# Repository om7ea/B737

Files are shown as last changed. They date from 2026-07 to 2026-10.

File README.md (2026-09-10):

# Boeing 737 Overhead Panel – Manufacturing Files

This repository contains supplementary manufacturing files for the corresponding MakerWorld project. Additional files and resources will be added gradually as new models are published on MakerWorld.

> **Note**
> This repository contains only supplementary manufacturing files. The 3D printable parts are available on MakerWorld - see the [model list](docs/models/README.md) for a link to each one.

## Photos

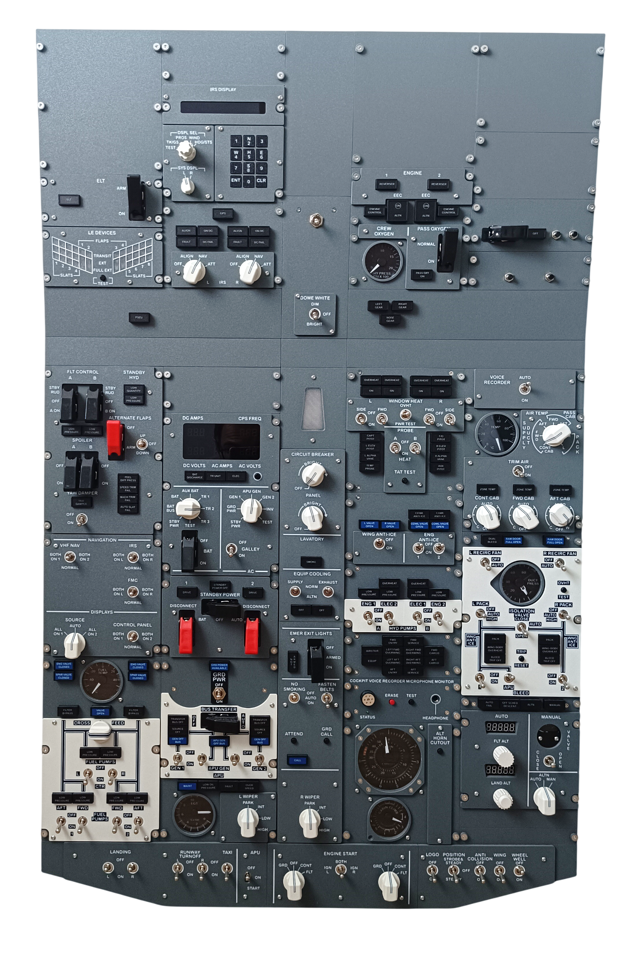
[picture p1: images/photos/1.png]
<span>
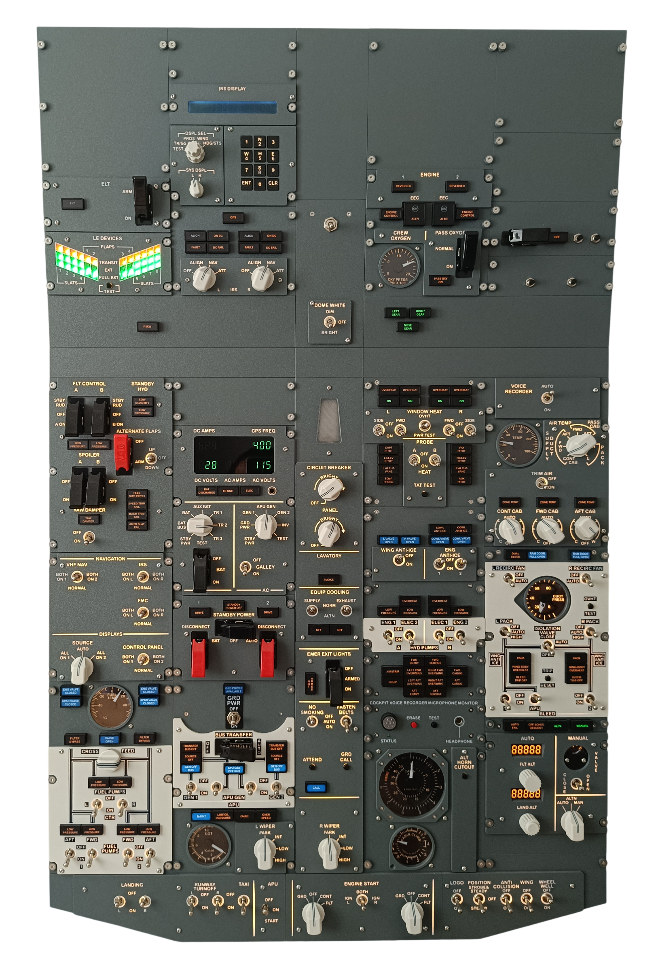
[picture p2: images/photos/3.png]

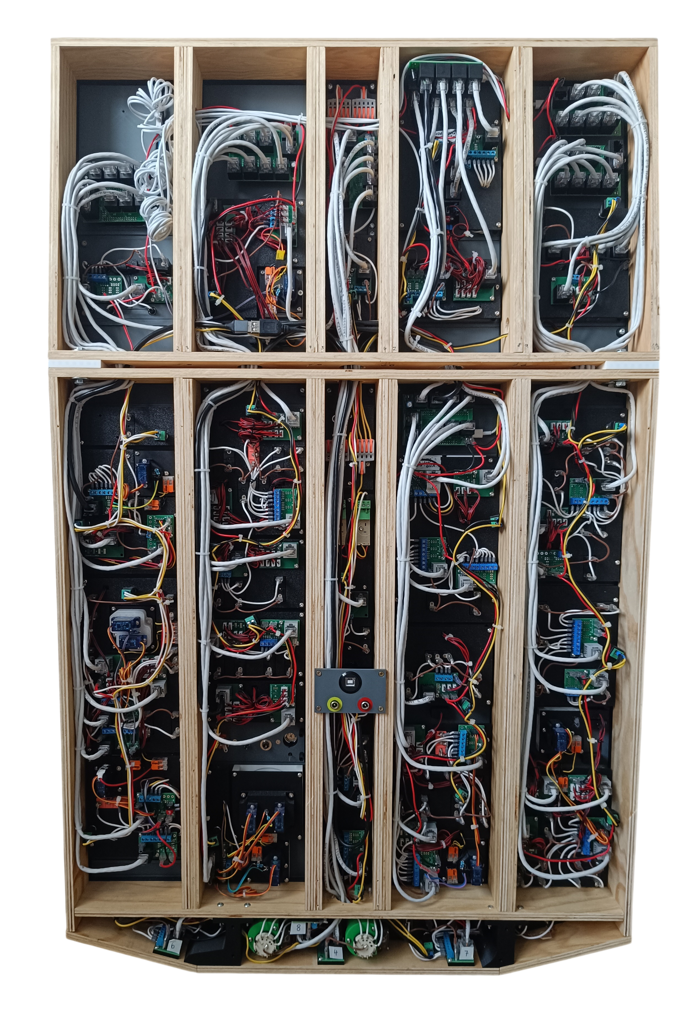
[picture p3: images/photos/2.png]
</span>

---

## How It Works

All electronics are enclosed inside the panel and connected to an internal USB hub, so the finished panel needs just **one USB cable to the PC** - plus its own power supplies.

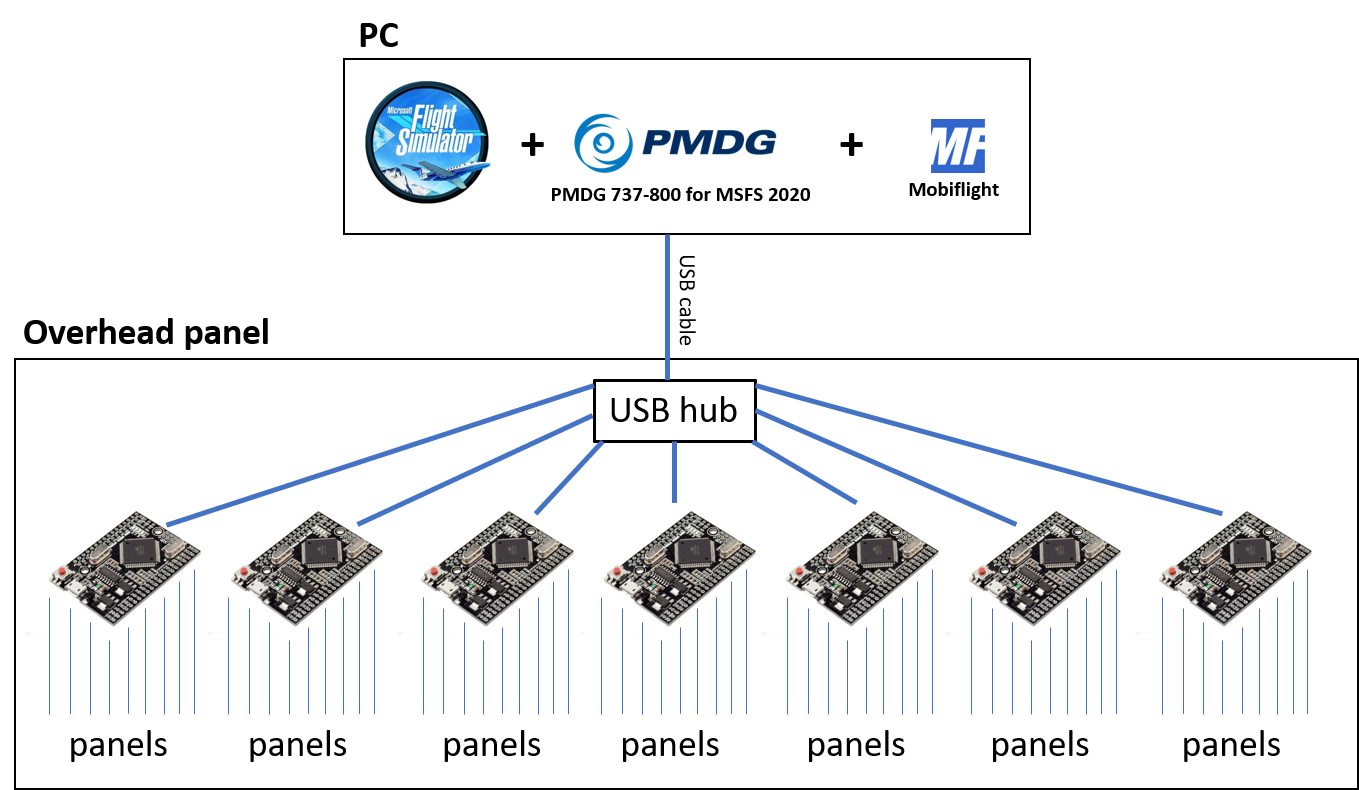
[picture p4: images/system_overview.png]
System overview diagram


**On the PC:** Microsoft Flight Simulator 2020 + PMDG 737-800 + MobiFlight. MobiFlight maps each switch, button and LED to a PMDG variable through its graphical interface, so **no programming is required**.

**Inside the panel:** 7× **Mega 2560 PRO MINI** boards, each driving one group of panels, all connected to an internal USB hub. Panels attach to the boards through RJ45 connectors using standard Ethernet patch cables.

**Power:** the panel is powered externally, not through the USB cable. It uses **two separate power supplies** - a **12 V** supply for the backlighting and a **5 V** supply for the rest of the electronics.

📖 **[Full system overview →](docs/system-overview.md)**

---

## Documentation

| | Contents |
|---|---|
| ⚙️ **[System Overview](docs/system-overview.md)** | How the panel connects to the simulator - software, boards, wiring |
| 🔌 **[PCB Manufacturing Files](docs/pcb/README.md)** | Gerber downloads, BOM and assembly for each PCB design |
| 🖨️ **[UV Print Files](docs/uv-print.md)** | Printable panel graphics and printing instructions |
| ✂️ **[CNC Cut Files](docs/cnc-cut.md)** | Acrylic windows for the gauges and the meter panel, with the DXF files |
| 🛩️ **[Models](docs/models/README.md)** | Build notes for the frame, the shared models and each panel |
| 🎨 **[Filaments](docs/filaments.md)** | The filaments I used and their colours |
| 🖥️ **[MobiFlight Configuration](docs/mobiflight.md)** | The complete MobiFlight configuration - board definitions and the simulator mapping |

---

## Support the Project

This project is completely free and will continue to be released free of charge.

Designing, testing, documenting, and maintaining the complete Boeing 737 Overhead Panel requires a significant amount of time. If you would like to support its continued development, you can make a voluntary contribution.

### How Your Support Helps

I'm saving for a ProSim737 license, a professional simulator software package that would greatly enhance my home cockpit. Every contribution brings me one step closer to reaching that goal.

✈️ **Support via PayPal:**
https://paypal.me/om7ea

Thank you to everyone who supports this project!

---

## License

This repository contains supplementary resources for the corresponding MakerWorld project.

### Files corresponding to the MakerWorld model

Files that are part of the corresponding MakerWorld model are distributed under the MakerWorld Standard Digital File License associated with that model. No additional rights are granted by this repository.

Please refer to the corresponding MakerWorld project page for the complete license terms.

### Repository-exclusive files

Some files in this repository are provided exclusively on GitHub and are not part of the MakerWorld model. Unless otherwise stated, these files are licensed separately and may not be copied, modified, redistributed, or used for commercial purposes without the author's prior written permission.

Copyright © 2026 Marek Antoška (OM7EA). All rights reserved.

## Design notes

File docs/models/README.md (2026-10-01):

# Models

Build notes for the individual models. The printable parts themselves are published on MakerWorld - the pages linked below contain the print settings and assembly instructions for each model.

[← Back to main page](../../README.md)

The models are listed in the order in which they were released on MakerWorld.

---

## Frame and Shared Models

These are not panels. The frame carries the whole overhead; the rest are components and instruments that go into the panels - some of them into several.

<table>
<thead>
<tr>
<th></th>
<th>Model</th>
<th>MakerWorld</th>
<th>Build notes</th>
</tr>
</thead>
<tbody>
<tr>
<td></td>
<td>Main Frame</td>
<td><a href="https://makerworld.com/en/models/3179915-boeing-737-overhead-frame">Model</a></td>
<td>🚧</td>
</tr>
</tbody>
<tbody>
<tr>
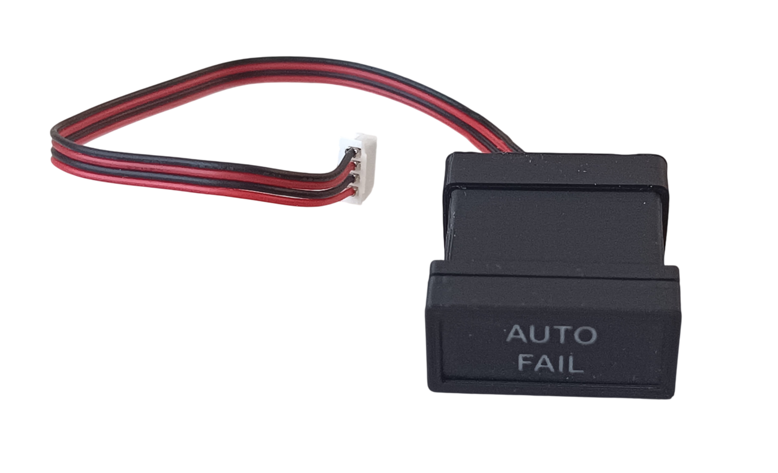
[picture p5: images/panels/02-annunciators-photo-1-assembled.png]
<td></td>
<td>Annunciators</td>
<td><a href="https://makerworld.com/en/models/3121595-boeing-737-overhead-annunciators">Model</a></td>
<td><a href="02-annunciators.md">Notes</a></td>
</tr>
</tbody>
<tbody>
<tr>
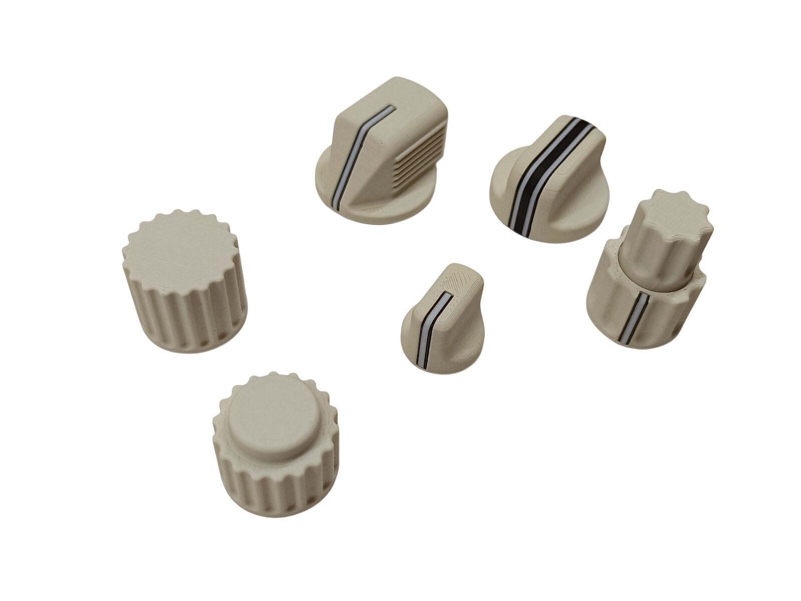
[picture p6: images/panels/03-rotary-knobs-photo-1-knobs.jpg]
<td></td>
<td>Rotary Knobs</td>
<td><a href="https://makerworld.com/en/models/3066127-boeing-737-overhead-rotary-knobs">Model</a></td>
<td><a href="03-rotary-knobs.md">Notes</a></td>
</tr>
</tbody>
<tbody>
<tr>
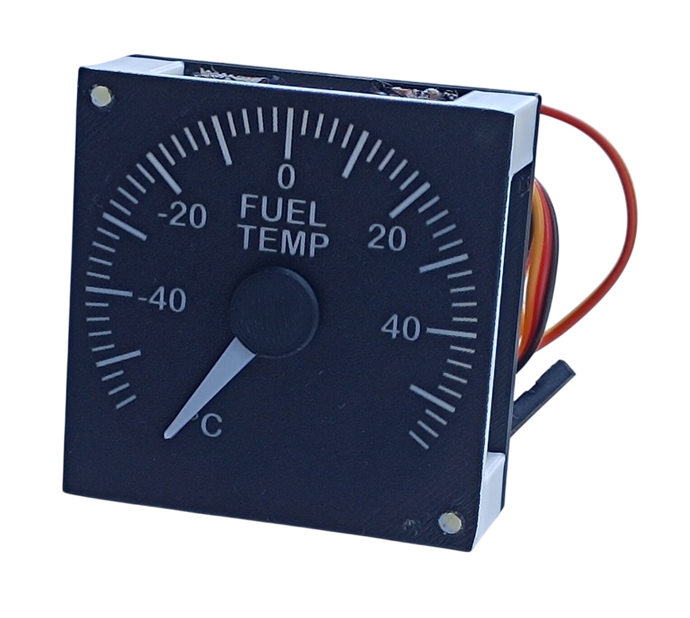
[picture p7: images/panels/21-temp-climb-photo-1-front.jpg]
<td></td>
<td>Temperature and Climb Gauges</td>
<td><a href="https://makerworld.com/en/models/3251829-boeing-737-overhead-temperature-and-climb-gauges">Model</a></td>
<td><a href="21-temperature-and-climb-gauges.md">Notes</a></td>
</tr>
</tbody>
<tbody>
<tr>
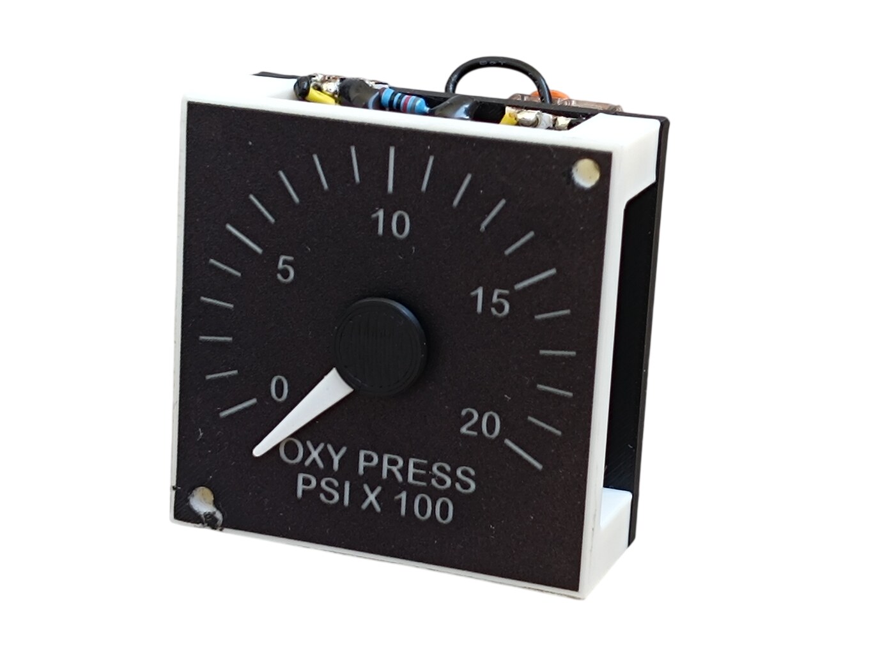
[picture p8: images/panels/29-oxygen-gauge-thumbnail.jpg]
<td></td>
<td>Oxygen Pressure Gauge</td>
<td><a href="https://makerworld.com/en/models/3309881-boeing-737-overhead-oxygen-pressure-gauge">Model</a></td>
<td><a href="29-oxygen-pressure-gauge.md">Notes</a></td>
</tr>
</tbody>
<tbody>
<tr>
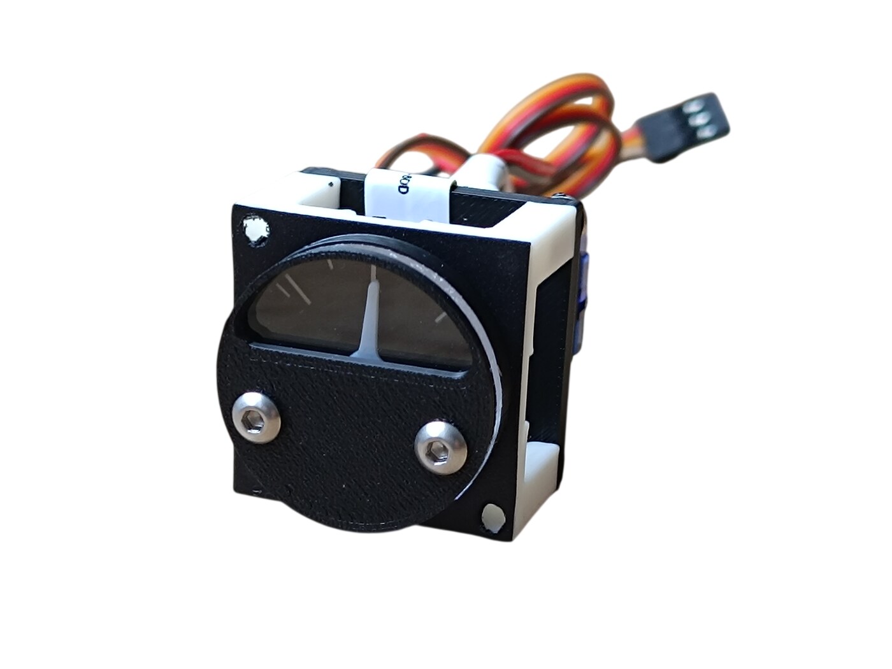
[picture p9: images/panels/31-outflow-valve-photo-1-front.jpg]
<td></td>
<td>Outflow Valve Gauge</td>
<td><a href="https://makerworld.com/en/models/3323749-boeing-737-overhead-outflow-valve-gauge">Model</a></td>
<td><a href="31-outflow-valve-gauge.md">Notes</a></td>
</tr>
</tbody>
<tbody>
<tr>
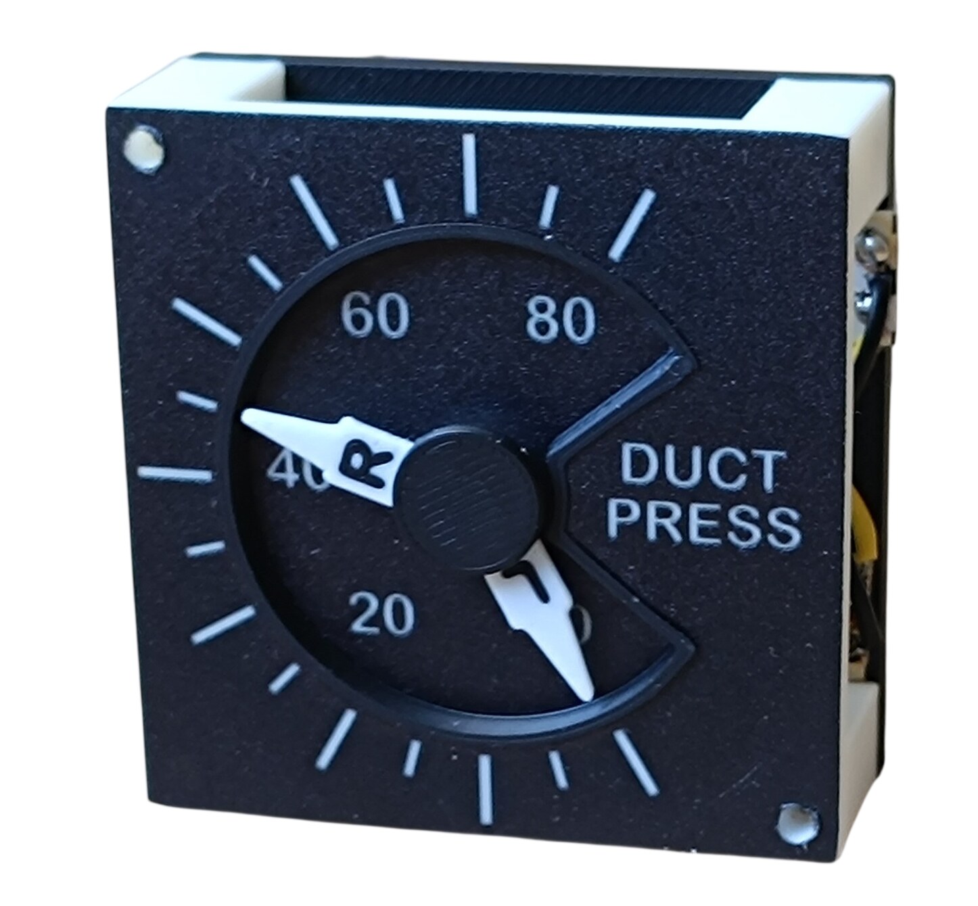
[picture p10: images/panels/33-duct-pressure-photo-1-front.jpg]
<td></td>
<td>Duct Pressure Gauge</td>
<td><a href="https://makerworld.com/en/models/3330434-boeing-737-overhead-duct-pressure-gauge">Model</a></td>
<td><a href="33-duct-pressure-gauge.md">Notes</a></td>
</tr>
</tbody>
<tbody>
<tr>
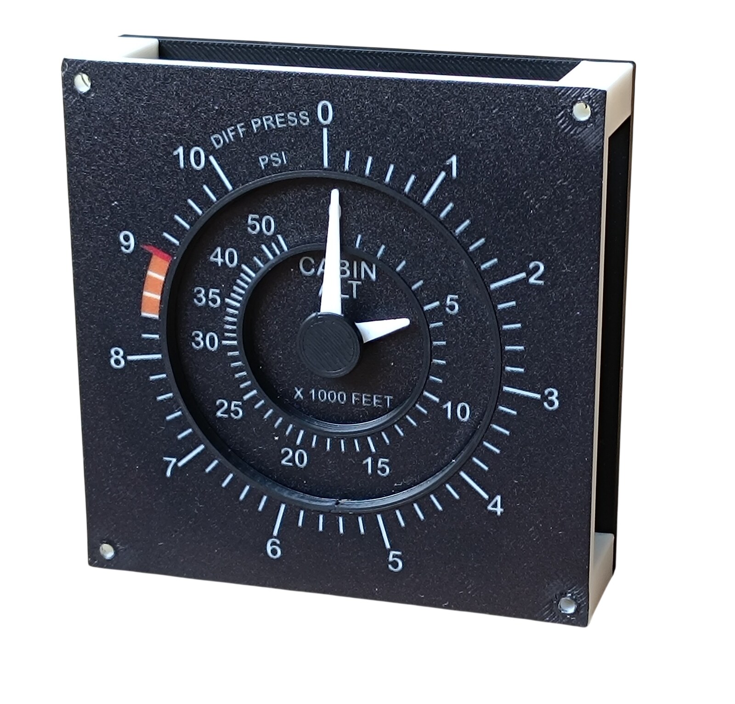
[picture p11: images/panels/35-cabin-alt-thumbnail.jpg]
<td></td>
<td>Cabin Alt / Diff Press Gauge</td>
<td><a href="https://makerworld.com/en/models/3334561-boeing-737-overhead-cabin-alt-diff-press-gauge">Model</a></td>
<td><a href="35-cabin-alt-diff-press-gauge.md">Notes</a></td>
</tr>
</tbody>
<tbody>
<tr>
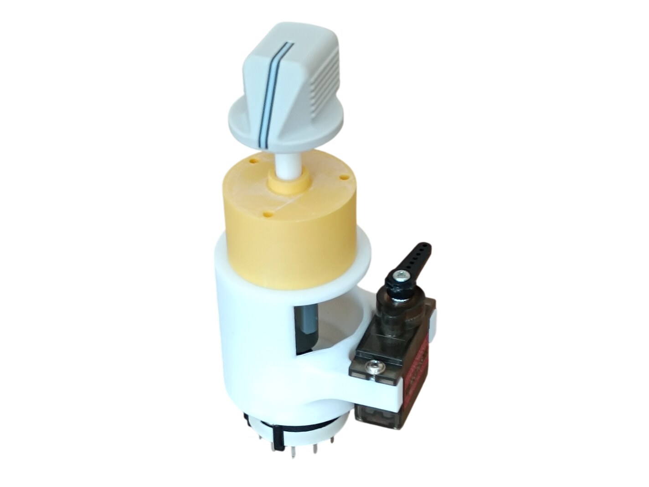
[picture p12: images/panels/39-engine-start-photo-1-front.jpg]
<td></td>
<td>Engine Start Switch</td>
<td><a href="https://makerworld.com/en/models/3375879-boeing-737-overhead-engine-start-switch">Model</a></td>
<td><a href="39-engine-start-switch.md">Notes</a></td>
</tr>
</tbody>
<tbody>
<tr>
<td></td>
<td>Backlight Blocking Strips</td>
<td>🚧</td>
<td>🚧</td>
</tr>
</tbody>
</table>

---

## Panels

<table>
<thead>
<tr>
<th></th>
<th>Panel</th>
<th>MakerWorld</th>
<th>Build notes</th>
</tr>
</thead>
<tbody>
<tr>
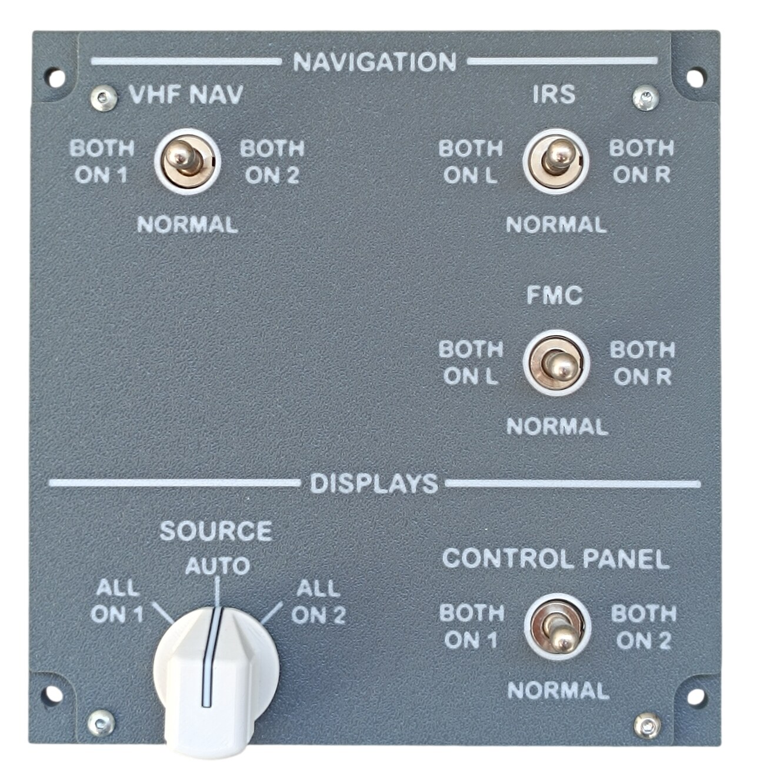
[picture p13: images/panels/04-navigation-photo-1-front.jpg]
<td></td>
<td>Navigation Panel</td>
<td><a href="https://makerworld.com/en/models/2985636-boeing-737-overhead-navigation-panel">Model</a></td>
<td><a href="04-navigation-panel.md">Notes</a></td>
</tr>
</tbody>
<tbody>
<tr>
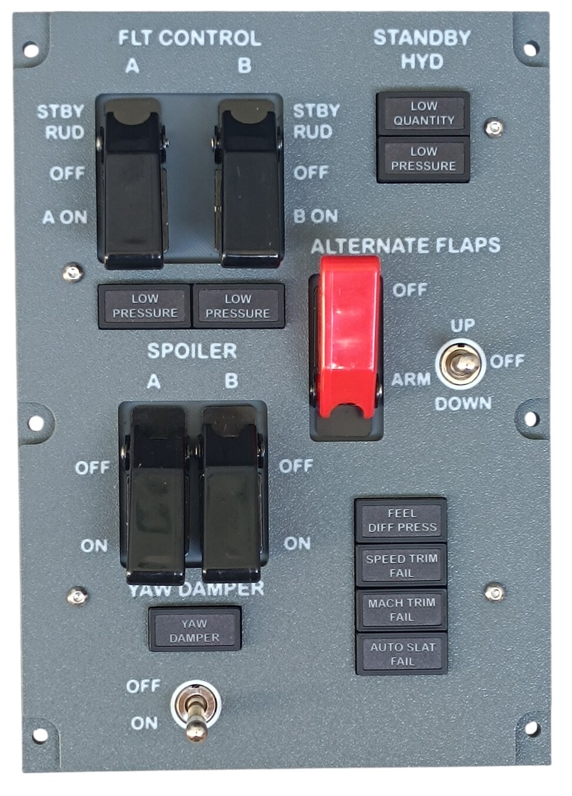
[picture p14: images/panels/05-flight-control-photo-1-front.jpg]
<td></td>
<td>Flight Control Panel</td>
<td><a href="https://makerworld.com/en/models/3153234-boeing-737-overhead-flight-control-panel">Model</a></td>
<td><a href="05-flight-control-panel.md">Notes</a></td>
</tr>
</tbody>
<tbody>
<tr>
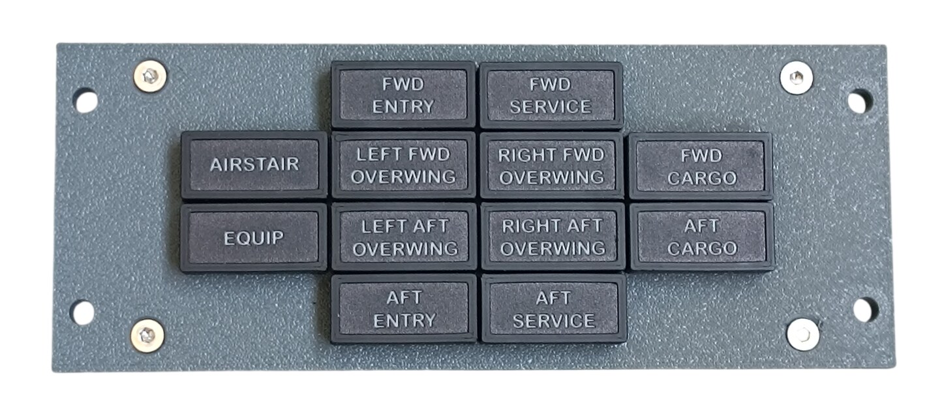
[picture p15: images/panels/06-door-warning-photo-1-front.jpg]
<td></td>
<td>Door Warning Panel</td>
<td><a href="https://makerworld.com/en/models/3163604-boeing-737-overhead-door-warning-panel">Model</a></td>
<td><a href="06-door-warning-panel.md">Notes</a></td>
</tr>
</tbody>
<tbody>
<tr>
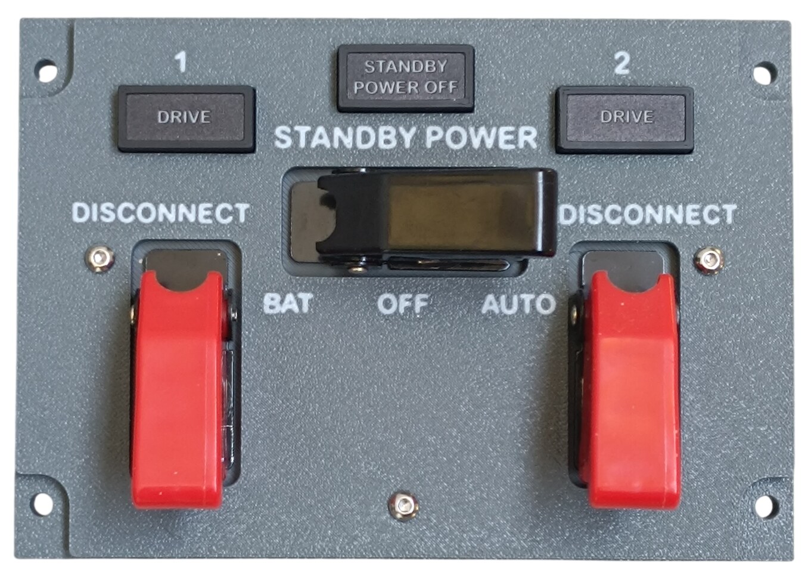
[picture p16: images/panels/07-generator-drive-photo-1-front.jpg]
<td></td>
<td>Generator Drive and Standby Power Panel</td>
<td><a href="https://makerworld.com/en/models/3163662-boeing-737-overhead-generator-drive-panel">Model</a></td>
<td><a href="07-generator-drive-panel.md">Notes</a></td>
</tr>
</tbody>
<tbody>
<tr>
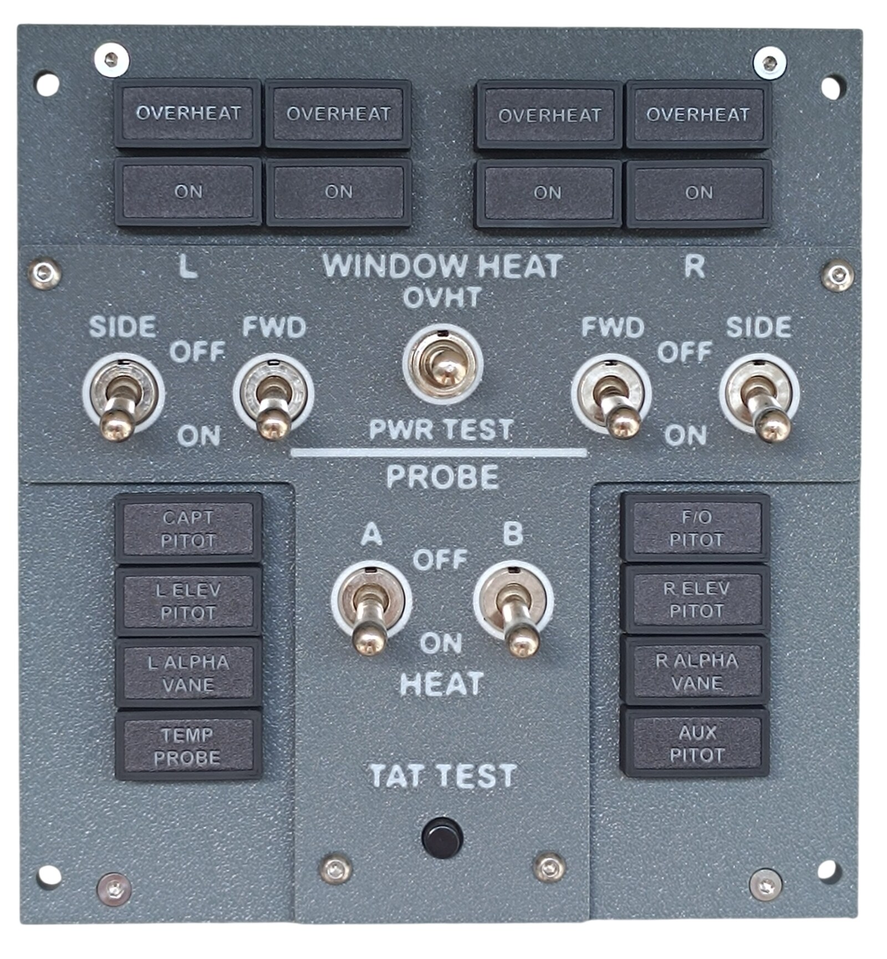
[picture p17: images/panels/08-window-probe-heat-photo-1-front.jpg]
<td></td>
<td>Window and Probe Heat Panel</td>
<td><a href="https://makerworld.com/en/models/3196345-boeing-737-overhead-window-and-probe-heat-panel">Model</a></td>
<td><a href="08-window-and-probe-heat-panel.md">Notes</a></td>
</tr>
</tbody>
<tbody>
<tr>
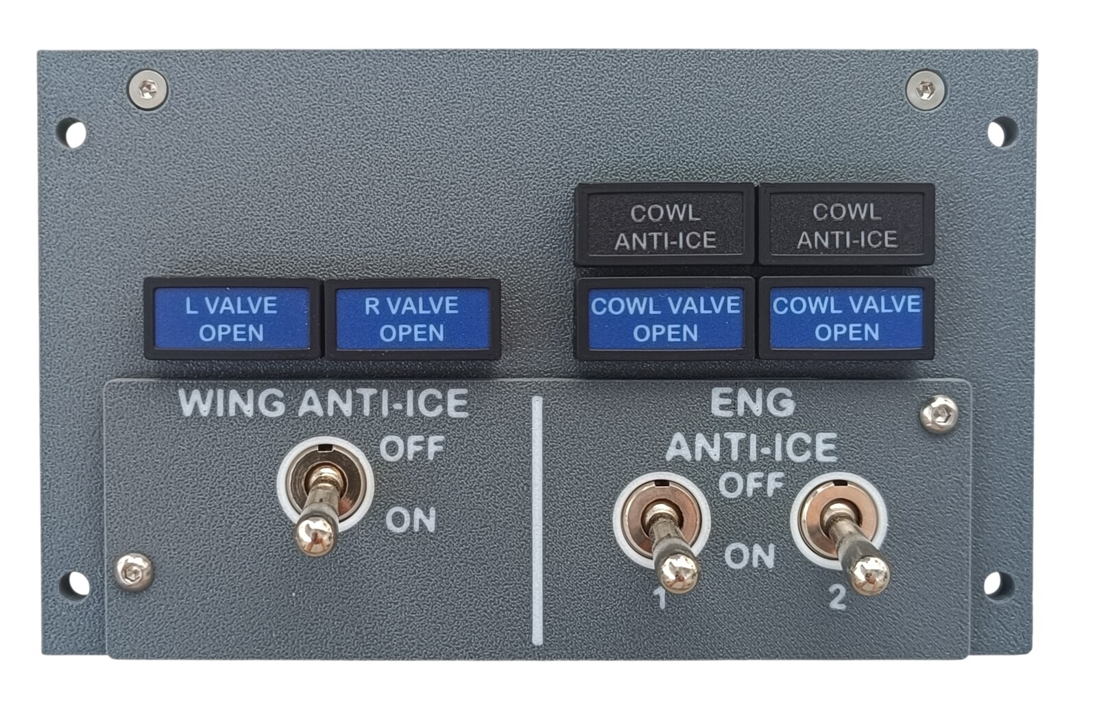
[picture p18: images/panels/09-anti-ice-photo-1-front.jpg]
<td></td>
<td>Anti-ice Panel</td>
<td><a href="https://makerworld.com/en/models/3197814-boeing-737-overhead-anti-ice-panel">Model</a></td>
<td><a href="09-anti-ice-panel.md">Notes</a></td>
</tr>
</tbody>
<tbody>
<tr>
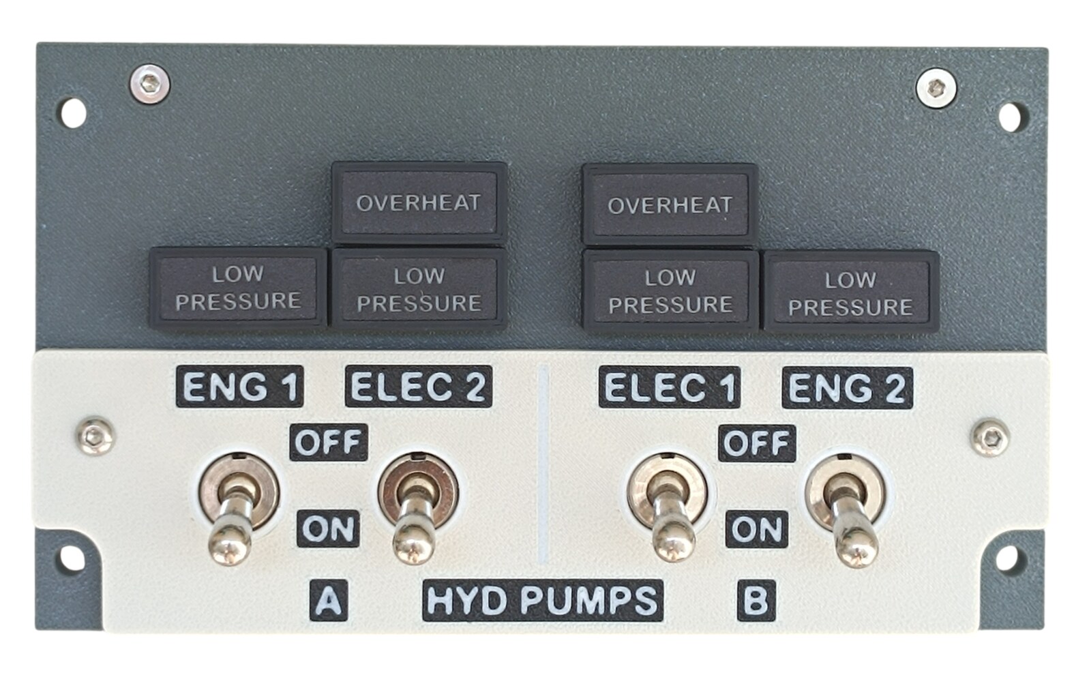
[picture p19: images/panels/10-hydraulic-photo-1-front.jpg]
<td></td>
<td>Hydraulic Control Panel</td>
<td><a href="https://makerworld.com/en/models/3212634-boeing-737-overhead-hydraulic-control-panel">Model</a></td>
<td><a href="10-hydraulic-control-panel.md">Notes</a></td>
</tr>
</tbody>
<tbody>
<tr>
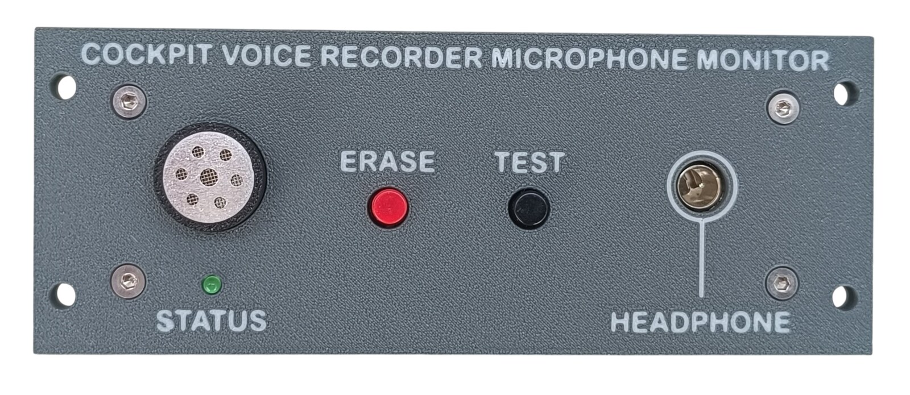
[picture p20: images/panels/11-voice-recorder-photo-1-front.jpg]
<td></td>
<td>Voice Recorder Monitor</td>
<td><a href="https://makerworld.com/en/models/3212900-boeing-737-overhead-voice-recorder-monitor">Model</a></td>
<td><a href="11-voice-recorder-monitor.md">Notes</a></td>
</tr>
</tbody>
<tbody>
<tr>
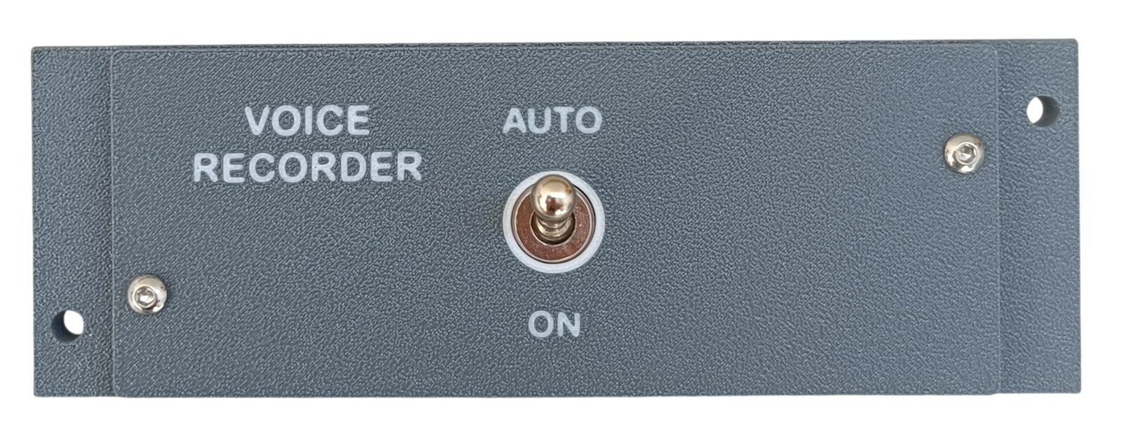
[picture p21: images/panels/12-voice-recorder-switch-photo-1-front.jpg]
<td></td>
<td>Voice Recorder Switch</td>
<td><a href="https://makerworld.com/en/models/3214222-boeing-737-overhead-voice-recorder-switch">Model</a></td>
<td><a href="12-voice-recorder-switch.md">Notes</a></td>
</tr>
</tbody>
<tbody>
<tr>
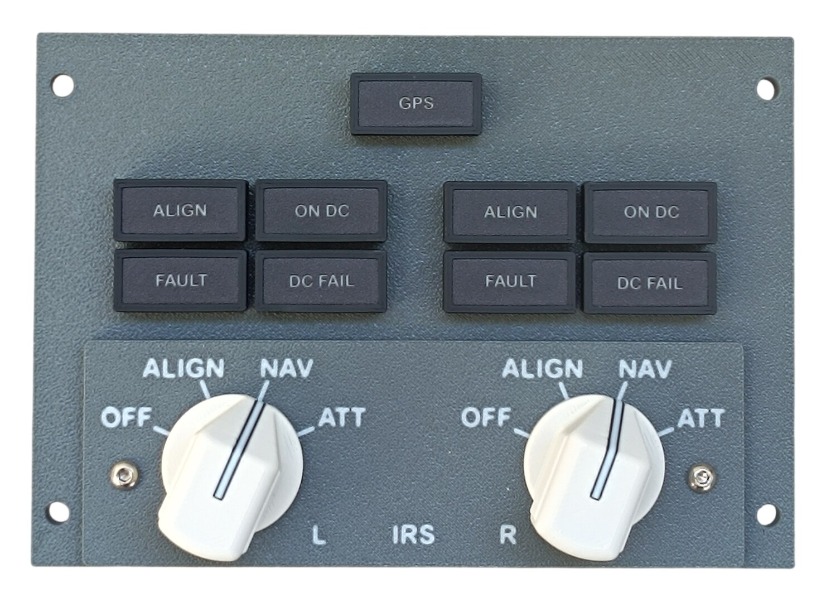
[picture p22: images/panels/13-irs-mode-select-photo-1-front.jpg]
<td></td>
<td>IRS Mode Select Unit</td>
<td><a href="https://makerworld.com/en/models/3214377-boeing-737-overhead-irs-mode-select-unit">Model</a></td>
<td><a href="13-irs-mode-select-unit.md">Notes</a></td>
</tr>
</tbody>
<tbody>
<tr>
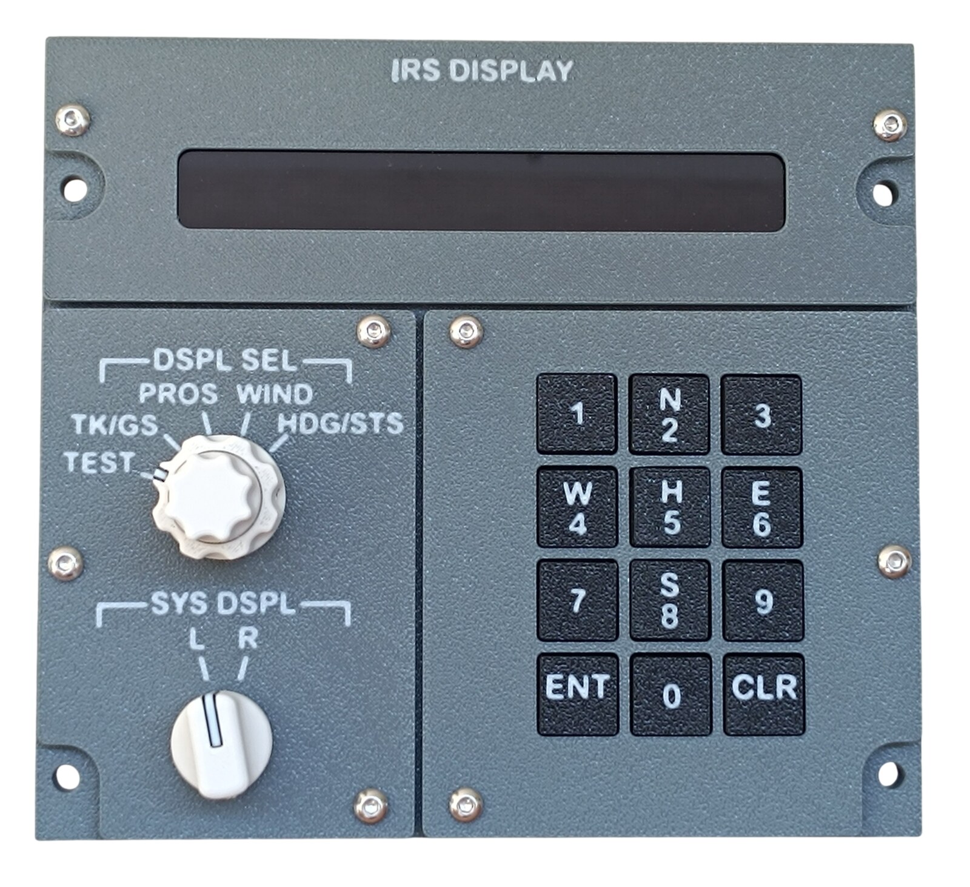
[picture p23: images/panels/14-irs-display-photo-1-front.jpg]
<td></td>
<td>IRS Display Unit</td>
<td><a href="https://makerworld.com/en/models/3222680-boeing-737-overhead-irs-display-unit">Model</a></td>
<td><a href="14-irs-display-unit.md">Notes</a></td>
</tr>
</tbody>
<tbody>
<tr>
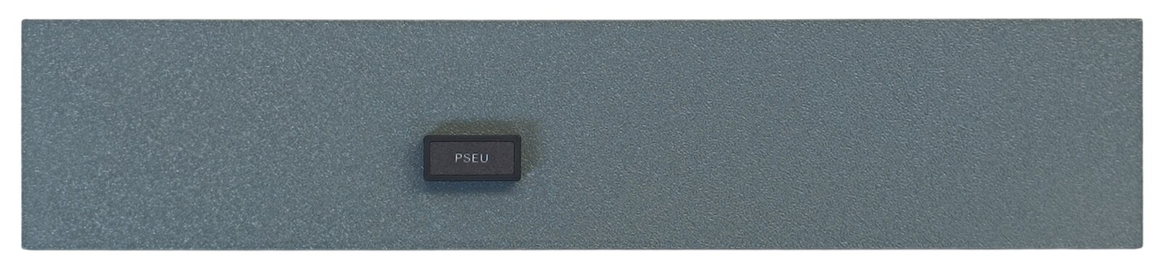
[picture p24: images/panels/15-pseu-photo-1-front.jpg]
<td></td>
<td>PSEU Panel</td>
<td><a href="https://makerworld.com/en/models/3223471-boeing-737-overhead-pseu-panel">Model</a></td>
<td><a href="15-pseu-panel.md">Notes</a></td>
</tr>
</tbody>
<tbody>
<tr>
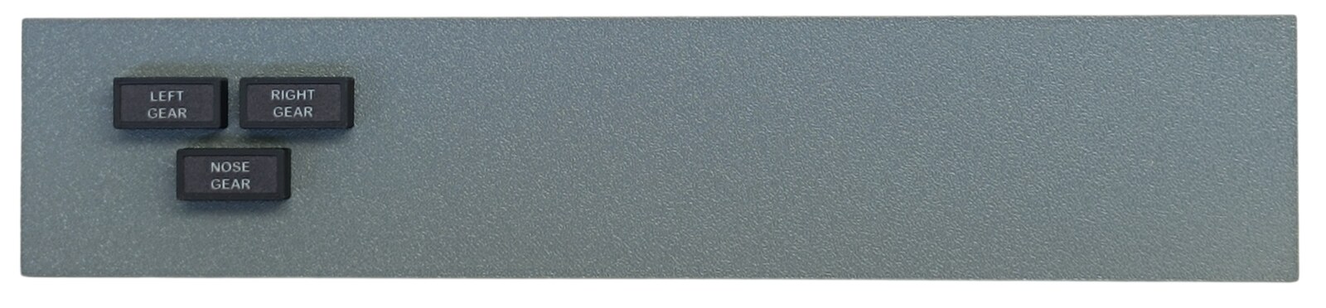
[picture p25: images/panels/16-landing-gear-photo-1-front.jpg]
<td></td>
<td>Landing Gear Indicator Panel</td>
<td><a href="https://makerworld.com/en/models/3223506-boeing-737-overhead-landing-gear-indicator-panel">Model</a></td>
<td><a href="16-landing-gear-indicator-panel.md">Notes</a></td>
</tr>
</tbody>
<tbody>
<tr>
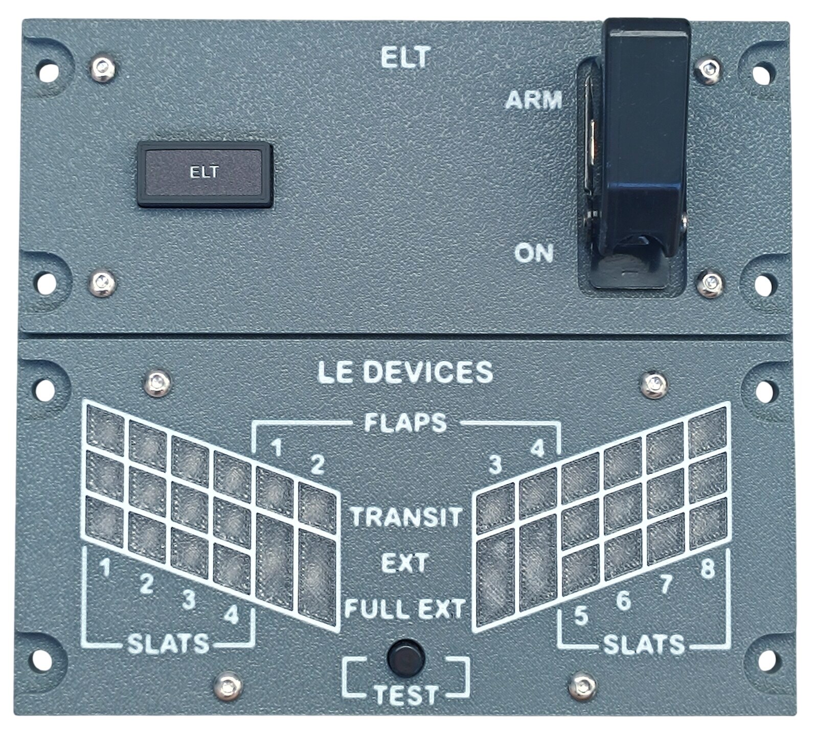
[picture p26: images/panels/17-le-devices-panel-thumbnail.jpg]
<td></td>
<td>LE Devices and ELT Panel</td>
<td><a href="https://makerworld.com/en/models/3233836-boeing-737-overhead-le-devices-and-elt-panel">Model</a></td>
<td><a href="17-le-devices-and-elt-panel.md">Notes</a></td>
</tr>
</tbody>
<tbody>
<tr>
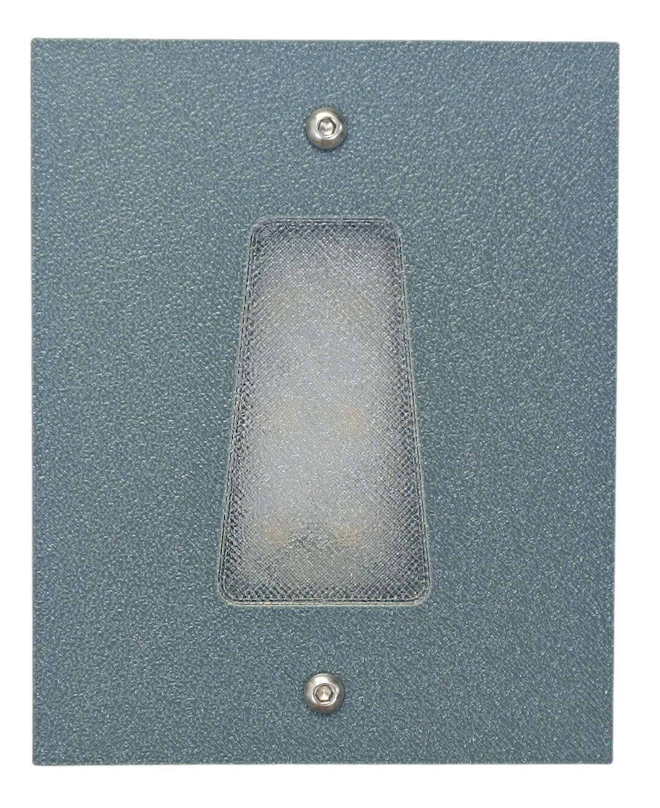
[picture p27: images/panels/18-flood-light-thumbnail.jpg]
<td></td>
<td>Flood Light</td>
<td><a href="https://makerworld.com/en/models/3237863-boeing-737-overhead-flood-light">Model</a></td>
<td><a href="18-flood-light.md">Notes</a></td>
</tr>
</tbody>
<tbody>
<tr>
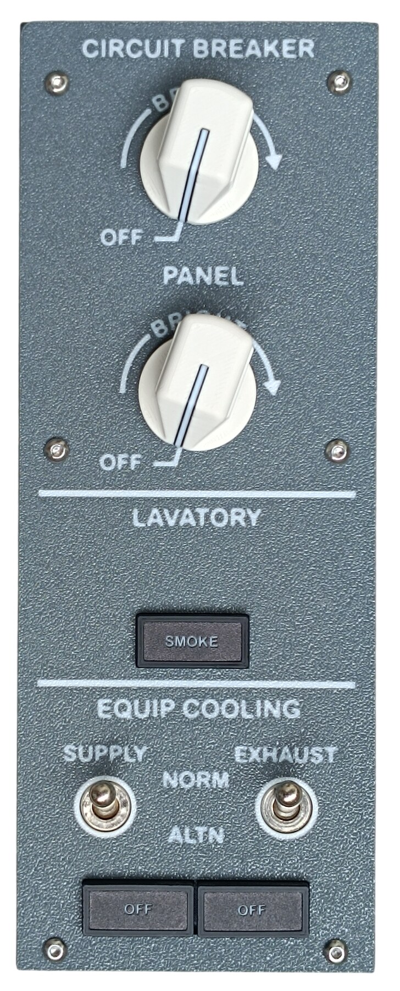
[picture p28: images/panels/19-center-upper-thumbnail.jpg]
<td></td>
<td>Center Upper Panel</td>
<td><a href="https://makerworld.com/en/models/3238245-boeing-737-overhead-center-upper-panel">Model</a></td>
<td><a href="19-center-upper-panel.md">Notes</a></td>
</tr>
</tbody>
<tbody>
<tr>
<td></td>
<td>Center Lower Panel</td>
<td><a href="https://makerworld.com/en/models/3238455-boeing-737-overhead-center-lower-panel">Model</a></td>
<td><a href="20-center-lower-panel.md">Notes</a></td>
</tr>
</tbody>
<tbody>
<tr>
<td></td>
<td>Fuel Control Panel</td>
<td><a href="https://makerworld.com/en/models/3260961-boeing-737-overhead-fuel-control-panel">Model</a></td>
<td><a href="22-fuel-control-panel.md">Notes</a></td>
</tr>
</tbody>
<tbody>
<tr>
<td></td>
<td>Generator Bus Panel</td>
<td><a href="https://makerworld.com/en/models/3275951-boeing-737-overhead-generator-bus-panel">Model</a></td>
<td><a href="23-generator-bus-panel.md">Notes</a></td>
</tr>
</tbody>
<tbody>
<tr>
<td></td>
<td>Air Conditioning Control Panel</td>
<td><a href="https://makerworld.com/en/models/3286939-boeing-737-overhead-air-conditioning-panel">Model</a></td>
<td><a href="24-air-conditioning-control-panel.md">Notes</a></td>
</tr>
</tbody>
<tbody>
<tr>
<td></td>
<td>Pressurization Altitude Info</td>
<td><a href="https://makerworld.com/en/models/3287240-boeing-737-overhead-pressurization-altitude-info">Model</a></td>
<td><a href="25-pressurization-altitude-info.md">Notes</a></td>
</tr>
</tbody>
<tbody>
<tr>
<td></td>
<td>AC and DC Meter Panel</td>
<td><a href="https://makerworld.com/en/models/3288999-boeing-737-overhead-ac-and-dc-meter-panel">Model</a></td>
<td><a href="26-ac-and-dc-meter-panel.md">Notes</a></td>
</tr>
</tbody>
<tbody>
<tr>
<td></td>
<td>Interphone and Dome Panel</td>
<td><a href="https://makerworld.com/en/models/3309341-boeing-737-overhead-interphone-and-dome-panel">Model</a></td>
<td><a href="27-interphone-and-dome-panel.md">Notes</a></td>
</tr>
</tbody>
<tbody>
<tr>
<td></td>
<td>Recorder and Stall Panel</td>
<td><a href="https://makerworld.com/en/models/3309626-boeing-737-overhead-recorder-and-stall-panel">Model</a></td>
<td><a href="28-recorder-and-stall-panel.md">Notes</a></td>
</tr>
</tbody>
<tbody>
<tr>
<td></td>
<td>Engine and Oxygen Panel</td>
<td><a href="https://makerworld.com/en/models/3311720-boeing-737-overhead-engine-and-oxygen-panel">Model</a></td>
<td><a href="30-engine-and-oxygen-panel.md">Notes</a></td>
</tr>
</tbody>
<tbody>
<tr>
<td></td>
<td>Cabin Pressure Control Panel</td>
<td><a href="https://makerworld.com/en/models/3324181-boeing-737-overhead-cabin-pressure-control-panel">Model</a></td>
<td><a href="32-cabin-pressure-control-panel.md">Notes</a></td>
</tr>
</tbody>
<tbody>
<tr>
<td></td>
<td>Bleed Air Control Panel</td>
<td><a href="https://makerworld.com/en/models/3332584-boeing-737-overhead-bleed-air-control-panel">Model</a></td>
<td><a href="34-bleed-air-control-panel.md">Notes</a></td>
</tr>
</tbody>
<tbody>
<tr>
<td></td>
<td>Cabin Altitude Panel</td>
<td><a href="https://makerworld.com/en/models/3342633-boeing-737-overhead-cabin-altitude-panel">Model</a></td>
<td><a href="36-cabin-altitude-panel.md">Notes</a></td>
</tr>
</tbody>
<tbody>
<tr>
<td></td>
<td>Left Light Panel</td>
<td><a href="https://makerworld.com/en/models/3350617-boeing-737-overhead-left-light-panel">Model</a></td>
<td><a href="37-left-light-panel.md">Notes</a></td>
</tr>
</tbody>
<tbody>
<tr>
<td></td>
<td>Right Light Panel</td>
<td><a href="https://makerworld.com/en/models/3350735-boeing-737-overhead-right-light-panel">Model</a></td>
<td><a href="38-right-light-panel.md">Notes</a></td>
</tr>
</tbody>
<tbody>
<tr>
<td></td>
<td>Engine Start Panel</td>
<td><a href="https://makerworld.com/en/models/3376922-boeing-737-overhead-engine-start-panel">Model</a></td>
<td><a href="40-engine-start-panel.md">Notes</a></td>
</tr>
</tbody>
<tbody>
<tr>
<td></td>
<td>FWD Blank Panels</td>
<td><a href="https://makerworld.com/en/models/3381374-boeing-737-overhead-fwd-blank-panels">Model</a></td>
<td><a href="41-fwd-blank-panels.md">Notes</a></td>
</tr>
</tbody>
<tbody>
<tr>
<td></td>
<td>AFT Blank Panels</td>
<td>🚧</td>
<td>🚧</td>
</tr>
</tbody>
<tbody>
<tr>
<td></td>
<td>Rear Power and USB Panel</td>
<td>🚧</td>
<td>🚧</td>
</tr>
</tbody>
</table>

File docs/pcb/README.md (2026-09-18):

# PCB Manufacturing Files (Gerber)

Every PCB design of the project. All Gerber files are ready to be uploaded directly to a PCB manufacturer.

> **This list is complete.** These nine designs cover the whole overhead, so everything can be ordered in one go.

[← Back to main page](../../README.md)

---

## Which PCB Do I Need?

<table>
<thead>
<tr>
<th></th>
<th>PCB</th>
<th>Qty needed</th>
<th>Purpose</th>
</tr>
</thead>
<tbody>
<tr>
<td></td>
<td><a href="annunciator.md"><strong>1. Annunciator</strong></a></td>
<td>125×</td>
<td>The illuminated push-button annunciators themselves</td>
</tr>
</tbody>
<tbody>
<tr>
<td></td>
<td><a href="rj45-direct.md"><strong>2. RJ45 Direct</strong></a></td>
<td>27×</td>
<td>Buttons, toggle switches, rotary switches, servos, displays</td>
</tr>
</tbody>
<tbody>
<tr>
<td></td>
<td><a href="rj45-driver.md"><strong>3. RJ45 LED Driver</strong></a></td>
<td>20×</td>
<td>Up to 8 annunciators, with a driver to offload the board</td>
</tr>
</tbody>
<tbody>
<tr>
<td></td>
<td><a href="rj45-combined.md"><strong>4. RJ45 Combined</strong></a></td>
<td>6×</td>
<td>4 driven annunciator channels + 4 direct connections</td>
</tr>
</tbody>
<tbody>
<tr>
<td></td>
<td><a href="rj45-hub-shield.md"><strong>5. RJ45 Hub Shield</strong></a></td>
<td>7×</td>
<td>Connects RJ45 cables to a MEGA 2560 PRO MINI</td>
</tr>
</tbody>
<tbody>
<tr>
<td></td>
<td><a href="irs-keyboard.md"><strong>6. IRS Keyboard</strong></a></td>
<td>1×</td>
<td>The 12-key keypad of the IRS Display Unit</td>
</tr>
</tbody>
<tbody>
<tr>
<td></td>
<td><a href="le-devices.md"><strong>7. LE Devices</strong></a></td>
<td>2×</td>
<td>The indicator lights of the LE Devices and ELT Panel</td>
</tr>
</tbody>
<tbody>
<tr>
<td></td>
<td><a href="ac-dc-meter.md"><strong>8. AC and DC Meter</strong></a></td>
<td>1×</td>
<td>The five digital displays of the AC and DC Meter Panel</td>
</tr>
</tbody>
<tbody>
<tr>
<td></td>
<td><a href="cabin-pressure-display.md"><strong>9. Cabin Pressure Display</strong></a></td>
<td>2×&nbsp;Board&nbsp;1&nbsp;(display)<br>2×&nbsp;Board&nbsp;2&nbsp;(MAX7219)</td>
<td>The FLT ALT and LAND ALT displays of the Cabin Pressure Control Panel</td>
</tr>
</tbody>
</table>

> **Note**
> The quantities listed for the individual PCBs are final, but I recommend ordering a few extra in case some are damaged during assembly.

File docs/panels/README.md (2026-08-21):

# Panels

Build notes for the individual panels. The printable models themselves are published on MakerWorld — the pages linked below contain the print settings and assembly instructions for each model.

[← Back to main page](../../README.md)

---

| | # | Panel | MakerWorld | Build notes |
|---|---:|---|---|---|
| | 1 | Main Frame | [Model](https://makerworld.com/en/models/3179915-boeing-737-overhead-frame) | 🚧 |
| | 2 | Annunciators | [Model](https://makerworld.com/en/models/3121595-boeing-737-overhead-annunciators) | [Notes](02-annunciators.md) |
| | 3 | Rotary Knobs | [Model](https://makerworld.com/en/models/3066127-boeing-737-overhead-rotary-knobs) | 🚧 |
| | 4 | Navigation Panel | [Model](https://makerworld.com/en/models/2985636-boeing-737-overhead-navigation-panel) | 🚧 |
| | 5 | Flight Control Panel | [Model](https://makerworld.com/en/models/3153234-boeing-737-overhead-flight-control-panel) | 🚧 |
|  | 6 | Door Warning Panel | [Model](https://makerworld.com/en/models/3163604-boeing-737-overhead-door-warning-panel) | [Notes](06-door-warning-panel.md) |
| | 7 | Generator Drive and Standby Power Panel | [Model](https://makerworld.com/en/models/3163662-boeing-737-overhead-generator-drive-panel) | 🚧 |
| | 8 | Window and Probe Heat Panel | [Model](https://makerworld.com/en/models/3196345-boeing-737-overhead-window-and-probe-heat-panel) | 🚧 |
|  | 9 | Anti-ice Panel | [Model](https://makerworld.com/en/models/3197814-boeing-737-overhead-anti-ice-panel) | [Notes](09-anti-ice-panel.md) |

More panels are currently in preparation.

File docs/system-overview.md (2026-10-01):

# System Overview

How the overhead panel connects to the simulator.

[← Back to main page](../README.md)

---

## The Idea

All electronics are enclosed inside the panel and connected to an internal USB hub, so the finished panel needs just **one USB cable to the PC** for all data. Power is supplied separately - see [Power supply](#power-supply) below.

System overview diagram

---

## Software (PC side)

| Component | Role |
|---|---|
| **Microsoft Flight Simulator 2020** | The simulator itself |
| **PMDG 737-800** | Aircraft model that exposes the real 737 systems and variables |
| **MobiFlight** | Bridges the hardware and the simulator - maps each switch, button and LED to a PMDG variable |

MobiFlight does the heavy lifting: switches and LEDs are configured in its graphical interface, so **no programming is required**. The boards run the standard MobiFlight firmware, which MobiFlight uploads for you when the board is first added.

The complete configuration - the board definitions and the mapping for every switch, button and LED - is published here: **[MobiFlight Configuration →](mobiflight.md)**

---

## Hardware (inside the panel)

| Component | Qty | Purpose | Reference |
|---|---:|---|---|
| **USB hub** | 1× | Connects all seven boards to the single USB cable. 7 ports, USB 3.0 | [Product I used](../images/parts/AE_usb_hub.png) |
| **USB cable** | 7× | Board to hub. USB-A to micro USB, 1 m; sold in packs - I bought 10 and used 7 | [Product I used](../images/parts/AE_usb_cable.png) |
| **MEGA 2560 PRO MINI** | 7× | Each board drives one group of panels. 5 V (embed), CH340G, ATmega2560-16AU; supplied with the male pin headers | [Product I used](../images/parts/AE_mega.png) |
| **RJ45 Hub Shield PCBs** | 7× | One per board - brings nine RJ45 sockets to the Mega 2560 | [PCB docs](pcb/rj45-hub-shield.md) |
| **Panels** | - | The overhead panels themselves. Each connects to a board with one or more Ethernet patch cables; new ones are released over time | [Models](models/README.md) |

Each Mega 2560 is registered in MobiFlight as a separate device, which keeps the configuration manageable and makes it easy to work on one section of the overhead at a time.

### The boards

The project uses **MEGA 2560 PRO MINI** boards - inexpensive third-party clones widely sold on AliExpress. They are built around the same **ATmega2560** microcontroller as the official Arduino Mega 2560 and behave identically, but they are *not* genuine Arduino products.

The **PRO MINI** form factor is what matters here: the board is a fraction of the size of a full Mega 2560 while keeping the full pin count, so all seven fit inside the overhead panel.

Where the seven boards sit inside the panel

Where the seven boards sit inside my panel, each with its RJ45 Hub Shield. Which board and which socket a panel connects to is in the **Wiring** section of that panel's [model page](models/README.md), and for all panels together in the [Socket map](#socket-map).

#### USB driver

The boards use a **CH340G** USB chip, not the one found on a genuine Arduino. On my PC, Windows recognised them without any extra steps: under **Ports (COM & LPT)** in Device Manager, each board shows up as **USB-SERIAL CH340 (COM*x*)**.

---

### Power supply

The panel does **not** draw its power from the USB cable. It is fed by **two separate external power supplies**:

| Supply | Powers | Measured draw | Recommended supply |
|---|---|---:|---:|
| **12 V** | Panel backlighting and the flood light | 2.5 A | 5 A |
| **5 V** | All other electronics - the Mega boards, annunciator LEDs, servos, displays | about 2 A | 4 A |

The USB cable therefore carries data only. This keeps the load off the PC's USB port, which matters with 125 annunciators in the finished panel.

The draw figures are the most I measured on my panel - the 12 V one with the backlight at full brightness. I recommend a supply with about twice that rating, so that it never runs at its limit.

> **⚠️ Cut the red wire in the USB cable to the PC**\
> The USB cable between the USB hub and the PC has to be modified. Strip back its outer sheath - there are four wires inside: red, black, white and green. **Cut the red wire** (+5 V) and leave the other three connected.
>
> The USB cable with its outer sheath stripped back and the red wire cut
>
> This is very important. The 5 V electronics can draw around 2 A. If you forget to connect the 5 V supply, the panel will try to draw that current from the PC through the USB cable, and that can destroy the USB port in your PC.

#### 12 V

The 12 V rail feeds the panel lighting only. It enters through a **DC socket on the back of the panel**, next to the 5 V socket and the USB connector, and goes first to two PWM dimmers:

| Dimmer | Controls |
|---|---|
| **Backlight** | The brightness of the whole overhead backlight |
| **Flood light** | The overhead flood light |

Both are ordinary PWM LED dimmers taken out of their housings. The board **and** its potentiometer are reused from each, so the two knobs on the [Center Upper Panel](models/19-center-upper-panel.md) are the original dimmer potentiometers; the two boards are screwed to the back of that panel. Its **PANEL** knob is the backlight dimmer and its **CIRCUIT BREAKER** knob the flood light one. On the real aircraft the CIRCUIT BREAKER knob sets the brightness of the circuit breaker panel, and the flood light is controlled from a panel outside the overhead - it drives the flood light here so that the knob and its dimmer are put to use.

> DC socket → **backlight dimmer** → **splice connectors** → **five branches**, one per column of panels → **DC plug** on each backlit panel

The backlight dimmer feeds a pair of lever-type splice connectors, one lever in and five out on each: one connector carries **+12 V** (yellow), the other **GND** (black). They are screwed to the back of the [Flood Light](models/18-flood-light.md) panel. The five branches that leave them each feed one column of panels. The flood light dimmer feeds the flood light directly, on a connector of its own.

How 12 V is distributed inside the panel

The 12 V distribution drawn over a photo of the panel from behind. Yellow is +12 V, black GND.

Every backlit panel takes its 12 V through a **DC plug with a screw terminal**, and so does the flood light. Each green circle on the drawing is one of these - there are **25** of them in the panel.

A green circle on the drawing is a DC plug with a screw terminal

The dimmers and the splice connectors close up

The middle of the drawing close up: the two splice connectors on top and the two dimmer boards below - flood light on the left, backlight on the right.

---

### Connection to panels

Panels attach to the boards through RJ45 connectors, using standard Ethernet patch cables. Three PCB variants cover the different needs:

- **RJ45 Direct** - buttons, toggle switches, rotary switches, servos, displays
- **RJ45 LED Driver** - up to 8 annunciators; the ULN2803 driver powers the LEDs so the board is not overloaded
- **RJ45 Combined** - 4 driven annunciator channels + 4 direct connections

At the board end the cables plug into an **RJ45 Hub Shield** - a shield that sits on top of the Mega 2560 PRO MINI and brings nine RJ45 sockets to it, so no panel cable has to be wired to the board pin by pin.

Connection chain from a panel to the PC

The chain for a single connection: panel PCB → Ethernet patch cable → MEGA 2560 PRO MINI with the RJ45 Hub Shield → micro USB cable → USB hub → PC. A panel may need more than one cable, and one board takes up to nine.

See [PCB Manufacturing Files](pcb/README.md) for details, BOM and wiring.

---

### Socket map

Which panel each socket of the seven RJ45 Hub Shields goes to. Each board is listed by its MobiFlight name, followed by the label it has in the [picture of the board positions](#the-boards). A dash marks a free socket.

#### Overhead_1a (mega 1a)

| Socket | Panel | PCB |
|---|---|---|
| D0 | [LE Devices and ELT Panel](models/17-le-devices-and-elt-panel.md) | [PCB 3](models/17-le-devices-and-elt-panel.md#pcb-3---socket-d0-on-overhead_1a) |
| D1 | [LE Devices and ELT Panel](models/17-le-devices-and-elt-panel.md) | [RJ45 2](models/17-le-devices-and-elt-panel.md#rj45-2---socket-d1-on-overhead_1a) |
| D2 | [LE Devices and ELT Panel](models/17-le-devices-and-elt-panel.md) | [RJ45 3](models/17-le-devices-and-elt-panel.md#rj45-3---socket-d2-on-overhead_1a) |
| D3 | [LE Devices and ELT Panel](models/17-le-devices-and-elt-panel.md) | [RJ45 4](models/17-le-devices-and-elt-panel.md#rj45-4---socket-d3-on-overhead_1a) |
| D4 | [Flight Control Panel](models/05-flight-control-panel.md) | [PCB 1](models/05-flight-control-panel.md#pcb-1---socket-d4-on-overhead_1a) |
| D5 | [Flight Control Panel](models/05-flight-control-panel.md) | [PCB 3](models/05-flight-control-panel.md#pcb-3---socket-d5-on-overhead_1a) |
| D6 | [Flight Control Panel](models/05-flight-control-panel.md) | [PCB 4](models/05-flight-control-panel.md#pcb-4---socket-d6-on-overhead_1a) |
| A1 | - | - |
| A2 | [LE Devices and ELT Panel](models/17-le-devices-and-elt-panel.md) | [RJ45 1](models/17-le-devices-and-elt-panel.md#rj45-1---socket-a2-on-overhead_1a) |

#### Overhead_1b (mega 1b)

| Socket | Panel | PCB |
|---|---|---|
| D0 | [Fuel Control Panel](models/22-fuel-control-panel.md) | [PCB 1](models/22-fuel-control-panel.md#pcb-1---socket-d0-on-overhead_1b) |
| D1 | [Fuel Control Panel](models/22-fuel-control-panel.md) | [PCB 2](models/22-fuel-control-panel.md#pcb-2---socket-d1-on-overhead_1b) |
| D2 | [Fuel Control Panel](models/22-fuel-control-panel.md) | [PCB 3](models/22-fuel-control-panel.md#pcb-3---socket-d2-on-overhead_1b) |
| D3 | [Fuel Control Panel](models/22-fuel-control-panel.md) | [PCB 4](models/22-fuel-control-panel.md#pcb-4---socket-d3-on-overhead_1b) |
| D4 | - | - |
| D5 | - | - |
| D6 | [Flight Control Panel](models/05-flight-control-panel.md) | [PCB 2](models/05-flight-control-panel.md#pcb-2---socket-d6-on-overhead_1b) |
| A1 | [Navigation Panel](models/04-navigation-panel.md) | [PCB 2](models/04-navigation-panel.md#pcb-2---socket-a1-on-overhead_1b) |
| A2 | [Navigation Panel](models/04-navigation-panel.md) | [PCB 1](models/04-navigation-panel.md#pcb-1---socket-a2-on-overhead_1b) |

#### Overhead_2a (mega 2a)

| Socket | Panel | PCB |
|---|---|---|
| D0 | [IRS Display Unit](models/14-irs-display-unit.md) | [PCB 1](models/14-irs-display-unit.md#pcb-1---socket-d0-on-overhead_2a) |
| D1 | [IRS Mode Select Unit](models/13-irs-mode-select-unit.md) | [PCB 2](models/13-irs-mode-select-unit.md#pcb-2---socket-d1-on-overhead_2a) |
| D2 | [IRS Mode Select Unit](models/13-irs-mode-select-unit.md) | [PCB 1](models/13-irs-mode-select-unit.md#pcb-1---socket-d2-on-overhead_2a) |
| D3 | [Engine and Oxygen Panel](models/30-engine-and-oxygen-panel.md) | [PCB 1](models/30-engine-and-oxygen-panel.md#pcb-1---socket-d3-on-overhead_2a) |
| D4 | [AC and DC Meter Panel](models/26-ac-and-dc-meter-panel.md) | [PCB 1](models/26-ac-and-dc-meter-panel.md#pcb-1---socket-d4-on-overhead_2a) |
| D5 | [Air Conditioning Control Panel](models/24-air-conditioning-control-panel.md) | [PCB 3](models/24-air-conditioning-control-panel.md#pcb-3---socket-d5-on-overhead_2a) |
| D6 | [AC and DC Meter Panel](models/26-ac-and-dc-meter-panel.md) | [PCB 4](models/26-ac-and-dc-meter-panel.md#pcb-4---socket-d6-on-overhead_2a) |
| A1 | [IRS Display Unit](models/14-irs-display-unit.md) | [RJ45 3](models/14-irs-display-unit.md#rj45-3---socket-a1-on-overhead_2a) |
| A2 | [IRS Display Unit](models/14-irs-display-unit.md) | [RJ45 2](models/14-irs-display-unit.md#rj45-2---socket-a2-on-overhead_2a) |

#### Overhead_2b (mega 2b)

| Socket | Panel | PCB |
|---|---|---|
| D0 | [Generator Bus Panel](models/23-generator-bus-panel.md) | [PCB 3](models/23-generator-bus-panel.md#pcb-3---socket-d0-on-overhead_2b) |
| D1 | [Generator Bus Panel](models/23-generator-bus-panel.md) | [PCB 1](models/23-generator-bus-panel.md#pcb-1---socket-d1-on-overhead_2b) |
| D2 | [Door Warning Panel](models/06-door-warning-panel.md) | [PCB 1](models/06-door-warning-panel.md#pcb-1---socket-d2-on-overhead_2b) |
| D3 | [Engine and Oxygen Panel](models/30-engine-and-oxygen-panel.md) | [PCB 2](models/30-engine-and-oxygen-panel.md#pcb-2---socket-d3-on-overhead_2b) |
| D4 | [AC and DC Meter Panel](models/26-ac-and-dc-meter-panel.md) | [PCB 2](models/26-ac-and-dc-meter-panel.md#pcb-2---socket-d4-on-overhead_2b) |
| D5 | [Generator Bus Panel](models/23-generator-bus-panel.md) | [PCB 4](models/23-generator-bus-panel.md#pcb-4---socket-d5-on-overhead_2b) |
| D6 | [Generator Bus Panel](models/23-generator-bus-panel.md) | [PCB 2](models/23-generator-bus-panel.md#pcb-2---socket-d6-on-overhead_2b) |
| A1 | [Generator Drive and Standby Power Panel](models/07-generator-drive-panel.md) | [PCB 1](models/07-generator-drive-panel.md#pcb-1---socket-a1-on-overhead_2b) |
| A2 | [AC and DC Meter Panel](models/26-ac-and-dc-meter-panel.md) | [PCB 3](models/26-ac-and-dc-meter-panel.md#pcb-3---socket-a2-on-overhead_2b) |

#### Overhead_3 (mega 3)

| Socket | Panel | PCB |
|---|---|---|
| D0 | [Recorder and Stall Panel](models/28-recorder-and-stall-panel.md) | [PCB 1](models/28-recorder-and-stall-panel.md#pcb-1---socket-d0-on-overhead_3) |
| D1 | [Interphone and Dome Panel](models/27-interphone-and-dome-panel.md) | [PCB 1](models/27-interphone-and-dome-panel.md#pcb-1---socket-d1-on-overhead_3) |
| D2 | [Center Lower Panel](models/20-center-lower-panel.md) | [PCB 1](models/20-center-lower-panel.md#pcb-1---socket-d2-on-overhead_3) |
| D3 | [Left Light Panel](models/37-left-light-panel.md) | [PCB 1](models/37-left-light-panel.md#pcb-1---socket-d3-on-overhead_3) |
| D4 | [Engine Start Panel](models/40-engine-start-panel.md) | [PCB 1](models/40-engine-start-panel.md#pcb-1---socket-d4-on-overhead_3) |
| D5 | [Right Light Panel](models/38-right-light-panel.md) | [PCB 1](models/38-right-light-panel.md#pcb-1---socket-d5-on-overhead_3) |
| D6 | [Engine Start Panel](models/40-engine-start-panel.md) | [PCB 2](models/40-engine-start-panel.md#pcb-2---socket-d6-on-overhead_3) |
| A1 | [Center Upper Panel](models/19-center-upper-panel.md) | [PCB 1](models/19-center-upper-panel.md#pcb-1---socket-a1-on-overhead_3) |
| A2 | [Center Lower Panel](models/20-center-lower-panel.md) | [PCB 2](models/20-center-lower-panel.md#pcb-2---socket-a2-on-overhead_3) |

#### Overhead_4 (mega 4)

| Socket | Panel | PCB |
|---|---|---|
| D0 | [Window and Probe Heat Panel](models/08-window-and-probe-heat-panel.md) | [PCB 3](models/08-window-and-probe-heat-panel.md#pcb-3---socket-d0-on-overhead_4) |
| D1 | [Anti-ice Panel](models/09-anti-ice-panel.md) | [PCB 1](models/09-anti-ice-panel.md#pcb-1---socket-d1-on-overhead_4) |
| D2 | [Anti-ice Panel](models/09-anti-ice-panel.md) | [PCB 2](models/09-anti-ice-panel.md#pcb-2---socket-d2-on-overhead_4) |
| D3 | [Cabin Altitude Panel](models/36-cabin-altitude-panel.md) | [PCB 1](models/36-cabin-altitude-panel.md#pcb-1---socket-d3-on-overhead_4) |
| D4 | [Hydraulic Control Panel](models/10-hydraulic-control-panel.md) | [PCB 2](models/10-hydraulic-control-panel.md#pcb-2---socket-d4-on-overhead_4) |
| D5 | [Door Warning Panel](models/06-door-warning-panel.md) | [PCB 2](models/06-door-warning-panel.md#pcb-2---socket-d5-on-overhead_4) |
| D6 | [Hydraulic Control Panel](models/10-hydraulic-control-panel.md) | [PCB 1](models/10-hydraulic-control-panel.md#pcb-1---socket-d6-on-overhead_4) |
| A1 | [Window and Probe Heat Panel](models/08-window-and-probe-heat-panel.md) | [PCB 1](models/08-window-and-probe-heat-panel.md#pcb-1---socket-a1-on-overhead_4) |
| A2 | [Window and Probe Heat Panel](models/08-window-and-probe-heat-panel.md) | [PCB 2](models/08-window-and-probe-heat-panel.md#pcb-2---socket-a2-on-overhead_4) |

#### Overhead_5 (mega 5)

| Socket | Panel | PCB |
|---|---|---|
| D0 | [Cabin Pressure Control Panel](models/32-cabin-pressure-control-panel.md) | [PCB 2](models/32-cabin-pressure-control-panel.md#pcb-2---socket-d0-on-overhead_5) |
| D1 | [Bleed Air Control Panel](models/34-bleed-air-control-panel.md) | [PCB 4](models/34-bleed-air-control-panel.md#pcb-4---socket-d1-on-overhead_5) |
| D2 | [Bleed Air Control Panel](models/34-bleed-air-control-panel.md) | [PCB 2](models/34-bleed-air-control-panel.md#pcb-2---socket-d2-on-overhead_5) |
| D3 | [Bleed Air Control Panel](models/34-bleed-air-control-panel.md) | [PCB 1](models/34-bleed-air-control-panel.md#pcb-1---socket-d3-on-overhead_5) |
| D4 | [Cabin Pressure Control Panel](models/32-cabin-pressure-control-panel.md) | [PCB 1](models/32-cabin-pressure-control-panel.md#pcb-1---socket-d4-on-overhead_5) |
| D5 | [Bleed Air Control Panel](models/34-bleed-air-control-panel.md) | [PCB 3](models/34-bleed-air-control-panel.md#pcb-3---socket-d5-on-overhead_5) |
| D6 | [Recorder and Stall Panel](models/28-recorder-and-stall-panel.md) | [PCB 2](models/28-recorder-and-stall-panel.md#pcb-2---socket-d6-on-overhead_5) |
| A1 | [Air Conditioning Control Panel](models/24-air-conditioning-control-panel.md) | [PCB 1](models/24-air-conditioning-control-panel.md#pcb-1---socket-a1-on-overhead_5) |
| A2 | [Air Conditioning Control Panel](models/24-air-conditioning-control-panel.md) | [PCB 2](models/24-air-conditioning-control-panel.md#pcb-2---socket-a2-on-overhead_5) |

---

## 🚧 To be documented

This section is still to be written:

- **5 V distribution** - how the 5 V is distributed inside the panel

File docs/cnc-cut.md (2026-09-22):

# CNC Cut Files

Acrylic windows for the gauges and for the AC and DC Meter Panel.

[← Back to main page](../README.md)

---

## Cuts

Five shapes, **nine pieces** in total. The drawings are zipped, because GitHub shows a bare `.dxf` as text instead of saving it.

<table>
<thead>
<tr>
<th></th>
<th>File</th>
<th>Size</th>
<th>Qty</th>
<th>Used on</th>
</tr>
</thead>
<tbody>
<tr>
<td align="center"></td>
<td><a href="https://raw.githubusercontent.com/om7ea/B737/main/docs/cnc_cut/cnc_gauge_48-8.zip"><b>cnc_gauge_48-8.dxf</b></a></td>
<td>Ø 48.8 mm</td>
<td align="right">5×</td>
<td>Fuel Control, Generator Bus, Air Conditioning Control, Cabin Altitude and Bleed Air Control panels</td>
</tr>
</tbody>
<tbody>
<tr>
<td align="center"></td>
<td><a href="https://raw.githubusercontent.com/om7ea/B737/main/docs/cnc_cut/cnc_gauge_78-9.zip"><b>cnc_gauge_78-9.dxf</b></a></td>
<td>Ø 78.9 mm</td>
<td align="right">1×</td>
<td><a href="models/35-cabin-alt-diff-press-gauge.md">Cabin Alt / Diff Press Gauge</a> on the <a href="models/36-cabin-altitude-panel.md">Cabin Altitude Panel</a></td>
</tr>
</tbody>
<tbody>
<tr>
<td align="center"></td>
<td><a href="https://raw.githubusercontent.com/om7ea/B737/main/docs/cnc_cut/cnc_gauge_43-8.zip"><b>cnc_gauge_43-8.dxf</b></a></td>
<td>Ø 43.8 mm</td>
<td align="right">1×</td>
<td><a href="models/30-engine-and-oxygen-panel.md">Engine and Oxygen Panel</a></td>
</tr>
</tbody>
<tbody>
<tr>
<td align="center"></td>
<td><a href="https://raw.githubusercontent.com/om7ea/B737/main/docs/cnc_cut/cnc_gauge_29-8.zip"><b>cnc_gauge_29-8.dxf</b></a></td>
<td>Ø 29.8 mm, with two Ø 3.3 mm holes 20 mm apart</td>
<td align="right">1×</td>
<td><a href="models/31-outflow-valve-gauge.md">Outflow Valve Gauge</a> on the <a href="models/32-cabin-pressure-control-panel.md">Cabin Pressure Control Panel</a></td>
</tr>
</tbody>
<tbody>
<tr>
<td align="center"></td>
<td><a href="https://raw.githubusercontent.com/om7ea/B737/main/docs/cnc_cut/cnc_meter_window.zip"><b>cnc_meter_window.dxf</b></a></td>
<td>96 × 46 mm, corners rounded to R 4.5 mm</td>
<td align="right">1×</td>
<td>AC and DC Meter Panel</td>
</tr>
</tbody>
</table>

Which instrument sits behind each of the round windows is on that panel's own page.

---

## Material

**Acrylic sheet between 2 and 3 mm** works for every piece. I used what I had on the shelf:

| Piece | Material I used |
|---|---|
| The four round gauge windows | **2 mm clear** |
| The meter panel window | **3 mm grey**, 65 % light transmission |

The grey sheet is what gives the meter panel window its dark, switched-off look while the instruments behind it still read clearly when lit.

---

## Cutting

I cut all nine pieces myself on my own CNC router.

The DXF files are drawn **1:1 in millimetres**.

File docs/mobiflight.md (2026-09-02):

# MobiFlight Configuration

The complete MobiFlight configuration for the overhead panel - the board definitions and the simulator mapping for every switch, button, LED, servo and display.

[← Back to main page](../README.md)

---

[📥 Download all configuration files - MobiFlight_Overhead.zip](https://raw.githubusercontent.com/om7ea/B737/main/MobiFlight/MobiFlight_Overhead.zip)

> **Read [Before you import](#before-you-import) first.** The configuration will not work on your hardware until you re-assign the boards - the files reference my boards by serial number.

---

## What Is In The Download

Eight files, all plain text - you can open any of them in a text editor.

| File | Format | Contents |
|---|---|---|
| `Overhead.mfproj` | MobiFlight Project (JSON) | The whole simulator mapping - 394 configurations |
| `Overhead_1a.mfmc` | Module Config (XML) | Board definition - which pin is a button, an LED, a servo |
| `Overhead_1b.mfmc` | Module Config (XML) | Board definition |
| `Overhead_2a.mfmc` | Module Config (XML) | Board definition |
| `Overhead_2b.mfmc` | Module Config (XML) | Board definition |
| `Overhead_3.mfmc` | Module Config (XML) | Board definition |
| `Overhead_4.mfmc` | Module Config (XML) | Board definition |
| `Overhead_5.mfmc` | Module Config (XML) | Board definition |

The two formats do different jobs and are used at different moments:

- A **`.mfmc`** file describes **the hardware on one board** - it is uploaded into the board's own memory, once, when you set the board up. Seven boards, seven files.
- The **`.mfproj`** file describes **what the hardware does in the simulator** - which PMDG variable each input triggers and which variable each LED follows. It stays on the PC and is opened in MobiFlight.

---

## Requirements

| | Requirement |
|---|---|
| **MobiFlight** | Version 11 or newer - the `.mfproj` project format does not exist in version 10 |
| **Simulator** | Microsoft Flight Simulator 2020 |
| **Aircraft** | PMDG 737-800. 295 of the input actions are PMDG event IDs, so the configuration is specific to this aircraft |
| **FSUIPC** | Required. Ten outputs read FSUIPC offsets directly and will stay dark without it |

---

## Before You Import

**MobiFlight identifies a board by its serial number, not by its name.** The files contain the serial numbers of my seven boards:

| Board | Serial number in the files |
|---|---|
| Overhead_1a | `SN-4F6-017` |
| Overhead_1b | `SN-7F0-2F8` |
| Overhead_2a | `SN-D8F-39D` |
| Overhead_2b | `SN-536-893` |
| Overhead_3 | `SN-9FB-4DA` |
| Overhead_4 | `SN-1FD-E25` |
| Overhead_5 | `SN-0F7-DFB` |

Your boards will have different serial numbers, so after opening the project **every configuration that drives hardware will show its board as missing**. This is expected and it is not a broken download. You have to point each configuration at your own board - MobiFlight can do this for a whole board at once, you do not have to edit 394 rows by hand.

Give your boards the same names (`Overhead_1a` … `Overhead_5`) before you start. It makes the re-assignment far easier to follow, because the board name is the only thing that connects a configuration to the hardware once the serial numbers no longer match.

---

## How To Import

1. **Set up the boards.** Connect one Mega 2560 PRO MINI, let MobiFlight upload its firmware, then load the matching `.mfmc` file into it and upload it to the board. Repeat for all seven. Do them one at a time - every board looks the same in the list until it has a name.
2. **Open the project.** `File → Open` and select `Overhead.mfproj`. All 394 configurations appear.
3. **Re-assign the boards.** See [Before you import](#before-you-import) above.
4. **Test without the simulator.** MobiFlight can send a test value to any output, which lights the LED on the desk. This is the fastest way to find a swapped patch cable before you go looking for the fault in the simulator.

---

## What The Configuration Contains

### Per board

| Board | Serial number | Configurations | Devices defined |
|---|---|---:|---|
| Overhead_1a | `SN-4F6-017` | 51 | 10× Button, 43× Output |
| Overhead_1b | `SN-7F0-2F8` | 35 | 20× Button, 18× Output, 1× Servo |
| Overhead_2a | `SN-D8F-39D` | 63 | 36× Button, 20× Output, 1× LED module, 1× Servo, 1× LCD display |
| Overhead_2b | `SN-536-893` | 67 | 38× Button, 27× Output, 2× Servo |
| Overhead_3 | `SN-9FB-4DA` | 53 | 45× Button, 5× Output, 2× Servo |
| Overhead_4 | `SN-1FD-E25` | 56 | 17× Button, 36× Output, 3× Servo |
| Overhead_5 | `SN-0F7-DFB` | 47 | 20× Button, 2× Encoder, 3× Analog input, 17× Output, 1× LED module, 3× Servo |

**Devices** are the physical things wired to a board, as defined in the `.mfmc` files - 372 in total. **Configurations** are the mappings in the project - 394 in total. The two numbers differ because one device can be used by more than one configuration: the two LED modules, for example, are driven by seven configurations between them, one per display field.

*Output* means a single LED channel - the annunciators. A toggle switch with a guard takes two Button entries, one for the switch and one for the guard.

### How inputs reach the simulator

| Action type | Count | |
|---|---:|---|
| PMDG event ID | 295 | The normal case - a switch fires the PMDG event for that lever |
| MSFS2020 custom input | 33 | For controls PMDG exposes as a custom event rather than an event ID |
| MobiFlight variable | 26 | Writes an internal variable, used where a control needs its own state |

A switch normally fires one action when it is pressed and another when it is released, so these counts are higher than the number of switches.

### How outputs read the simulator

| Source | Count | |
|---|---:|---|
| SimConnect | 173 | Reads a PMDG `L:` variable, e.g. `(L:switch_2256_73X, number)` |
| MobiFlight variable | 20 | Reads an internal variable set by an input |
| FSUIPC | 10 | Reads an FSUIPC offset directly |

---

## Notes

- **The configuration is complete.** It covers the whole overhead panel, including the panels whose models have not been published yet, and will not change as further models are released.
- **Panels are not split neatly one board per section.** The name of a configuration begins with the overhead section it belongs to (`Overhead_4_Oxygen panel_…`), which is *not* always the board that drives it - the Oxygen panel, for instance, is split between two boards. Which board drives a panel is in the **Wiring** section of that panel's [model page](models/README.md).
- **Twenty-two configurations have no board assigned.** This is intentional, not a gap. Sixteen of them are guarded switches: the physical switch writes an internal variable, and these entries turn that variable into the two PMDG events the guard and the lever need. The other six calculate a value that a servo or the IRS display then reads through a config reference - the two engine start servos, for example, take their position from them.

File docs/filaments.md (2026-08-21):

# Filaments I Used

[← Back to main page](../README.md)

---

| | Colour | Filament |
|---|---|---|
|  | Dark Gray | C-Tech Premium Line PLA RAL7011 |
|  | Transparent | Filament PM PLA Transparent |
|  | White | Bambu PLA Basic Jade White (10100) |
|  | Black | Bambu PLA Basic Black (10101) |
|  | Bone White | Bambu PLA Matte Bone White (11103) |

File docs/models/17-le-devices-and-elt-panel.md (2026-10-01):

# 17. LE Devices and ELT Panel

[📦 Download the printable model on MakerWorld](https://makerworld.com/en/models/3233836-boeing-737-overhead-le-devices-and-elt-panel)

[← Back to model list](README.md)

---

## Photos

<table>
<tbody>
<tr>
<td align="center" width="50%">Finished LE Devices and ELT Panel, front<br><sub>Finished panel</sub></td>
<td align="center" width="50%">The two printed top panels<br><sub>The two printed top panels</sub></td>
</tr>
</tbody>
<tbody>
<tr>
<td align="center" width="50%">Bottom panel with the diffusers fitted and the LEDs showing through<br><sub>Diffusers fitted and the LEDs showing through, before the top panels go on</sub></td>
<td align="center" width="50%">Rear of the bottom panel with the two LE Devices PCBs<br><sub>Rear of the bottom panel - the two LE Devices PCBs</sub></td>
</tr>
</tbody>
<tbody>
<tr>
<td align="center" width="50%">Rear of the finished panel with the backlight panel fitted<br><sub>Rear side - the backlight panel with the four RJ45 sockets and the Combined PCB</sub></td>
<td align="center" width="50%"></td>
</tr>
</tbody>
</table>

---

## Filament

| | Colour | Filament |
|---|---|---|
|  | Dark Gray | C-Tech Premium Line PLA RAL7011 |
|  | Transparent | Filament PM PLA Transparent |
|  | White | Bambu PLA Basic Jade White (10100) |
|  | Black | Bambu PLA Basic Black (10101) |

---

## 3D Printed Parts

| Qty | Part | Notes |
|---:|---|---|
| 2× | Top panel | print on a **Textured** PEI plate |
| 1× | Bottom panel | print on a **Textured** PEI plate |
| 2× | Diffuser panel | print on a **Smooth** PEI plate |
| 1× | Backlight panel | |
| 1× | PCB frame | |
| 8× | M4 washer | |
| 4× | Standoff 16 mm | |

---

## Switches and Buttons

| Qty | Type |
|---:|---|
| 1× | KN3(C)-101 or KN3(C)-102, ON/OFF |
| 1× | PBS-110 push button, black |
| 1× | Toggle switch safety aircraft guard, black |

The guard goes on the ELT switch, the push button is the LE DEVICES TEST button.

---

## Screws

| Qty | Screw | Joins |
|---:|---|---|
| 5× | Flat head M3×6 | bottom + diffuser |
| 4× | Flat head M3×12 | bottom + standoff |
| 8× | Flat head M4×16 | bottom + main frame |
| 2× | Dome head M3×5 | PCB + backlight |
| 18× | Dome head M3×8 | bottom + LE Devices PCB, top + bottom, backlight + standoff |

---

## Annunciators

| Qty | Type |
|---:|---|
| 1× | Black background, yellow LED |

The annunciators are a separate model shared with the other panels - they are **not included** in this download.

| | |
|---|---|
| 📦 Printable model | [Boeing 737 Overhead - Annunciators](https://makerworld.com/en/models/3121595-boeing-737-overhead-annunciators) |
| 🔧 Build notes | [Annunciators](02-annunciators.md) |
| 🔌 PCB, BOM and wiring | [Annunciator PCB](../pcb/annunciator.md) |

---

## PCB

| Qty | PCB | Connections used | Gerber files |
|---:|---|---|---|
| 2× | [LE Devices](../pcb/le-devices.md) | 16 LEDs and 2 RJ45 sockets each | [📥 PCB_LE_Devices.zip](https://raw.githubusercontent.com/om7ea/B737/main/PCB/PCB_LE_Devices.zip) |
| 1× | [RJ45 Combined](../pcb/rj45-combined.md) | headers 3–4, pins 5–6 | [📥 PCB_RJ45_Combined.zip](https://raw.githubusercontent.com/om7ea/B737/main/PCB/PCB_RJ45_Combined.zip) |

The two LE Devices boards carry the 32 indicator lamps of the display. They are the same board - the design is symmetrical and the second one is populated mirrored, for the other half of the panel. Read [LE Devices](../pcb/le-devices.md) before you solder them.

Mounting is shown in [step 3](#3-bottom-panel---le-devices-pcbs) and [step 5](#5-backlight-panel---combined-pcb-and-dc-jack) of the assembly diagram. Which lamp and which switch each connection carries is in [Wiring](#wiring).

---

## Wiring

Everything on this panel reaches the same MEGA 2560 - `Overhead_1a`. The panel takes **five** Ethernet patch cables to the [RJ45 Hub Shield](../pcb/rj45-hub-shield.md), because each of the two LE Devices boards has two RJ45 sockets of its own.

| Cable | Patch cable goes to | Connections used |
|---|---|---|
| **RJ45 1** | socket **A2** on **Overhead_1a** | headers 1–8 |
| **RJ45 2** | socket **D1** on **Overhead_1a** | headers 1–8 |
| **RJ45 3** | socket **D2** on **Overhead_1a** | headers 1–8 |
| **RJ45 4** | socket **D3** on **Overhead_1a** | headers 1–8 |
| **PCB 3** | socket **D0** on **Overhead_1a** | headers 3–4, pins 5–6 |

The socket labels **D0–D6**, **A1** and **A2** are silkscreened on the hub shield.

Rear of the panel with the four RJ45 sockets and the Combined PCB marked

The rear of the panel. **PCB 3** is the green board with the blue screw terminal. **RJ45 1** to **RJ45 4** are the sockets of the two LE Devices boards underneath - of those boards only the sockets and the Faston terminals show through the backlight panel.

The lamps are soldered into the LE Devices boards, so nothing on RJ45 1 to RJ45 4 can be connected the wrong way round. The four tables below are there for fault-finding.

### RJ45 1 - socket A2 on Overhead_1a

| Header | Lamp |
|---:|---|
| 1 | SLATS 6 - EXT |
| 2 | SLATS 6 - TRANSIT |
| 3 | SLATS 7 - FULL EXT |
| 4 | SLATS 7 - EXT |
| 5 | SLATS 7 - TRANSIT |
| 6 | SLATS 8 - FULL EXT |
| 7 | SLATS 8 - EXT |
| 8 | SLATS 8 - TRANSIT |

### RJ45 2 - socket D1 on Overhead_1a

| Header | Lamp |
|---:|---|
| 1 | LE FLAPS 3 - TRANSIT |
| 2 | LE FLAPS 3 - EXT |
| 3 | LE FLAPS 4 - EXT |
| 4 | LE FLAPS 4 - TRANSIT |
| 5 | SLATS 5 - FULL EXT |
| 6 | SLATS 5 - EXT |
| 7 | SLATS 5 - TRANSIT |
| 8 | SLATS 6 - FULL EXT |

### RJ45 3 - socket D2 on Overhead_1a

| Header | Lamp |
|---:|---|
| 1 | SLATS 4 - TRANSIT |
| 2 | SLATS 4 - EXT |
| 3 | SLATS 4 - FULL EXT |
| 4 | LE FLAPS 1 - TRANSIT |
| 5 | LE FLAPS 1 - EXT |
| 6 | LE FLAPS 2 - EXT |
| 7 | LE FLAPS 2 - TRANSIT |
| 8 | SLATS 3 - FULL EXT |

### RJ45 4 - socket D3 on Overhead_1a

| Header | Lamp |
|---:|---|
| 1 | SLATS 3 - EXT |
| 2 | SLATS 1 - TRANSIT |
| 3 | SLATS 1 - EXT |
| 4 | SLATS 1 - FULL EXT |
| 5 | SLATS 2 - TRANSIT |
| 6 | SLATS 2 - EXT |
| 7 | SLATS 2 - FULL EXT |
| 8 | SLATS 3 - TRANSIT |

### PCB 3 - socket D0 on Overhead_1a

This is the Combined PCB, so it carries both kinds of connection: the ZH headers drive annunciators, the screw terminals are direct.

| Header | Annunciator |
|---:|---|
| 3 | ELT |
| 4 | PSEU - **not on this panel**, see below |

| Pin | Switch |
|---:|---|
| 5 | ELT - ARM/ON |
| 6 | LE DEVICES TEST |

Headers 1 and 2 and pins 7 and 8 are not used.

**Header 4 serves a different panel.** It carries the single annunciator of the [PSEU Panel](15-pseu-panel.md), which has no PCB of its own.

> **Note**
> The ELT annunciator on header 3 and the ELT switch on pin 5 are wired, but they have no configuration in the [MobiFlight project](../mobiflight.md) - the PMDG 737-800 exposes no variable for the ELT. The lamp stays dark and the switch does nothing.

**The switch and the push button share a single ground return.** Each takes one of its terminals to its own pin. The opposite terminals are commoned - daisy-chained from one to the other - and the chain ends at a **-** (ground) contact.

---

## Backlight

| Qty | Part | Reference |
|---:|---|---|
| 4× | LED strip | [Product I used](../../images/parts/AE_led_strip.png) |
| 1× | DC jack 5.5 × 2.5 mm | [Product I used](../../images/parts/AE_dc_jack.png) |

Powered from the **12 V** supply - see [Power supply](../system-overview.md#power-supply).

---

## Assembly Diagram

Screw abbreviations used in the diagrams: **FH** = flat head, **DH** = dome head.

### 1. Bottom panel - diffusers, switch, button and standoffs

Bottom panel assembly

### 2. Top panels

The two top panels screwed to the bottom panel

### 3. Bottom panel - LE Devices PCBs

The two LE Devices PCBs screwed to the bottom panel

### 4. Backlight panel - LED strips

Backlight LED strips

### 5. Backlight panel - Combined PCB and DC jack

Backlight panel with the Combined PCB and the DC jack

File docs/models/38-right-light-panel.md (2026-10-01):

# 38. Right Light Panel

[📦 Download the printable model on MakerWorld](https://makerworld.com/en/models/3350735-boeing-737-overhead-right-light-panel)

[← Back to model list](README.md)

---

## Photos

<table>
<tbody>
<tr>
<td align="center" width="50%">Finished Right Light Panel, front<br><sub>Finished panel</sub></td>
<td align="center" width="50%">The printed top panel<br><sub>The top panel - Dark Gray with the lettering in Jade White</sub></td>
</tr>
</tbody>
<tbody>
<tr>
<td align="center" width="50%">The printed INDEX TO LOCK plate<br><sub>The index plate - Black with the lettering in Jade White</sub></td>
<td align="center" width="50%">The printed bottom panel<br><sub>The bottom panel - the opening is where the diffuser shows through</sub></td>
</tr>
</tbody>
<tbody>
<tr>
<td align="center" width="50%">The diffuser panel with the five switches fitted<br><sub>The diffuser panel with all five switches fitted</sub></td>
<td align="center" width="50%">Bottom panel with the diffuser and the switches fitted<br><sub>The diffuser and the switches in the bottom panel, before the top panel goes on</sub></td>
</tr>
</tbody>
<tbody>
<tr>
<td align="center" width="50%">Rear of the finished panel<br><sub>Rear side - the backlight panel, the DC jack and the PCB</sub></td>
<td align="center" width="50%"></td>
</tr>
</tbody>
</table>

---

## Filament

| | Colour | Filament |
|---|---|---|
|  | Dark Gray | C-Tech Premium Line PLA RAL7011 |
|  | Transparent | Filament PM PLA Transparent |
|  | White | Bambu PLA Basic Jade White (10100) |
|  | Black | Bambu PLA Basic Black (10101) |

---

## 3D Printed Parts

| Qty | Part | Notes |
|---:|---|---|
| 1× | Top panel | print on a **Textured** PEI plate |
| 1× | Bottom panel | print on a **Textured** PEI plate |
| 1× | Index plate | the INDEX TO LOCK plate at the right end; print on a **Textured** PEI plate |
| 1× | Diffuser panel | print on a **Smooth** PEI plate |
| 1× | Backlight panel | |
| 1× | PCB frame | |
| 4× | Standoff 16 mm | |
| 1× | Flat washer | goes under the screw that holds the index plate |

---

## Switches and Buttons

| Qty | Type |
|---:|---|
| 4× | KN3(C)-101, ON/OFF |
| 1× | KN3(C)-103, ON/OFF/ON |

The four two-position switches are LOGO, ANTI COLLISION, WING and WHEEL WELL. The three-position one is POSITION - STROBE & STEADY / OFF / STEADY.

---

## Screws

| Qty | Screw | Joins |
|---:|---|---|
| 3× | Flat head M3×12 | bottom + standoff |
| 2× | Dome head M3×5 | PCB + backlight |
| 8× | Dome head M3×8 | top + bottom, diffuser + standoff, backlight + standoff |
| 7× | Dome head M4×8 | bottom + main frame, index plate + bottom |

Three of the four standoffs are screwed to the bottom panel with the M3×12 screws; the fourth is screwed through the diffuser with M3×8.

---

## PCB

| Qty | PCB | Connections used | Gerber files |
|---:|---|---|---|
| 1× | [RJ45 Direct](../pcb/rj45-direct.md) | pins 1-6 | [📥 PCB_RJ45_Direct.zip](https://raw.githubusercontent.com/om7ea/B737/main/PCB/PCB_RJ45_Direct.zip) |

Mounting is shown in [step 3](#3-backlight-panel---pcb-and-dc-jack) of the assembly diagram. Which switch each connection carries is in [Wiring](#wiring).

---

## Wiring

The panel has a single PCB. It is connected by one Ethernet patch cable to a socket on the [RJ45 Hub Shield](../pcb/rj45-hub-shield.md).

| PCB | Patch cable goes to | Connections used |
|---|---|---|
| **PCB 1** | socket **D5** on **Overhead_3** | pins 1-6 |

The socket labels **D0-D6**, **A1** and **A2** are silkscreened on the hub shield.

Rear of the panel with the PCB marked

The rear of the panel. **PCB 1** is the only board, on its frame below the backlight panel; the DC jack sits at the far left of the same panel. The white wires run from the board up to the switches; the brown wire daisy-chains the opposite terminals of all five switches together.

### PCB 1 - socket D5 on Overhead_3

| Pin | Switch |
|---:|---|
| 1 | WHEEL WELL |
| 2 | WING |
| 3 | ANTI COLLISION |
| 4 | POSITION - STEADY |
| 5 | POSITION - STROBE & STEADY |
| 6 | LOGO |

Pins 7 and 8 are not used.

**All the switches share a single ground return.** Each switch takes one of its terminals to its own pin on the Direct PCB. The opposite terminals are commoned - daisy-chained from one switch to the next - and the chain ends at a **-** (ground) contact.

---

## Backlight

| Qty | Part | Reference |
|---:|---|---|
| 4× | LED strip | [Product I used](../../images/parts/AE_led_strip.png) |
| 1× | DC jack 5.5 × 2.5 mm | [Product I used](../../images/parts/AE_dc_jack.png) |

Powered from the **12 V** supply - see [Power supply](../system-overview.md#power-supply).

---

## Assembly Diagram

Screw abbreviations used in the diagrams: **FH** = flat head, **DH** = dome head.

### 1. Bottom panel - diffuser, index plate, switches and standoffs

Bottom panel with the diffuser, the index plate, the five switches and the standoffs

### 2. Backlight panel - LED strips

The four backlight LED strips

### 3. Backlight panel - PCB and DC jack

Backlight panel with the RJ45 Direct PCB and the DC jack

### 4. Top panel

The top panel screwed to the bottom panel

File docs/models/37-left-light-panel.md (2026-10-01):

# 37. Left Light Panel

[📦 Download the printable model on MakerWorld](https://makerworld.com/en/models/3350617-boeing-737-overhead-left-light-panel)

[← Back to model list](README.md)

---

## Photos

<table>
<tbody>
<tr>
<td align="center" width="50%">Finished Left Light Panel, front<br><sub>Finished panel</sub></td>
<td align="center" width="50%">The printed top panel<br><sub>The top panel - Dark Gray with the lettering in Jade White</sub></td>
</tr>
</tbody>
<tbody>
<tr>
<td align="center" width="50%">The printed INDEX TO LOCK plate<br><sub>The index plate - Black with the lettering in Jade White</sub></td>
<td align="center" width="50%">The printed bottom panel<br><sub>The bottom panel - the two openings are where the diffuser shows through</sub></td>
</tr>
</tbody>
<tbody>
<tr>
<td align="center" width="50%">The diffuser panel with the six switches fitted<br><sub>The diffuser panel with all six switches fitted</sub></td>
<td align="center" width="50%">Bottom panel with the diffuser and the switches fitted<br><sub>The diffuser and the switches in the bottom panel, before the top panel goes on</sub></td>
</tr>
</tbody>
<tbody>
<tr>
<td align="center" width="50%">Rear of the finished panel<br><sub>Rear side - the two backlight panels, the PCB and the switch wiring</sub></td>
<td align="center" width="50%"></td>
</tr>
</tbody>
</table>

---

## Filament

| | Colour | Filament |
|---|---|---|
|  | Dark Gray | C-Tech Premium Line PLA RAL7011 |
|  | Transparent | Filament PM PLA Transparent |
|  | White | Bambu PLA Basic Jade White (10100) |
|  | Black | Bambu PLA Basic Black (10101) |

---

## 3D Printed Parts

| Qty | Part | Notes |
|---:|---|---|
| 1× | Top panel | print on a **Textured** PEI plate |
| 1× | Bottom panel | print on a **Textured** PEI plate |
| 1× | Index plate | the INDEX TO LOCK plate at the left end; print on a **Textured** PEI plate |
| 1× | Diffuser panel | print on a **Smooth** PEI plate |
| 1× | Backlight panel 1 | the four-switch half |
| 1× | Backlight panel 2 | the two-switch half |
| 1× | PCB frame | |
| 7× | Standoff 16 mm | |
| 1× | Flat washer | goes under the screw that holds the index plate |

The diffuser is a single piece that runs the whole width of the panel. The bottom panel has two openings in it, so from the front the lit area looks like two separate windows.

---

## Switches and Buttons

| Qty | Type |
|---:|---|
| 5× | KN3(C)-101, ON/OFF |
| 1× | KN3(C)-113, ON/OFF/(ON) |

The five two-position switches are LANDING L and R, RUNWAY TURNOFF L and R, and TAXI. The three-position one is the APU switch - OFF / ON / START. Its middle position is the one marked ON, and START is spring-loaded, so the switch comes back to ON as soon as it is let go.

---

## Screws

| Qty | Screw | Joins |
|---:|---|---|
| 3× | Flat head M3×12 | bottom + standoff |
| 1× | Flat head M4×12 | bottom + main frame |
| 2× | Dome head M3×5 | PCB + backlight |
| 16× | Dome head M3×8 | top + bottom, diffuser + standoff, backlight + standoff |
| 7× | Dome head M4×8 | bottom + main frame, index plate + bottom |

Three of the seven standoffs are screwed to the bottom panel with the M3×12 screws; the other four are screwed through the diffuser with M3×8.

---

## PCB

| Qty | PCB | Connections used | Gerber files |
|---:|---|---|---|
| 1× | [RJ45 Direct](../pcb/rj45-direct.md) | pins 1-7 | [📥 PCB_RJ45_Direct.zip](https://raw.githubusercontent.com/om7ea/B737/main/PCB/PCB_RJ45_Direct.zip) |

Mounting is shown in [step 3](#3-backlight-panel---pcb-and-dc-jack) of the assembly diagram. Which switch each connection carries is in [Wiring](#wiring).

---

## Wiring

The panel has a single PCB. It is connected by one Ethernet patch cable to a socket on the [RJ45 Hub Shield](../pcb/rj45-hub-shield.md).

| PCB | Patch cable goes to | Connections used |
|---|---|---|
| **PCB 1** | socket **D3** on **Overhead_3** | pins 1-7 |

The socket labels **D0-D6**, **A1** and **A2** are silkscreened on the hub shield.

Rear of the panel with the PCB marked

The rear of the panel. **PCB 1** is the only board, on its frame below the backlight panel that carries four of the switches. The white wires run from the board's screw terminals up to the switches; the brown wire daisy-chains the opposite terminals of all six switches together.

### PCB 1 - socket D3 on Overhead_3

| Pin | Switch |
|---:|---|
| 1 | APU - START |
| 2 | APU - OFF |
| 3 | TAXI |
| 4 | RUNWAY TURNOFF R |
| 5 | RUNWAY TURNOFF L |
| 6 | LANDING R |
| 7 | LANDING L |

Pin 8 is not used.

**All the switches share a single ground return.** Each switch takes one of its terminals to its own pin on the Direct PCB. The opposite terminals are commoned - daisy-chained from one switch to the next - and the chain ends at a **-** (ground) contact.

---

## Backlight

| Qty | Part | Reference |
|---:|---|---|
| 5× | LED strip | [Product I used](../../images/parts/AE_led_strip.png) |
| 1× | DC jack 5.5 × 2.5 mm | [Product I used](../../images/parts/AE_dc_jack.png) |

Powered from the **12 V** supply - see [Power supply](../system-overview.md#power-supply).

One strip goes on the two-switch backlight panel and four on the four-switch one.

---

## Assembly Diagram

Screw abbreviations used in the diagrams: **FH** = flat head, **DH** = dome head.

### 1. Bottom panel - diffuser, index plate, switches and standoffs

Bottom panel with the diffuser, the index plate, the six switches and the standoffs

### 2. Backlight panels - LED strips

The five backlight LED strips on the two backlight panels

### 3. Backlight panel - PCB and DC jack

The two backlight panels screwed down, with the RJ45 Direct PCB and the DC jack

### 4. Top panel

The top panel screwed to the bottom panel

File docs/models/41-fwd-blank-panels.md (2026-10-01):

# 41. FWD Blank Panels

[📦 Download the printable model on MakerWorld](https://makerworld.com/en/models/3381374-boeing-737-overhead-fwd-blank-panels)

[← Back to model list](README.md)

---

## Photos

<table>
<tbody>
<tr>
<td align="center" width="50%">The four FWD blank panels, front<br><sub>The four blank panels</sub></td>
<td align="center" width="50%">Blank panel 4 from behind with the MEGA 2560 and the RJ45 Hub Shield<br><sub>Blank panel 4 from behind, with the MEGA 2560 and its RJ45 Hub Shield</sub></td>
</tr>
</tbody>
</table>

---

## Panel Positions

Where the four FWD blank panels sit in the overhead

---

## Filament

| | Colour | Filament |
|---|---|---|
|  | Dark Gray | C-Tech Premium Line PLA RAL7011 |

---

## 3D Printed Parts

| Qty | Part | Notes |
|---:|---|---|
| 1× | Blank FWD panel 1 | print on a **Textured** PEI plate |
| 1× | Blank FWD panel 2 | print on a **Textured** PEI plate |
| 1× | Blank FWD panel 3 | print on a **Textured** PEI plate |
| 1× | Blank FWD panel 4 | print on a **Textured** PEI plate |
| 4× | M4 washer | one under each M4×16 screw of panel 4 |

---

## Electronic Components

| Qty | Part | Reference |
|---:|---|---|
| 1× | **MEGA 2560 PRO MINI** | [The boards](../system-overview.md#the-boards) |

Panel 4 carries the board marked **mega 2b** in [The boards](../system-overview.md#the-boards) - `Overhead_2b` in MobiFlight - with its RJ45 Hub Shield plugged on top.

---

## Screws

| Qty | Screw | Joins |
|---:|---|---|
| 4× | Flat head M4×16 | panel 4 + main frame |
| 2× | Dome head M3×5 | MEGA 2560 + panel 4 |
| 10× | Dome head M4×10 | panels 1-3 + main frame |

---

## PCB

| Qty | PCB | Connections used | Gerber files |
|---:|---|---|---|
| 1× | [RJ45 Hub Shield](../pcb/rj45-hub-shield.md) | all nine sockets - D0-D6, A1 and A2 | [📥 PCB_RJ45_Hub_Shield.zip](https://raw.githubusercontent.com/om7ea/B737/main/PCB/PCB_RJ45_Hub_Shield.zip) |

The shield is fitted in [step 2](#2-mega-2560-and-rj45-hub-shield-on-panel-4) of the assembly diagram.

---

## Assembly Diagram

Screw abbreviations used in the diagrams: **FH** = flat head, **DH** = dome head.

### 1. Panels 1-3 onto the main frame

Blank panels 1 to 3 screwed to the main frame

### 2. MEGA 2560 and RJ45 Hub Shield on panel 4

MEGA 2560 screwed to panel 4 and the RJ45 Hub Shield plugged on top

### 3. Panel 4 onto the main frame

Blank panel 4 screwed to the main frame with four M4 washers

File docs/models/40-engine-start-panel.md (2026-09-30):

# 40. Engine Start Panel

[📦 Download the printable model on MakerWorld](https://makerworld.com/en/models/3376922-boeing-737-overhead-engine-start-panel)

[← Back to model list](README.md)

---

## Photos

<table>
<tbody>
<tr>
<td align="center" width="50%">Finished Engine Start Panel, front<br><sub>Finished panel</sub></td>
<td align="center" width="50%">The printed top panel<br><sub>The top panel - Dark Gray with the lettering in Jade White</sub></td>
</tr>
</tbody>
<tbody>
<tr>
<td align="center" width="50%">The printed bottom panel<br><sub>The bottom panel - the three openings are where the diffuser shows through</sub></td>
<td align="center" width="50%">The printed diffuser panel<br><sub>The diffuser panel</sub></td>
</tr>
</tbody>
<tbody>
<tr>
<td align="center" width="50%">Bottom panel with the diffuser, the toggle switch and the two Engine Start Switches fitted<br><sub>The diffuser, the toggle switch and the two Engine Start Switches in the bottom panel, before the top panel goes on</sub></td>
<td align="center" width="50%">Rear of the finished panel<br><sub>Rear side - the backlight panel, the two PCBs, the DC jack and the two Engine Start Switches with their servos</sub></td>
</tr>
</tbody>
<tbody>
<tr>
<td align="center" width="50%">Rear of the panel seen at an angle<br><sub>Rear side, seen at an angle</sub></td>
<td align="center" width="50%">Rear of the panel seen at an angle from the other edge<br><sub>Rear side, seen at an angle from the other edge</sub></td>
</tr>
</tbody>
</table>

---

## Filament

| | Colour | Filament |
|---|---|---|
|  | Dark Gray | C-Tech Premium Line PLA RAL7011 |
|  | Transparent | Filament PM PLA Transparent |
|  | White | Bambu PLA Basic Jade White (10100) |
|  | Black | Bambu PLA Basic Black (10101) |

---

## 3D Printed Parts

| Qty | Part | Notes |
|---:|---|---|
| 1× | Top panel | print on a **Textured** PEI plate |
| 1× | Bottom panel | print on a **Textured** PEI plate |
| 1× | Diffuser panel | print on a **Smooth** PEI plate |
| 1× | Backlight panel | |
| 2× | PCB frame | |
| 4× | Standoff 16 mm | |

---

## Switches and Buttons

| Qty | Type |
|---:|---|
| 1× | KN3(C)-103, ON/OFF/ON |

The toggle switch is the ignition selector - IGN L / BOTH / IGN R.

---

## Engine Start Switches

The two ENGINE START rotary switches are a separate model - they are **not included** in this download. Each one is a rotary switch with a servo that turns the knob back from GRD to OFF.

| | |
|---|---|
| 📦 Printable model | [Boeing 737 Overhead - Engine Start Switch](https://makerworld.com/en/models/3375879-boeing-737-overhead-engine-start-switch) |
| 🔧 Build notes | [Engine Start Switch](39-engine-start-switch.md) |

Both switches are in [Wiring](#wiring).

---

## Rotary Knobs

The knobs for the two Engine Start Switches are a separate model shared with the other panels - they are **not included** in this download.

| Qty | Part |
|---:|---|
| 2× | General knob, D shaft |
| 2× | General knob indicator |

| | |
|---|---|
| 📦 Printable model | [Boeing 737 Overhead - Rotary Knobs](https://makerworld.com/en/models/3066127-boeing-737-overhead-rotary-knobs) |
| 🔧 Build notes | [Rotary Knobs](03-rotary-knobs.md) |

---

## Screws

| Qty | Screw | Joins |
|---:|---|---|
| 4× | Flat head M3×12 | bottom + standoff |
| 4× | Dome head M3×5 | PCB + backlight |
| 15× | Dome head M3×8 | top + bottom, bottom + Engine Start Switch, backlight + standoff |
| 6× | Dome head M4×8 | bottom + main frame |

---

## PCB

| Qty | PCB | Connections used | Gerber files |
|---:|---|---|---|
| 2× | [RJ45 Direct](../pcb/rj45-direct.md) | pins 1-8 on one board, pins 5-8 on the other | [📥 PCB_RJ45_Direct.zip](https://raw.githubusercontent.com/om7ea/B737/main/PCB/PCB_RJ45_Direct.zip) |

Mounting is shown in [step 3](#3-backlight-panel---pcbs-and-dc-jack) of the assembly diagram. Which switch each connection carries is in [Wiring](#wiring).

---

## Wiring

The panel has two PCBs. Each one is connected by its own Ethernet patch cable to a socket on the [RJ45 Hub Shield](../pcb/rj45-hub-shield.md).

| PCB | Patch cable goes to | Connections used |
|---|---|---|
| **PCB 1** | socket **D4** on **Overhead_3** | pins 1-8 |
| **PCB 2** | socket **D6** on **Overhead_3** | pins 5-8 |

The socket labels **D0-D6**, **A1** and **A2** are silkscreened on the hub shield.

Rear of the panel with both PCBs marked

The rear of the panel. **PCB 1** sits on its frame at the bottom edge of the backlight panel, **PCB 2** on its frame at the top edge. The servo cables of both Engine Start Switches run to PCB 2.

### PCB 1 - socket D4 on Overhead_3

| Pin | Switch |
|---:|---|
| 1 | ENGINE START 2 - FLT |
| 2 | ENGINE START 2 - CONT |
| 3 | ENGINE START 2 - OFF |
| 4 | ENGINE START 2 - GRD |
| 5 | ENGINE START 1 - FLT |
| 6 | ENGINE START 1 - CONT |
| 7 | ENGINE START 1 - OFF |
| 8 | ENGINE START 1 - GRD |

### PCB 2 - socket D6 on Overhead_3

| Pin | Connection |
|---:|---|
| 5 | IGN R |
| 6 | IGN L |
| 7 | ENGINE START 1 - servo |
| 8 | ENGINE START 2 - servo |

Pins 1-4 are not used. The two servos plug onto the three-pin headers at positions 7 and 8, which carry the control signal, **+5 V** and **GND**.

> **⚠️ Both servo plugs have to be rewired**\
> The MG90S does not leave the factory in the order the RJ45 Direct PCB expects, so a servo will **not** work if you plug it in as it comes. **Swap the red and the orange wire:**
>
> | | Wire order in the plug |
> |---|---|
> | As delivered | brown - red - orange |
> | **Needed** | **brown - orange - red** |
>
> Lift the small tabs on the plastic housing, pull those two crimped contacts out and swap them over. Brown stays where it is.

**All the switches share a single ground return.** Each switch takes one of its terminals to its own pin on the Direct PCB. The opposite terminals are commoned - daisy-chained from one switch to the next - and the chain ends at a **-** (ground) contact.

---

## Backlight

| Qty | Part | Reference |
|---:|---|---|
| 5× | LED strip | [Product I used](../../images/parts/AE_led_strip.png) |
| 1× | DC jack 5.5 × 2.5 mm | [Product I used](../../images/parts/AE_dc_jack.png) |

Powered from the **12 V** supply - see [Power supply](../system-overview.md#power-supply).

---

## Assembly Diagram

Screw abbreviations used in the diagrams: **FH** = flat head, **DH** = dome head.

### 1. Bottom panel - switches and standoffs

Bottom panel with the toggle switch, the two Engine Start Switches and the standoffs

### 2. Backlight panel - LED strips

The five backlight LED strips

### 3. Backlight panel - PCBs and DC jack

Backlight panel with the two RJ45 Direct PCBs and the DC jack

### 4. Top panel

The top panel screwed to the bottom panel

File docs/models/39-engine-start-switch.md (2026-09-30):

# 39. Engine Start Switch

[📦 Download the printable model on MakerWorld](https://makerworld.com/en/models/3375879-boeing-737-overhead-engine-start-switch)

[← Back to model list](README.md)

---

> **Note**
> **Two** are needed for the complete project, both on the **[Engine Start Panel](40-engine-start-panel.md)** - one for each engine.

---

## Photos

<table>
<tbody>
<tr>
<td align="center" width="50%">Finished Engine Start Switch with its knob and servo<br><sub>The finished switch, with its knob fitted</sub></td>
</tr>
</tbody>
</table>

---

## How It Works

The knob turns a **rotary switch RS26** through two printed rods, set to the four positions **GRD / OFF / CONT / FLT**. A spring keeps the knob pulled out, and out of **OFF** it can only be turned after it has been **pushed in** - without pushing, it does not turn.

An **MG90S servo** beside the switch turns the knob back from **GRD** to **OFF** once the simulator releases the starter, the way the real aircraft does it.

---

## 3D Printed Parts

| Per switch | Total for 2 | Part |
|---:|---:|---|
| 1× | 2× | top case |
| 1× | 2× | top rod |
| 1× | 2× | bottom case |
| 1× | 2× | bottom case cover |
| 1× | 2× | bottom rod |

The colour of the filament and the type of the build plate are up to you - the whole switch is hidden behind the panel.

---

## Switches and Buttons

| Per switch | Total for 2 | Type |
|---:|---:|---|
| 1× | 2× | Rotary switch RS26, 12 positions |

The RS26 has an adjustable end stop - set it to **4** positions.

---

## Electronic and Mechanical Components

| Per switch | Total for 2 | Part | Reference |
|---:|---:|---|---|
| 1× | 2× | **Servo MG90S** - 180°, metal gears | [Product I used](../../images/parts/AE_servo_MG90S.png) |
| 1× | 2× | **Spring** - 9.5 × 19 mm | |

The MG90S has metal gears, so it copes with a heavier load than the SG90 used in the gauges.

The three screws and the single arm that come with the servo are used as well.

> **Note**
> On some servos the single arm that comes in the package is too long and does not fit into the case. In that case take the double arm, which has one side slightly shorter, and cut the other side off. You can also take the four-way arm and cut off the three sides you do not need.

> **⚠️ Fit the servo arm only after MobiFlight has set the servo**\
> Do not fit the arm when you install the servo for the first time - leave the servo without it. If you use my [MobiFlight configuration](../mobiflight.md), the servo moves to the right position once it is connected to power and to the MEGA and MobiFlight is started. Only then fit the arm, exactly as in the photo on this page.

---

## Screws

| Per switch | Total for 2 | Screw | Joins |
|---:|---:|---|---|
| 6× | 12× | Dome head M3×8 | bottom case + top case, bottom case + bottom case cover |

---

## Assembly Diagram

Screw abbreviations used in the diagram: **DH** = dome head.

Exploded view of the Engine Start Switch

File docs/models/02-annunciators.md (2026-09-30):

# 2. Annunciators

[📦 Download the printable model on MakerWorld](https://makerworld.com/en/models/3121595-boeing-737-overhead-annunciators)

[← Back to model list](README.md)

---

> **Note**
> The annunciators are shared across the whole overhead panel - they are not part of any individual panel model. A total of **121** annunciators of this standard size are needed for the complete project.
>
> The overhead also uses two large special annunciators with two LEDs each - one yellow and one white. They are not part of this model; their printable parts come with the [Engine and Oxygen Panel](30-engine-and-oxygen-panel.md) model.
>
> For the PCB, bill of materials, switch type and wiring, see [Annunciator PCB](../pcb/annunciator.md).

---

## Photos

<table>
<tbody>
<tr>
<td align="center" width="50%">Assembled annunciator with its cable<br><sub>A single assembled annunciator</sub></td>
<td align="center" width="50%">Finished annunciator fitted into a panel<br><sub>Finished annunciator fitted into a panel</sub></td>
</tr>
</tbody>
<tbody>
<tr>
<td align="center" width="50%">The six printed parts of one annunciator<br><sub>The six printed parts of one annunciator</sub></td>
<td align="center" width="50%">Exploded view of one annunciator<br><sub>One annunciator, exploded</sub></td>
</tr>
</tbody>
</table>

---

## How They Work

The annunciators have **built-in push buttons**, so they can reproduce the behaviour of the annunciators on the real aircraft. Pressing an annunciator lights it up, exactly as it does on the real overhead panel.

Each annunciator carries two tact switches and one LED on its own small PCB - see [Annunciator PCB](../pcb/annunciator.md).

---

## Annunciator Types

The project uses several types of annunciator:

| Qty | Background | LED |
|---:|---|---|
| 93× | black | yellow |
| 9× | black | green |
| 2× | black | white |
| 8× | blue | white |
| 9× | blue | white, two brightness levels (DIM/BRIGHT) |
| 2× | black | large special annunciators, one yellow and one white LED |

The last row is the two large special annunciators described in the note at the top of the page - they are not part of this model.

---

## Filament

| | Colour | Filament |
|---|---|---|
|  | Black | Bambu PLA Basic Black (10101) |
|  | White | Bambu PLA Basic Jade White (10100) |

---

## 3D Printed Parts

Six parts make up one annunciator. The quantities below are for the complete project.

| Qty | Part | Notes |
|---:|---|---|
| 121× | outer-part | print on a **Smooth** PEI plate |
| 121× | inner-part | see the printing warning below |
| 121× | table | white; print on a **Smooth** PEI plate |
| 121× | table-frame | print on a **Smooth** PEI plate |
| 121× | pcb-holder | |
| 121× | pcb-holder-cover | |

### ⚠️ Printing the inner-part

All parts of this model are printed with a **0.12 mm** layer height, except the **inner-part**, which uses **0.16 mm**.

The inner-part can be quite challenging to print. Its upper section may wobble during printing, which can cause it to detach from the build plate. If printing at 0.16 mm is unsuccessful, try **0.20 mm** instead. Calibrating the printer to reduce vibrations may also help.

---

## UV Print Files

| Qty | File |
|---:|---|
| 1× | A4 PDF - annunciator labels |

The PDF and the printing instructions are on the [UV Print Files](../uv-print.md) page.

---

## PCB

| Qty | PCB | Gerber files |
|---:|---|---|
| 121× | [Annunciator PCB](../pcb/annunciator.md) | [📥 PCB_Annunciator.zip](https://raw.githubusercontent.com/om7ea/B737/main/PCB/PCB_Annunciator.zip) |

---

## Assembly Diagram

One annunciator, exploded - from the table-frame on the left to the PCB and its cable on the right:

Exploded view of one annunciator

### 1. Table and UV foil

Attach the white **table** to the transparent self-adhesive UV-printed foil.

Table attached to the UV-printed foil

### 2. Trim the foil

Carefully trim away the excess foil using a knife.

Trimming the excess foil with a knife

### 3. Glue the table into the table-frame

Apply a small drop of super glue to the highlighted areas.

Glue points on the table-frame marked in orange

### 4. Insert the inner-part

Inner-part inserted into the table-frame

### 5. Fit the outer-part into the panel

Insert the **outer-part** into the panel and secure it with super glue or a hot glue gun. I recommend a 7 mm hot glue gun, as the assembly can then be taken apart again later if needed.

<table>
<tr>
<td align="center" width="50%">Outer-part fitted into the panel, seen from the front<br><sub>Front of the panel</sub></td>
<td align="center" width="50%">Gluing the outer-part from the back of the panel<br><sub>Glued from the back with a hot glue gun</sub></td>
</tr>
</table>

### 6. Insert the assembled PCB into the pcb-holder

Instructions for assembling the PCB are on the [Annunciator PCB](../pcb/annunciator.md) page.

Assembled PCB inserted into the pcb-holder

### 7. Glue the pcb-holder in place

Complete this step **only once you have the assembled RJ45 LED driver**, so that you can connect the annunciator PCB and test the mechanism while you work.

> **⚠️ Test before you glue**\
> Assemble the parts completely **without glue** first and test the mechanism to make sure that both buttons work correctly and move freely. Only glue once you have confirmed that everything works.
>
> In some cases the mechanism may not work correctly - only one of the two buttons responds, neither button responds, or the buttons stay permanently pressed. If this happens, disassemble the parts **immediately** and find the cause before the glue sets. Otherwise the mechanism can end up permanently glued in the wrong position, and the outer-part and pcb-holder may have to be destroyed to take it apart.
>
> A slow-setting adhesive with a working time of about 1 minute is the safer choice. I used standard super glue myself without any problems.

Once the mechanism works correctly on the test RJ45 LED driver, apply a small drop of super glue to the marked areas, insert the pcb-holder with the PCB installed, and keep testing the mechanism while the glue sets to make sure it stays fully functional.

<table>
<tr>
<td align="center" width="50%">Glue points on the outer-part marked in orange<br><sub>Glue points marked in orange</sub></td>
<td align="center" width="50%">Pcb-holder with the PCB fitted into the outer-part<br><sub>Pcb-holder with the PCB in place</sub></td>
</tr>
</table>

### 8. Fit the pcb-holder cover

Apply a small amount of hot glue between the wires and attach the **pcb-holder-cover**. The hot glue also provides mechanical protection against the wires being pulled out.

<table>
<tr>
<td align="center" width="50%">Hot glue applied between the wires before fitting the cover<br><sub>Hot glue applied between the wires</sub></td>
<td align="center" width="50%">The finished annunciator<br><sub>The finished annunciator</sub></td>
</tr>
</table>

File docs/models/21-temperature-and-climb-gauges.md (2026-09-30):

# 21. Temperature and Climb Gauges

[📦 Download the printable model on MakerWorld](https://makerworld.com/en/models/3251829-boeing-737-overhead-temperature-and-climb-gauges)

[← Back to model list](README.md)

---

> **Note**
> These gauges are shared across the overhead panel - they are not part of any individual panel model. **4** of them are needed for the complete project, one on each of these panels: **Fuel Control Panel**, **Generator Bus Panel**, **Air Conditioning Control Panel** and **Cabin Altitude Panel**.
>
> All four are built from the same parts. What makes each one a different instrument is the UV-printed scale stuck to its face and the shape of its needle.

---

## Photos

<table>
<tbody>
<tr>
<td align="center" width="50%">Finished gauge, front<br><sub>A finished gauge - this one carries the FUEL TEMP scale</sub></td>
<td align="center" width="50%">The gauge from the side, showing the two backlight LED strips<br><sub>From the side - the two LED strips on the backlight part</sub></td>
</tr>
</tbody>
</table>

---

## How It Works

The needle is driven by an **SG90 servo** through a pair of printed gears. The **14-tooth** gear sits on the servo, the **7-tooth** gear on the needle shaft, so the needle turns **twice as far as the servo** - the 180° of an SG90 become a full turn of the dial.

The needle shaft itself is a **2 mm acrylic rod** running in two **MR52ZZ** ball bearings, one in the top plate and one in the backlight plate. The rod is not only a shaft: a white LED underneath shines up through it, so the rod also carries light into the needle. The 7-tooth gear sits in that light path, which is why it is printed in **transparent** PLA.

The dial itself is lit separately, by two LED strips on the backlight part - see [Backlight](#backlight).

---

## Filament

| | Colour | Filament |
|---|---|---|
|  | Black | Bambu PLA Basic Black (10101) |
|  | White | Bambu PLA Basic Jade White (10100) |
|  | Transparent | Filament PM PLA Transparent |

---

## 3D Printed Parts

The finished gauge is a 52 × 52 mm box, about 32 mm deep without the servo.

| Per gauge | Total for 4 | Part | Colour | Notes |
|---:|---:|---|---|---|
| 1× | 4× | top | White | the front plate - the UV-printed scale goes on it and it diffuses the backlight |
| 1× | 4× | backlight | Black | print with **supports** |
| 1× | 4× | cover | Black | the servo bracket; print with **supports** |
| 1× | 4× | gear 14t | Black | on the servo |
| 1× | 4× | gear 7t | Transparent | on the needle shaft, in the light path of the needle LED |

### Needles

Each needle is two parts: a white blade and a black centre cap that covers its hub. The four designs differ slightly from one another, and each one is named in the project file after the instrument it belongs to.

| Qty | Part | Colour | Used on |
|---:|---|---|---|
| 1× | hand-fuel_white + hand-fuel_black | White + Black | Fuel Control Panel |
| 1× | hand-egt-white + hand-egt-black | White + Black | Generator Bus Panel |
| 1× | hand-temp_white + hand-temp_black | White + Black | Air Conditioning Control Panel |
| 1× | hand-climb-white + hand-climb-black | White + Black | Cabin Altitude Panel |

Mixing the needles up does no harm - they all fit and they all work.

---

## Electronic and Mechanical Components

| Per gauge | Total for 4 | Part | Reference |
|---:|---:|---|---|
| 1× | 4× | **Servo SG90** - 180°, plastic gears | [Product I used](../../images/parts/AE_servo_SG90.png) |
| 2× | 8× | **Ball bearing MR52ZZ** - 2 × 5 × 2.5 mm | [Product I used](../../images/parts/AE_bearing_MR52ZZ.png) |
| 1× | 4× | **Acrylic rod** - 2 mm, transparent; the needle shaft is cut from it | [Product I used](../../images/parts/AE_acrylic_rod.png) |
| 1× | 4× | **White 5 mm flat top LED** - the same one the annunciators use | [Product I used](../../images/parts/AE_led_white.png) |
| 1× | 4× | **150 Ω resistor** - in series with the white LED | |
| 2× | 8× | **LED strip** - the scale backlight | [Product I used](../../images/parts/AE_led_strip.png) |
| 1× | 4× | **820 Ω resistor** - in series with the two LED strips | |
| 2× | 8× | **Splice connector** - lever type, for the 12 V of the scale backlight | |

The three self-tapping screws that come with the servo are used as well: two hold the servo to the cover, the third fastens the 14-tooth gear to the servo shaft.

---

## Screws

| Per gauge | Total for 4 | Screw | Joins |
|---:|---:|---|---|
| 4× | 16× | Dome head M3×8 | backlight plate + top plate |
| 2× | 8× | Dome head M3×5 | cover + backlight plate |

---

## UV Print Files

| Qty | File |
|---:|---|
| 1× | A4 PDF - gauge scales |

One sheet carries the scales for all the gauges of the overhead. The PDF and the printing instructions are on the [UV Print Files](../uv-print.md) page.

---

## Backlight

### Scale

The scale is lit by two LED strips on the backlight part, one on each side, shining through the white top plate from behind. They run on **12 V** taken from the backlighting of the panel the gauge is fitted in, so the gauge dims together with that panel - see [Power supply](../system-overview.md#power-supply).

The two strips are not wired straight across that 12 V: an **820 Ω resistor** goes in series with the pair. The white top plate passes far more light than the printed face of a panel does, so on the bare supply the scale burns out much brighter than the lettering around it. The resistor holds it back to the brightness of the rest of the overhead.

The two strips sit in parallel and the resistor goes in the lead feeding them, close to the strips.

The two LED strips in parallel with the series resistor in the supply lead

### Needle

The needle has a light of its own: a white 5 mm LED under the needle shaft, shining up through the transparent 7-tooth gear and the acrylic rod into the needle. It runs on **5 V** with a **150 Ω** resistor in series.

The needle LED and its series resistor behind the servo

The photo shows more than one resistor because I had no 150 Ω to hand and made the value up from three in parallel. One resistor of the right value does the same job.

> **Note**
> The needle lighting works, but the effect is weak. White PLA does not carry light well over the length of a needle, so the needle glows rather than lights up. It is worth building - but do not expect the needle to stand out the way the scale does.

---

## Wiring

A gauge has three connections. Which PCB and which socket they land on depends on the panel the gauge is fitted in, and is on that panel's own page.

| Connection | Supply | Comes from |
|---|---|---|
| Servo | 5 V | +5 V, the control signal and GND, all three from an [RJ45 Direct](../pcb/rj45-direct.md) PCB |
| Needle LED | 5 V | +5 V and GND from two pins of a double-ended pin header on an [RJ45 Direct](../pcb/rj45-direct.md) PCB |
| Scale backlight | 12 V | the backlighting of the panel the gauge is fitted in, through an **820 Ω** resistor - see [Backlight](#backlight) |

> **⚠️ The servo plug has to be rewired**\
> The SG90 does not leave the factory in the order the RJ45 Direct PCB expects, so the servo will **not** work if you plug it in as it comes. **Swap the red and the yellow wire:**
>
> | | Wire order in the plug |
> |---|---|
> | As delivered | brown - red - yellow |
> | **Needed** | **brown - yellow - red** |
>
> Lift the small tabs on the plastic housing, pull those two crimped contacts out and swap them over. Brown stays where it is. (On some SG90s the yellow wire is orange instead - it is the signal wire either way.)

The 12 V for the scale backlight is brought over from the panel's own backlighting with two **lever-type splice connectors**, one for +12 V and one for GND. Where they sit is up to you - both on the gauge works fine, and so does one on the gauge and one on the panel. On my own build it varies from panel to panel: the leads coming out of some backlight panels were short, so one connector had to stay on the panel and only the other went on the gauge. There is nothing to screw them to, so **glue them down with super glue.**

---

## Assembly

Screw abbreviations used below: **DH** = dome head.

Exploded view of one gauge

<table>
<tbody>
<tr>
<td width="55%"><b>1.</b> Screw the <b>servo</b> to the <b>cover</b> with two of the screws that come in the servo bag.</td>
<td align="center">The servo screwed to the cover</td>
</tr>
</tbody>
<tbody>
<tr>
<td width="55%"><b>2.</b> Fasten the <b>14-tooth gear</b> to the servo shaft, again with a screw from the servo bag.</td>
<td align="center">The 14-tooth gear fastened to the servo shaft</td>
</tr>
</tbody>
<tbody>
<tr>
<td width="55%"><b>3.</b> Stick the printed foil onto the <b>top</b> part.</td>
<td align="center">The printed foil stuck onto the top part</td>
</tr>
</tbody>
<tbody>
<tr>
<td width="55%"><b>4.</b> Press an <b>MR52ZZ</b> bearing into the top part.</td>
<td align="center">The first MR52ZZ bearing pressed into the top part</td>
</tr>
</tbody>
<tbody>
<tr>
<td width="55%"><b>5.</b> Fit the two <b>LED strips</b> onto the <b>backlight</b> part and bring their leads out. The two are wired in parallel and the <b>820 Ω resistor</b> goes in the lead feeding them - see <a href="#backlight">Backlight</a>. They have to go on before the part is screwed on in the next step.</td>
<td align="center">The two LED strips on the backlight part, in parallel, with the series resistor in the supply lead</td>
</tr>
</tbody>
<tbody>
<tr>
<td width="55%"><b>6.</b> Screw the <b>backlight</b> part on with 4× DH M3×8.</td>
<td align="center">The backlight part screwed on with four M3x8 screws</td>
</tr>
</tbody>
<tbody>
<tr>
<td width="55%"><b>7.</b> Press the second <b>MR52ZZ</b> bearing into the backlight part.</td>
<td align="center">The second MR52ZZ bearing pressed into the backlight part</td>
</tr>
</tbody>
<tbody>
<tr>
<td width="55%"><b>8.</b> Push the <b>acrylic rod</b> through both bearings. I used a 26 mm length.</td>
<td align="center">The acrylic rod pushed through both bearings</td>
</tr>
</tbody>
<tbody>
<tr>
<td width="55%"><b>9.</b> From the front, glue the white <b>needle</b> onto the rod with super glue.</td>
<td align="center">The white needle glued onto the acrylic rod from the front</td>
</tr>
</tbody>
<tbody>
<tr>
<td width="55%"><b>10.</b> Glue the black <b>centre cap</b> onto the needle.</td>
<td align="center">The black centre cap glued onto the hub of the needle</td>
</tr>
</tbody>
<tbody>
<tr>
<td width="55%"><b>11.</b> From the back, glue the <b>7-tooth gear</b> onto the acrylic rod.</td>
<td align="center">The 7-tooth gear glued onto the acrylic rod from the back</td>
</tr>
</tbody>
<tbody>
<tr>
<td width="55%"><b>12.</b> Put the <b>cover</b> with its servo in place, so that the two gears mesh, and screw it down with 2× DH M3×5.</td>
<td align="center">The cover with the servo fitted onto the backlight part</td>
</tr>
</tbody>
<tbody>
<tr>
<td width="55%"><b>13.</b> Push the white <b>LED</b> - the one with the 150 Ω resistor - into the hole in the cover, beside the servo.</td>
<td align="center">The white LED pushed into the hole beside the servo</td>
</tr>
</tbody>
</table>

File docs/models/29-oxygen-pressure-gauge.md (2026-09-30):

# 29. Oxygen Pressure Gauge

[📦 Download the printable model on MakerWorld](https://makerworld.com/en/models/3309881-boeing-737-overhead-oxygen-pressure-gauge)

[← Back to model list](README.md)

---

> **Note**
> This gauge is a model of its own - it is not part of any panel model. **One** is needed for the complete project, on the **[Engine and Oxygen Panel](30-engine-and-oxygen-panel.md)**.
>
> It is built the same way as the [Temperature and Climb Gauges](21-temperature-and-climb-gauges.md). What makes it a different instrument is the UV-printed scale stuck to its face - OXY PRESS, PSI × 100 - the shape of its needle, and the size of the body itself: this one is a **49 × 49 mm** box, not 52 × 52 mm.

---

## Photos

<table>
<tbody>
<tr>
<td align="center" width="50%">Finished Oxygen Pressure Gauge, front<br><sub>The finished gauge</sub></td>
<td align="center" width="50%">The gauge from the side, showing the LED strips, the servo and the splice connectors<br><sub>From the side - the two backlight LED strips inside the housing, the servo and the two splice connectors</sub></td>
</tr>
</tbody>
</table>

---

## How It Works

The needle is driven by an **SG90 servo** through a pair of printed gears. The **14-tooth** gear sits on the servo, the **7-tooth** gear on the needle shaft, so the needle turns **twice as far as the servo** - the 180° of an SG90 become a full turn of the needle.

The needle shaft itself is a **2 mm acrylic rod** running in two **MR52ZZ** ball bearings, one in the top plate and one in the backlight plate. The rod is not only a shaft: a white LED underneath shines up through it, so the rod also carries light into the needle. The 7-tooth gear sits in that light path, which is why it is printed in **transparent** PLA.

The dial itself is lit separately, by two LED strips inside the housing - see [Backlight](#backlight).

---

## Filament

| | Colour | Filament |
|---|---|---|
|  | Black | Bambu PLA Basic Black (10101) |
|  | White | Bambu PLA Basic Jade White (10100) |
|  | Transparent | Filament PM PLA Transparent |

---

## 3D Printed Parts

| Qty | Part | Colour | Notes |
|---:|---|---|---|
| 1× | top | White | the front plate - the UV-printed scale goes on it and it diffuses the backlight |
| 1× | backlight | Black | print with **supports** |
| 1× | cover | Black | the servo bracket; print with **supports** |
| 1× | gear 14t | Black | on the servo |
| 1× | gear 7t | Transparent | on the needle shaft, in the light path of the needle LED |
| 1× | needle - blade | White | |
| 1× | needle - centre cap | Black | covers the hub of the blade |

---

## Electronic and Mechanical Components

| Qty | Part | Reference |
|---:|---|---|
| 1× | **Servo SG90** - 180°, plastic gears | [Product I used](../../images/parts/AE_servo_SG90.png) |
| 2× | **Ball bearing MR52ZZ** - 2 × 5 × 2.5 mm | [Product I used](../../images/parts/AE_bearing_MR52ZZ.png) |
| 1× | **Acrylic rod** - 2 mm, transparent; the needle shaft is cut from it | [Product I used](../../images/parts/AE_acrylic_rod.png) |
| 1× | **White 5 mm flat top LED** - the same one the annunciators use | [Product I used](../../images/parts/AE_led_white.png) |
| 1× | **150 Ω resistor** - in series with the white LED | |
| 2× | **LED strip** - the scale backlight | [Product I used](../../images/parts/AE_led_strip.png) |
| 1× | **820 Ω resistor** - in series with the two LED strips | |
| 2× | **Splice connector** - lever type, for the 12 V of the scale backlight | |

The three self-tapping screws that come with the servo are used as well: two hold the servo to the cover, the third fastens the 14-tooth gear to the servo shaft.

---

## Screws

| Qty | Screw | Joins |
|---:|---|---|
| 4× | Dome head M3×8 | backlight plate + top plate |
| 2× | Dome head M3×5 | cover + backlight plate |

---

## UV Print Files

| Qty | File |
|---:|---|
| 1× | A4 PDF - gauge scales |

One sheet carries the scales for all the gauges of the overhead. The PDF and the printing instructions are on the [UV Print Files](../uv-print.md) page.

---

## Backlight

### Scale

The scale is lit by two LED strips inside the housing, one on each side, shining through the white top plate from behind. They run on **12 V** taken from the backlighting of the Engine and Oxygen Panel, so the gauge dims together with that panel - see [Power supply](../system-overview.md#power-supply).

The two strips are not wired straight across that 12 V: an **820 Ω resistor** goes in series with the pair. The white top plate passes far more light than the printed face of a panel does, so on the bare supply the scale burns out much brighter than the lettering around it. The resistor holds it back to the brightness of the rest of the overhead.

The two strips sit in parallel and the resistor goes in the lead feeding them, close to the strips.

The two LED strips in parallel with the series resistor in the supply lead

### Needle

The needle has a light of its own: a white 5 mm LED under the needle shaft, shining up through the transparent 7-tooth gear and the acrylic rod into the needle. It runs on **5 V** with a **150 Ω** resistor in series.

In the side photo there are two resistors on the servo, not one - I had no 150 Ω to hand and made the value up from two. One resistor of the right value does the same job.

> **Note**
> The needle lighting works, but the effect is weak. White PLA does not carry light well over the length of a needle, so the needle glows rather than lights up. It is worth building - but do not expect the needle to stand out the way the scale does.

---

## Wiring

The gauge has three connections.

| Connection | Supply | Comes from |
|---|---|---|
| Servo | 5 V | the control signal, **+5 V** and **GND**, all three from the pin headers at **pin 8** of the RJ45 Direct PCB on the [Interphone and Dome Panel](27-interphone-and-dome-panel.md#wiring) |
| Needle LED | 5 V | **+5 V** and **GND** from the **-** and **+** pins at position **7** of the same board |
| Scale backlight | 12 V | the backlighting of the Engine and Oxygen Panel, through an **820 Ω** resistor - see [Backlight](#backlight) |

> **⚠️ The servo plug has to be rewired**\
> The SG90 does not leave the factory in the order the RJ45 Direct PCB expects, so the servo will **not** work if you plug it in as it comes. **Swap the red and the yellow wire:**
>
> | | Wire order in the plug |
> |---|---|
> | As delivered | brown - red - yellow |
> | **Needed** | **brown - yellow - red** |
>
> Lift the small tabs on the plastic housing, pull those two crimped contacts out and swap them over. Brown stays where it is. (On some SG90s the yellow wire is orange instead - it is the signal wire either way.)

The 12 V for the scale backlight is brought over from the panel's own backlighting with two **lever-type splice connectors**, one for +12 V and one for GND. Where they sit is up to you - both on the gauge works fine, and so does one on the gauge and one on the panel. There is nothing to screw them to, so **glue them down with super glue.**

---

## Assembly Diagram

Screw abbreviations used in the diagram: **DH** = dome head.

Exploded view of the gauge

> **Note**
> Three of the joints may need a drop of super glue, depending on how tight they come out of your printer: the **7-tooth gear** on the acrylic rod, the **white needle** on the acrylic rod, and the **black centre cap** on the white needle.

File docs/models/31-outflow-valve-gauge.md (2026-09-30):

# 31. Outflow Valve Gauge

[📦 Download the printable model on MakerWorld](https://makerworld.com/en/models/3323749-boeing-737-overhead-outflow-valve-gauge)

[← Back to model list](README.md)

---

> **Note**
> This gauge is a model of its own - it is not part of any panel model. **One** is needed for the complete project, on the **[Cabin Pressure Control Panel](32-cabin-pressure-control-panel.md)**.
>
> It is built like the other gauges of the overhead, with two differences. Only the scale is lit - the needle carries no light of its own. And the acrylic window is screwed straight onto the gauge instead of being glued behind the bezel of a panel.

---

## Photos

<table>
<tbody>
<tr>
<td align="center" width="50%">Finished Outflow Valve Gauge, front<br><sub>The finished gauge</sub></td>
<td align="center" width="50%">The gauge from above, showing the LED strip, the servo and the resistor<br><sub>From above - the LED strip bent around the housing, the servo and the series resistor</sub></td>
</tr>
</tbody>
</table>

---

## How It Works

The needle is driven by an **SG90 servo** through a pair of printed gears, the servo gear on the servo shaft and the rod gear on the needle shaft. The needle shaft itself is a **2 mm acrylic rod** running in two **MR52ZZ** ball bearings, one in the top panel and one in the backlight part.

---
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

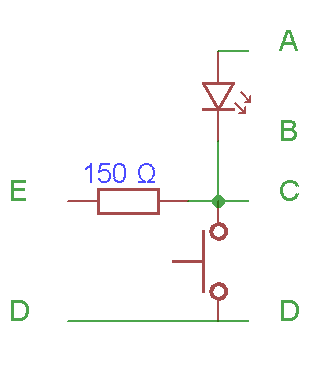
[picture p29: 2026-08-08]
images/pcb/PCB_Annunciator_schematic_C.png

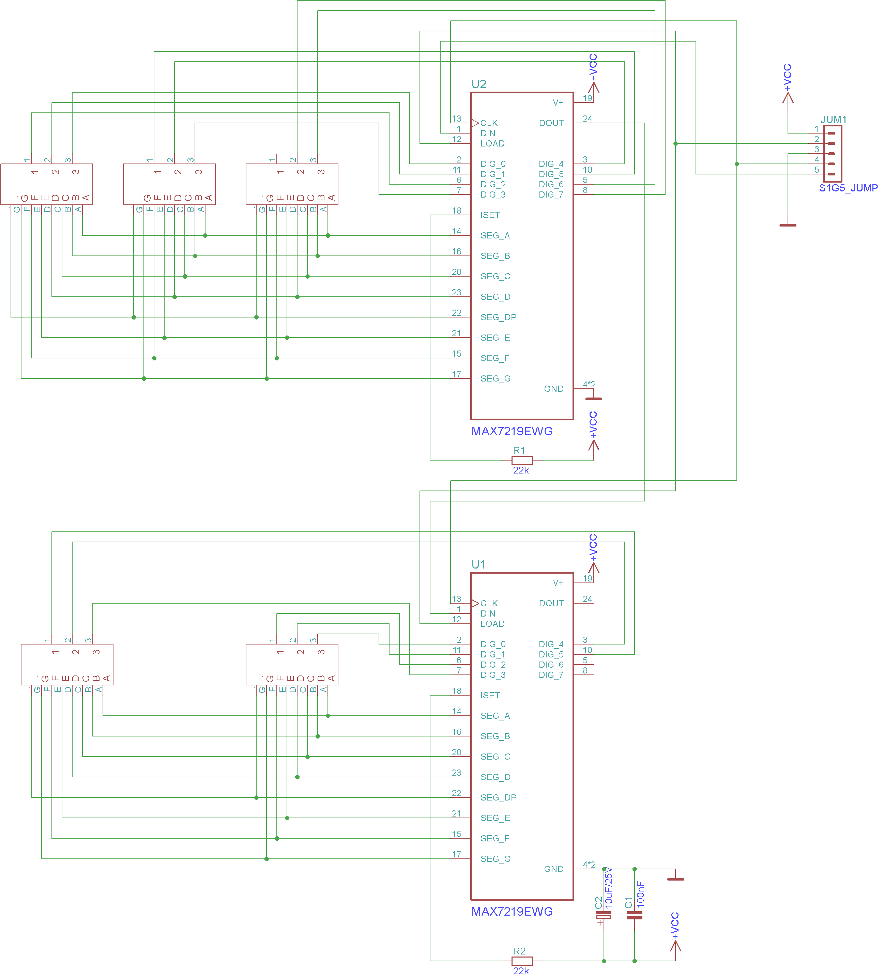
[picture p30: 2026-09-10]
images/pcb/PCB_AC_DC_Meter_schematic.png

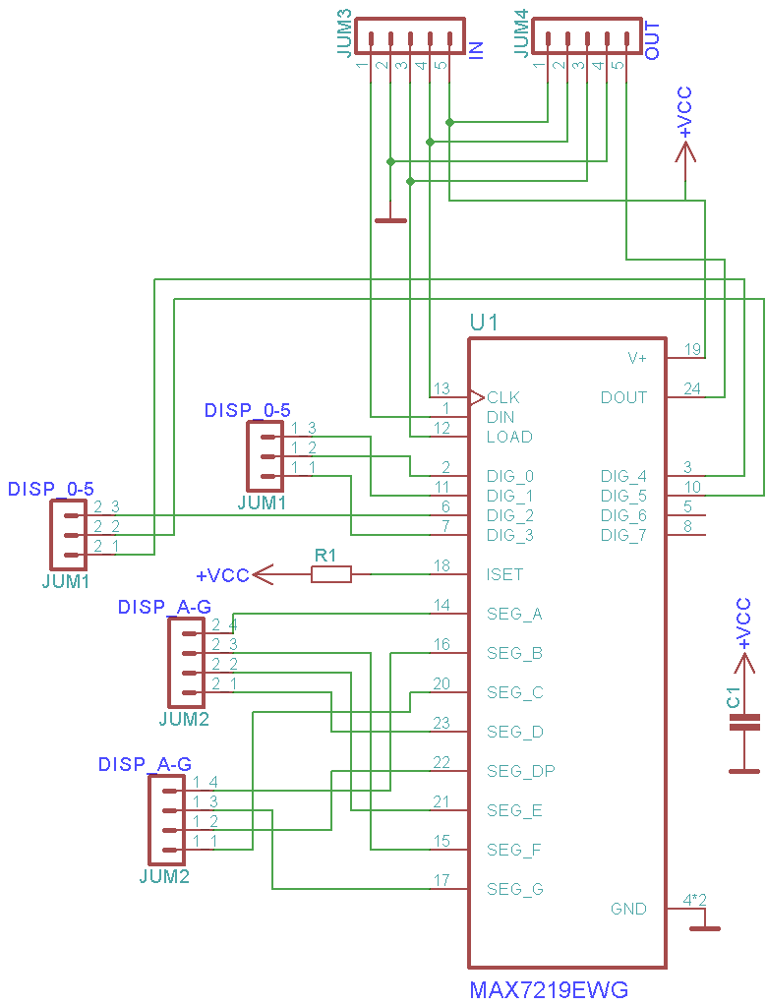
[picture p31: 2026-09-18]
images/pcb/PCB_Cabin_Pressure_Display_MAX_schematic.png

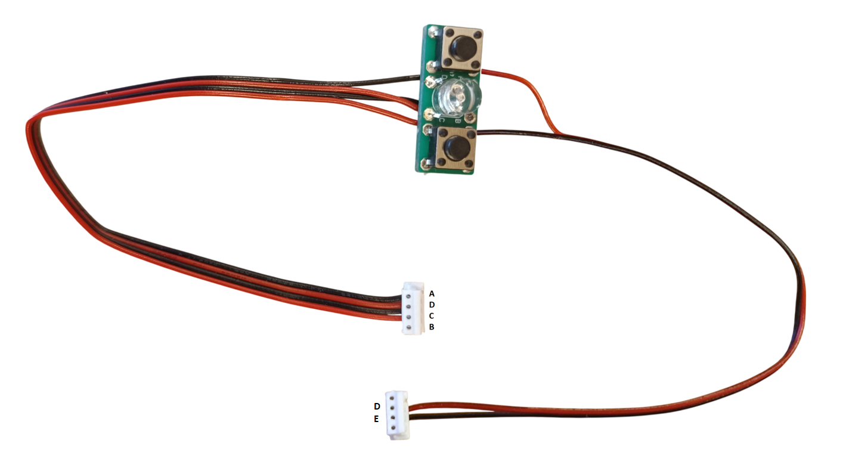
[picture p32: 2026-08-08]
images/pcb/PCB_Annunciator_schematic_C1.png

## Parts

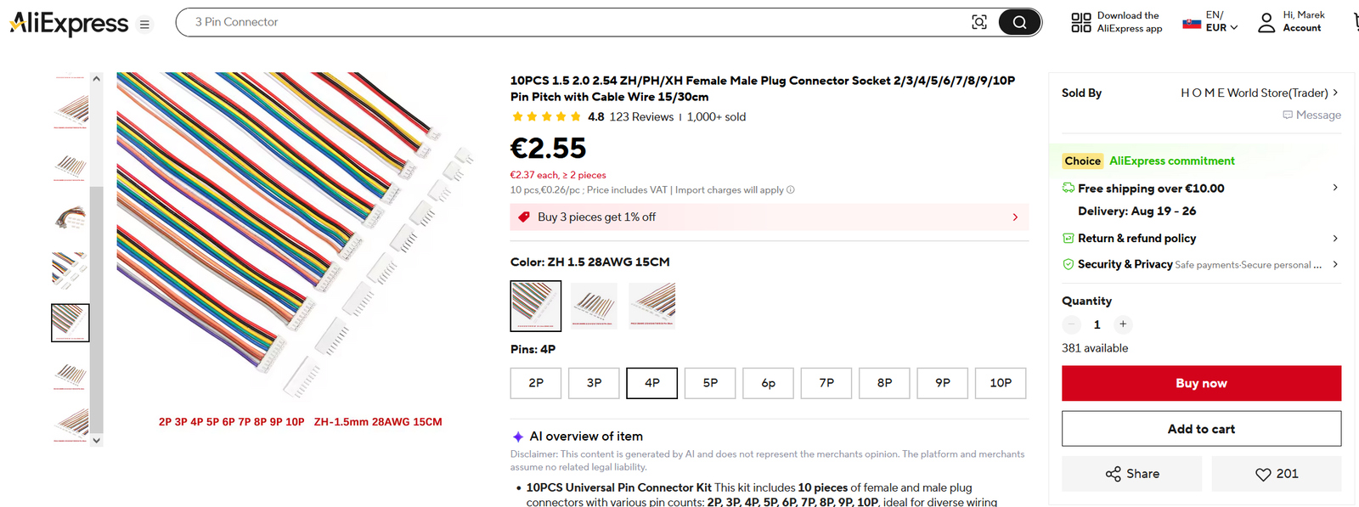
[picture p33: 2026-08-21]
images/parts/AE_ZH.png

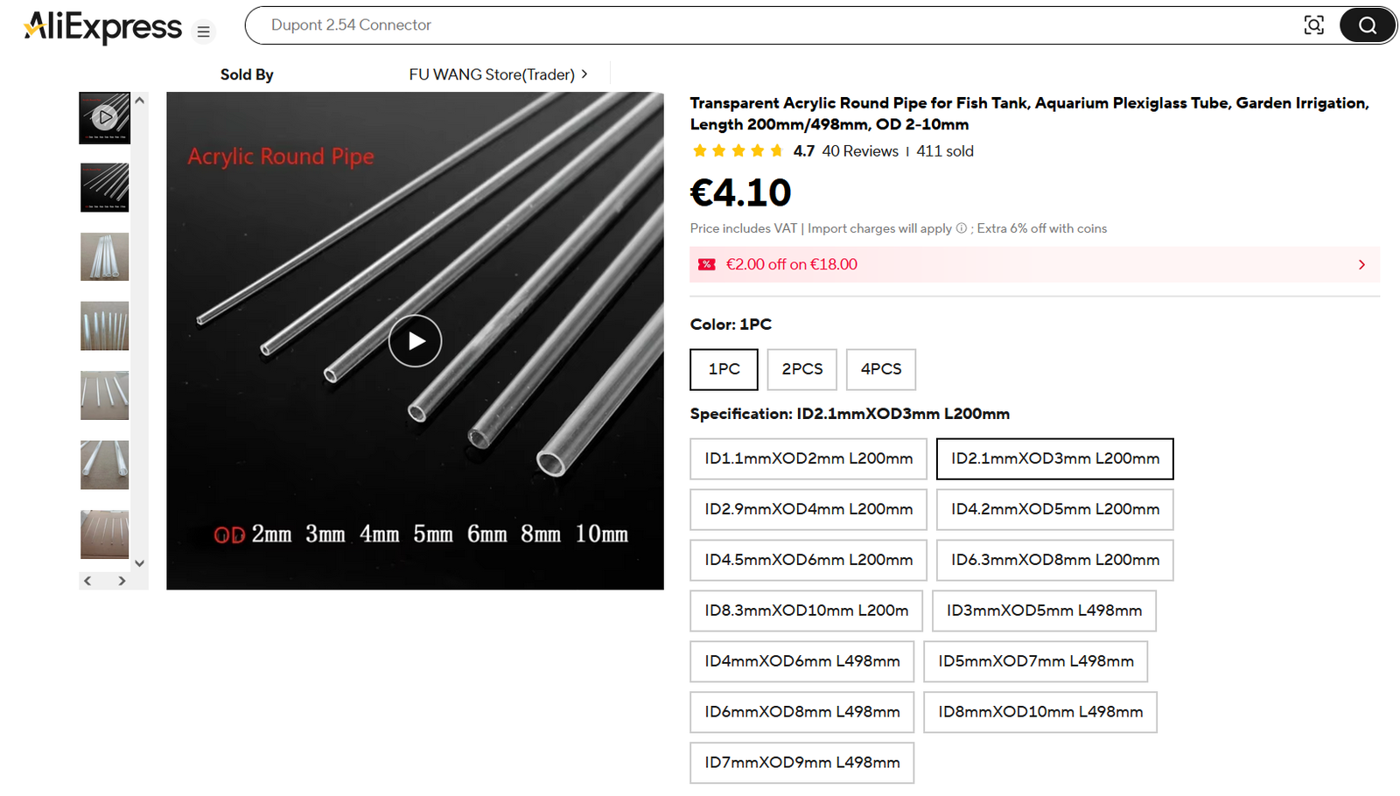
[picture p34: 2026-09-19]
images/parts/AE_acrylic_pipe.png

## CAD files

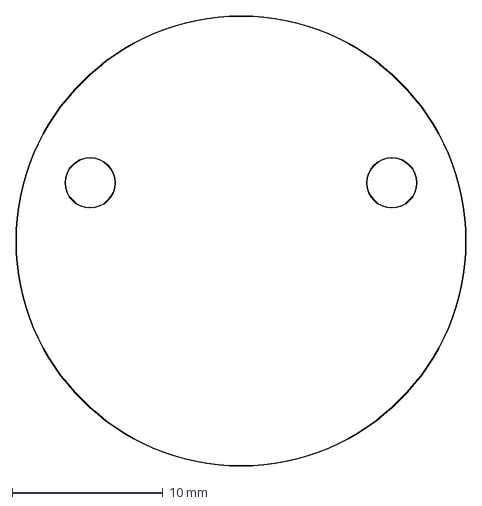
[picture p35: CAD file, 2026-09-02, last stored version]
docs/cnc_cut/cnc_gauge_29-8.dxf
29.8 x 29.8 mm

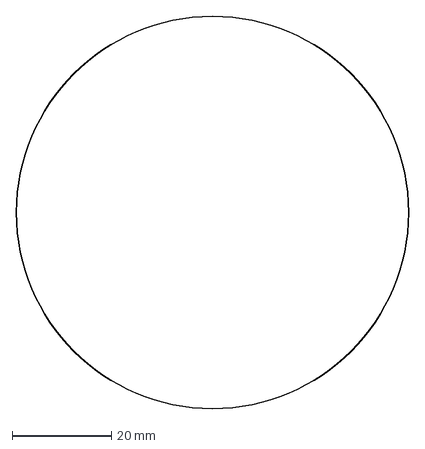
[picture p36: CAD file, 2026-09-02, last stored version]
docs/cnc_cut/cnc_gauge_78-9.dxf
78.9 x 78.9 mm

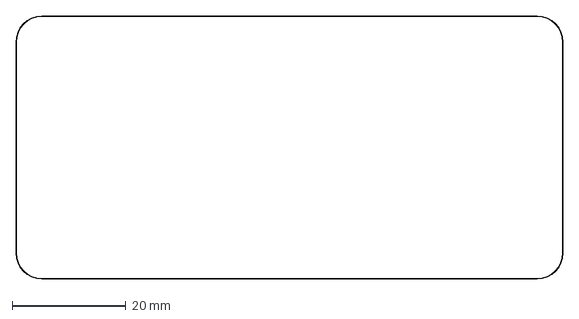
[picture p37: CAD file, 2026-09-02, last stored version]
docs/cnc_cut/cnc_meter_window.dxf
96.0 x 46.0 mm

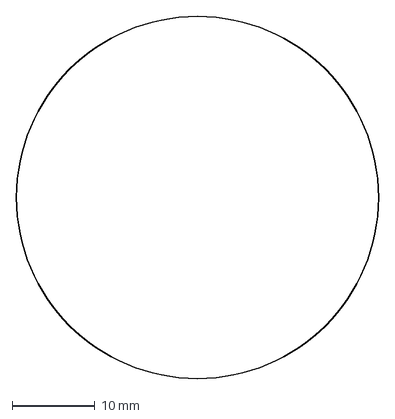
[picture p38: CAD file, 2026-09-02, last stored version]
docs/cnc_cut/cnc_gauge_43-8.dxf
43.8 x 43.8 mm

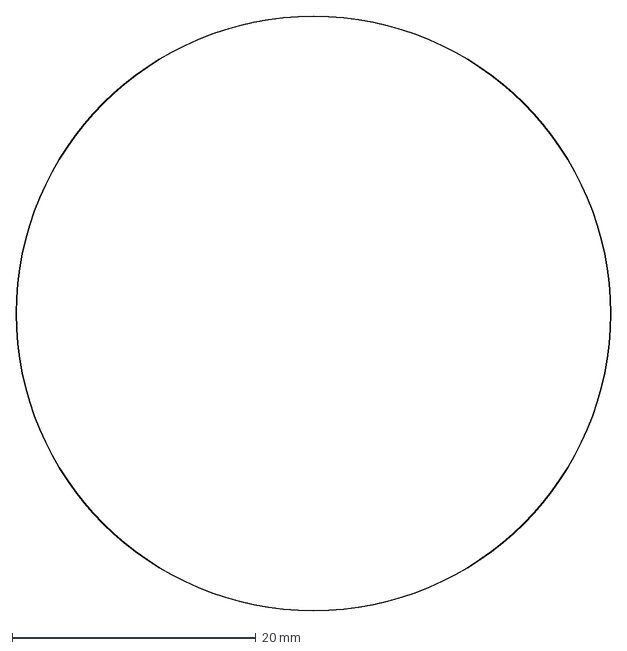
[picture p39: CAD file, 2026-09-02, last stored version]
docs/cnc_cut/cnc_gauge_48-8.dxf
48.8 x 48.8 mm

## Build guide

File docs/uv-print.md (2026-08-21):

# UV Print Files

Printed graphics for the panel faces and annunciators.

[← Back to main page](../README.md)

---

## Downloads

<table>
<tr>
<td align="center">
<a href="https://raw.githubusercontent.com/om7ea/B737/main/docs/uv_print/uv_annunciators.pdf">
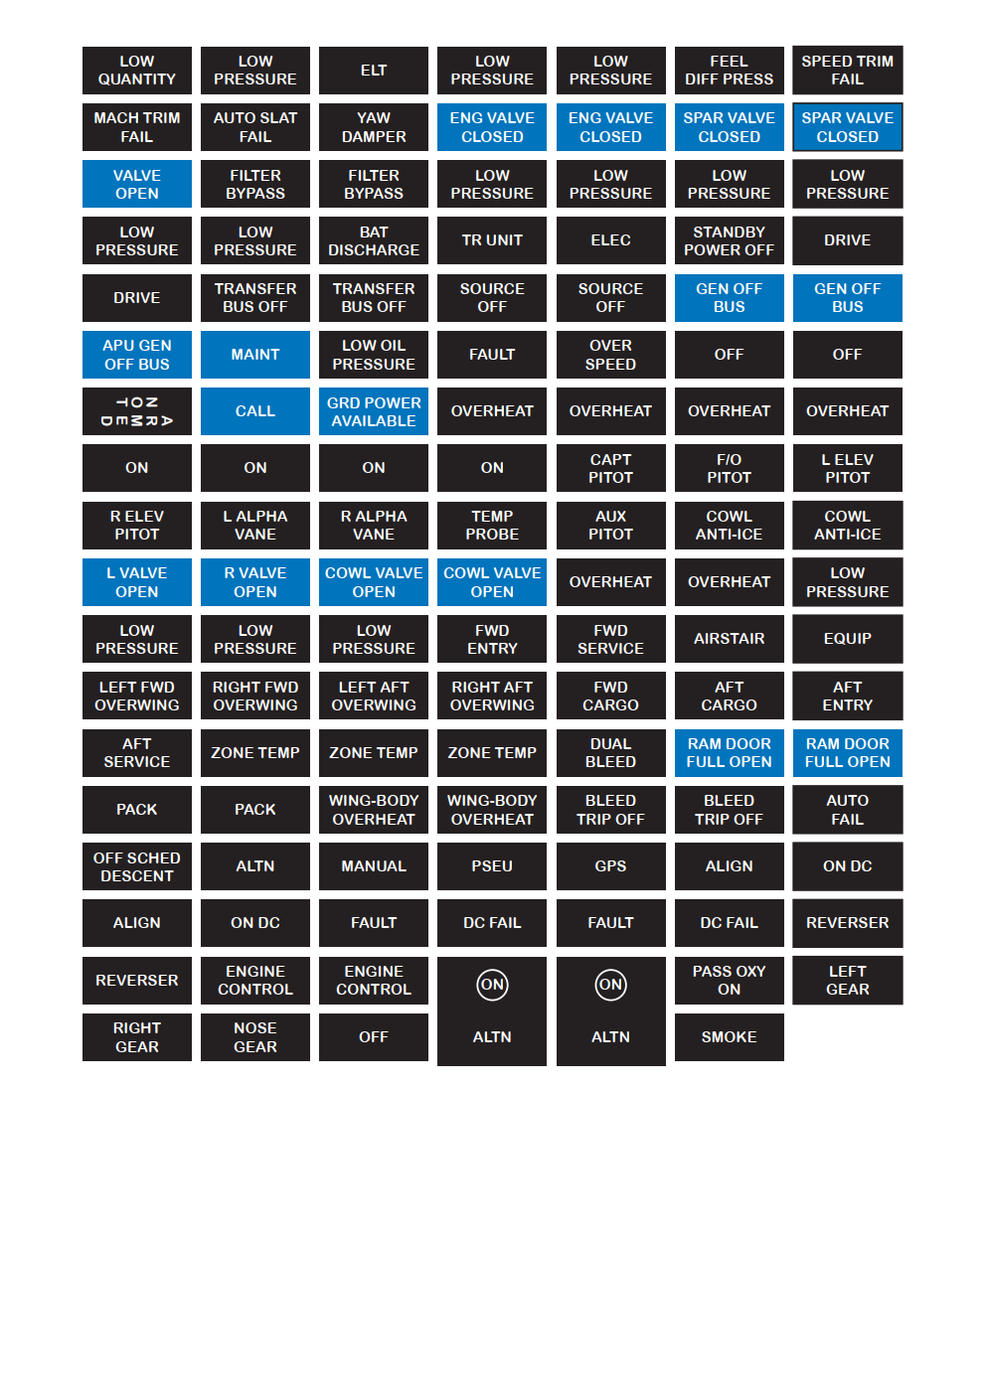
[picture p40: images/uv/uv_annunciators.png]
<br>
<b>Annunciators</b>
</a>
</td>
<td align="center">
<a href="https://raw.githubusercontent.com/om7ea/B737/main/docs/uv_print/uv_gauges.pdf">
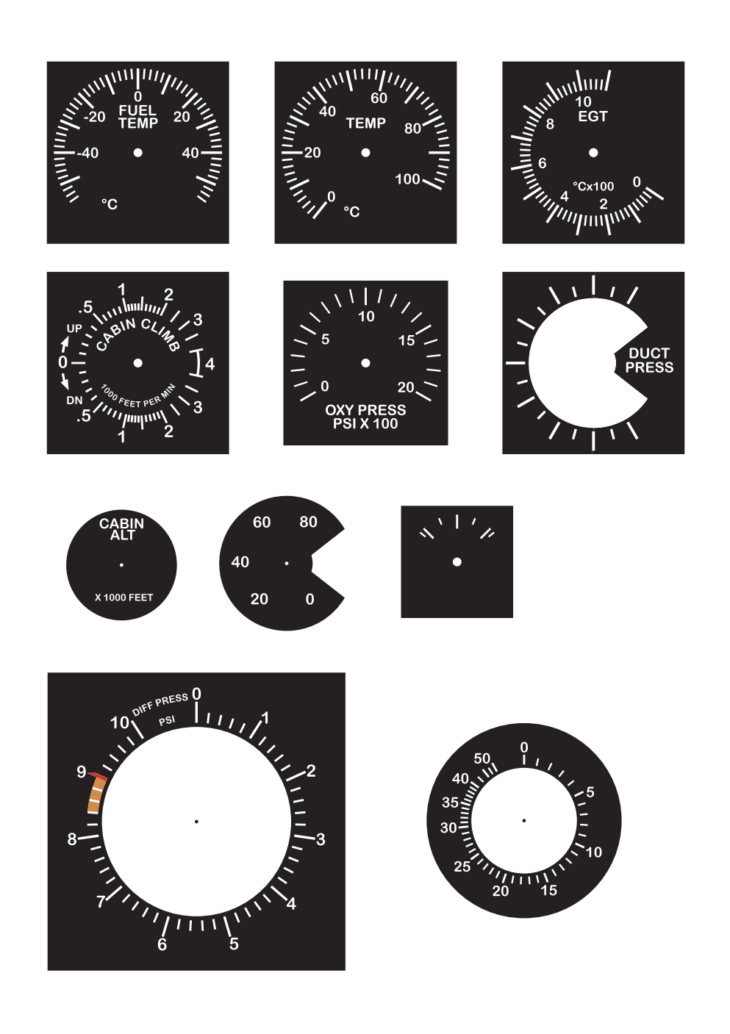
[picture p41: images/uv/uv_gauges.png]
<br>
<b>Gauges</b>
</a>
</td>
</tr>
</table>

---

## Printing Instructions

The PDF files should be printed using **double-pass UV printing on A4 transparent self-adhesive foil**. This method provides excellent opacity and completely eliminates light bleed through the black areas when the panel is backlit. Printing both sheets cost approximately **€15**.

> **Tip**
> Order at least **two copies** of each PDF file. During multiple prints, it is possible that one area of a sheet will be perfectly sharp while another area may appear slightly blurred. Having a second copy allows you to choose the best sections from each print if necessary.

---

## Why UV Printing

Finding a suitable printing method took a considerable amount of trial and error. I initially tried standard laser printing, but the black areas were not opaque enough. When backlit, light leaked through the black print, resulting in poor contrast and an unrealistic appearance.

A local professional print shop suggested using UV printing instead. They also recommended printing the graphics twice on top of each other to achieve a much denser black. This solution produced excellent results and completely solved the backlight bleed issue.

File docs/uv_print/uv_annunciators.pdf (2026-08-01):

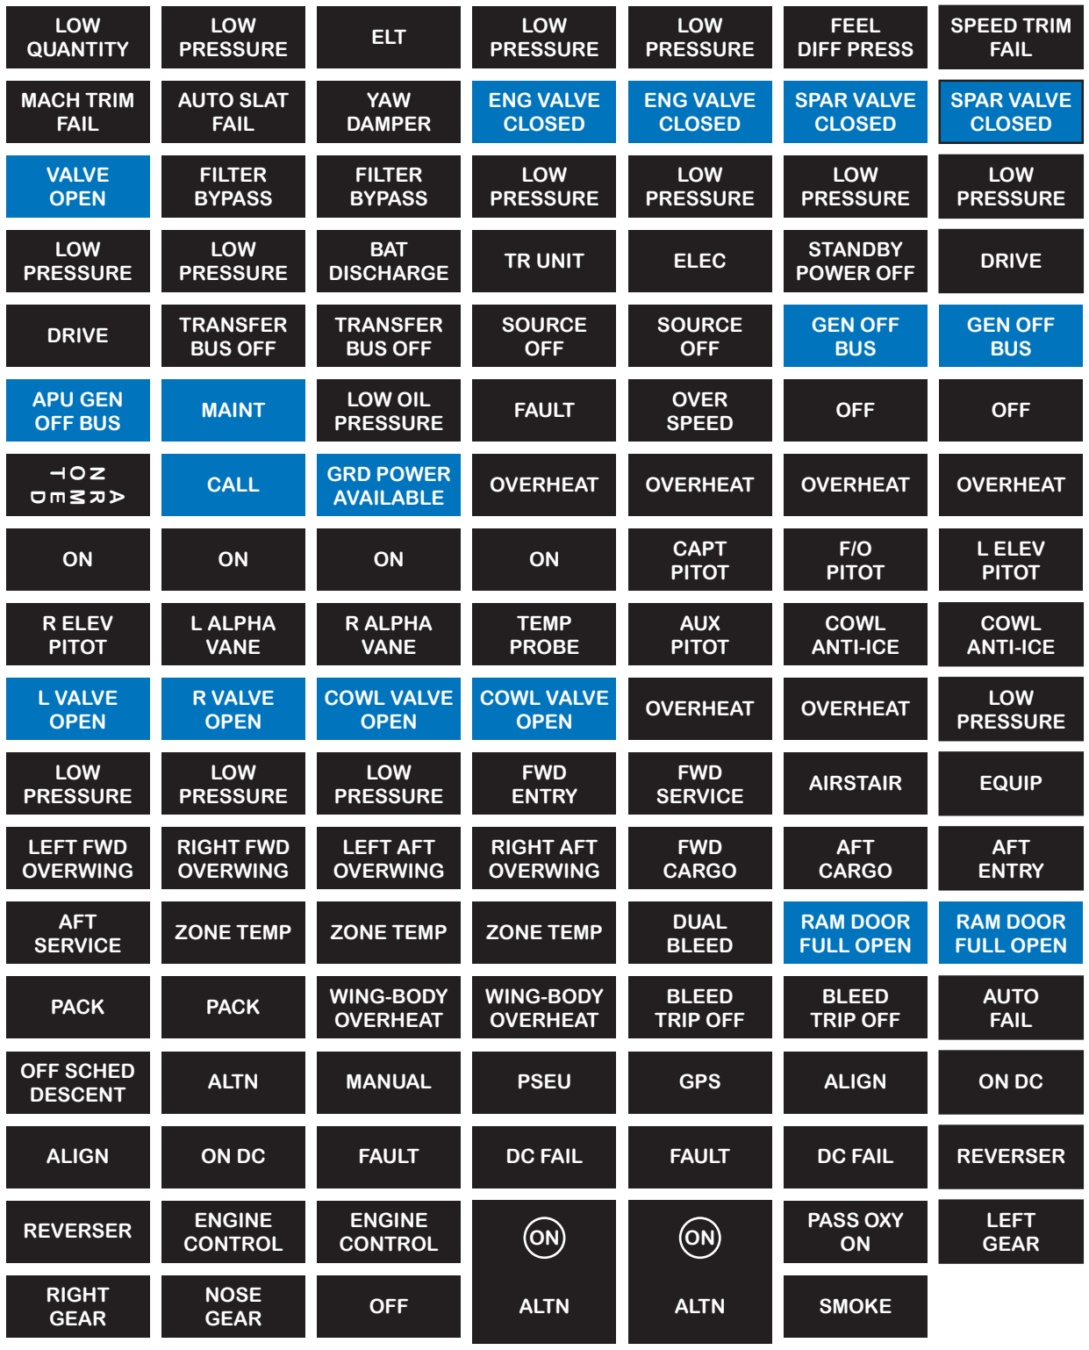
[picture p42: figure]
LOW QUANTITY; LOW PRESSURE; FEEL DIFF PRESS; SPEED TRIM FAIL; MACH TRIM FAIL; AUTO SLAT FAIL; YAW DAMPER; ENG VALVE CLOSED; SPAR VALVE CLOSED; VALVE OPEN; FILTER BYPASS; BAT; DISCHARGE; TR UNIT; ELEC; STANDBY; POWER OFF; DRIVE; TRANSFER; BUS OFF; TRANSFER BUS OFF; SOURCE OFF; GEN OFF BUS; APU GEN; OFF BUS; MAINT; LOW OIL; PRESSURE; FAULT; OVER; SPEED; OFF; ARMED; NOT; CALL; GRD POWER; AVAILABLE; OVERHEAT; CAPT; PITOT; F/O PITOT; L ELEV PITOT; R ELEV PITOT; L ALPHA VANE; R ALPHA VANE; TEMP PROBE; AUX PITOT; COWL ANTI-ICE; L VALVE OPEN; R VALVE OPEN; COWL VALVE OPEN; COWL VALVE; OPEN; LOW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

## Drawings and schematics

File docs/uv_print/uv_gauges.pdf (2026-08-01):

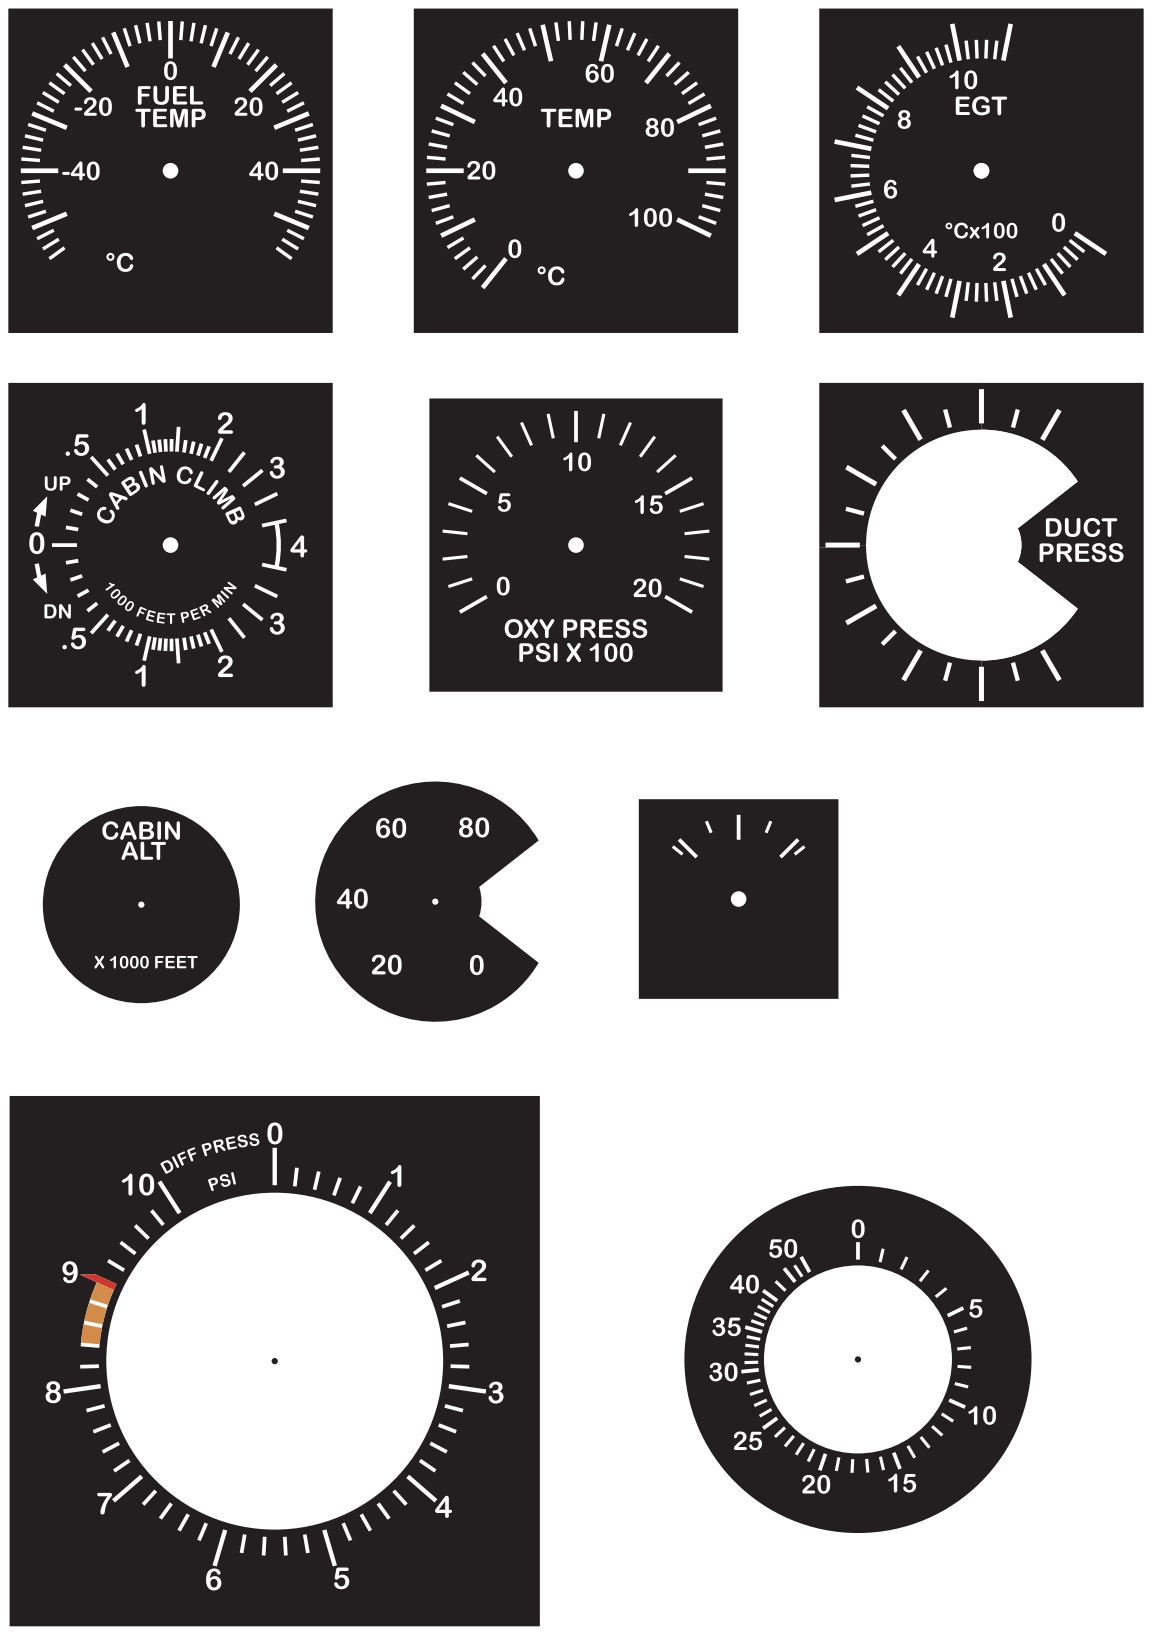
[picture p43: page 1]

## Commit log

2026-08-21 Restructure documentation and add system overview
    Split the 244-line README into a landing page plus topic documents
    under docs/, and document how the panel connects to the simulator.
    - Add docs/system-overview.md with the MSFS 2020 / PMDG 737-800 /
    MobiFlight setup, the 7x Arduino Mini Mega 2560 boards and the
    internal USB hub, including the system diagram
    - Move PCB documentation into docs/pcb/ (one file per board) with a
    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
2026-08-21 Sort images into subfolders and document the power supply
    - Move images into images/photos, images/pcb, images/parts and
    images/uv; update every reference accordingly
    - Document the external power supply: 12 V for the backlighting,
    5 V for the rest of the electronics
    - Correct the intro, which implied the panel was USB-powered
2026-08-21 Remove duplicate PCB_annunciator.png
    Byte-identical copy of images/pcb/PCB_Annunciator.png. The PCB folder
    now contains only the Gerber archives.
2026-08-21 Make clear the PCB list is not final, announce MobiFlight files
    - Remove the unused PCB_Annunciator_schematic_D.png
    - State in both README and the PCB documentation that further PCB
    designs will follow, so the current four are not mistaken for the
    complete set
    - Announce that the MobiFlight configuration files will be published
2026-08-21 Correct the power supply: two separate units, not one
    The panel uses two independent external supplies - one 12 V for the
    backlighting and one 5 V for the electronics.
2026-08-21 Identify the boards correctly as MEGA 2560 PRO MINI clones
    They are third-party ATmega2560 boards from AliExpress, not genuine
    Arduino products. Add a section explaining what they are and why the
    PRO MINI form factor was chosen.
2026-08-21 Drop the incorrect price rationale for using seven boards
    Seven boards are used because a single Mega 2560 does not have enough
    I/O pins, which the Why seven boards section already explains. Price
    was not a factor in that decision.
2026-08-21 Document the Anti-ice Panel
    Add build notes for panel 9, covering the filament, printed parts,
    switches, screws, annunciators, PCBs and backlight, plus the five
    assembly diagrams.
    Also rename the annunciator LED colour from orange to yellow in the
    LED driver resistor table, so it matches the annunciator BOM.
2026-08-21 Fold the shared-parts section into Annunciators
    The separate "Parts from Other Models" section duplicated what the
    Annunciators section already said. Point straight from there to the
    MakerWorld model, the build notes and the PCB documentation instead.
    Add a stub page for the Annunciators model so the link resolves.
2026-08-21 Add photos to the panel pages
    Open every panel page with photos of the finished build. The Anti-ice
    Panel gets four: the finished panel, the printed top panel, the fitted
    diffuser and the rear side with the PCBs.
    Also align the Door Warning Panel page with the section structure the
    Anti-ice Panel established.
2026-08-21 Document the channel allocation and shrink oversized images
    - Explain why the panel needs two boards: ten LED channels, eight of
    them for the four dual-brightness annunciators
    - Resize every image wider than 1600 px down to 1600 px and strip its
    metadata, leaving the three full-resolution project photos untouched
2026-08-21 Remove the channel allocation section
    The real wiring is more involved than the diagram suggests; this will
    be documented properly later.
2026-08-21 Document the Door Warning Panel
    Add build notes for panel 6: filament, printed parts, screws, the
    twelve annunciators with their legends, the two LED driver boards and
    the two assembly diagrams.
    The photos are stored as JPEG rather than PNG, which cuts them from
    2.2 MB to 300 kB.
2026-08-21 Update the bottom panel diagram and convert the anti-ice photos to JPEG
    - Replace the Door Warning bottom panel diagram with the corrected
    version, which labels the part Standoff instead of Spacer
    - Drop the annunciator legend layout from the Door Warning page
    - Store the four Anti-ice photos as JPEG, cutting them from 5.0 MB
    to 860 kB
2026-08-21 Replace the Anti-ice front photo with the cropped version
    The new photo is framed to the panel itself instead of surrounding it
    with white background.
2026-08-21 Separate the frame and shared components from the panels
    Main Frame, Annunciators and Rotary Knobs are not panels: the frame
    carries the whole overhead and the other two are reused across many
    panels. Split the index into two tables and rename the section from
    Panels to Models, which is what MakerWorld calls them.
    The docs/panels directory becomes docs/models to match.
2026-08-23 Add Window and Probe Heat Panel build notes
    Documents model 8: filament, printed parts, switches, screws,
    annunciators, PCBs, backlight and the five assembly steps.
    Adds the four panel photos and the five assembly diagrams, and
    links the page with a thumbnail from the model list.
2026-08-23 Correct the second LED driver to headers 1-8
    Both RJ45 LED Driver boards use headers 1-8, not 1-5. The two PCB
    rows are now identical, so they are merged into a single 2x row.
    Replaces the assembly diagram with the corrected render.
2026-08-23 Add Generator Drive and Standby Power Panel build notes
    Documents model 7: filament, printed parts, switches with their
    safety guards, screws, annunciators, PCB, backlight and the four
    assembly steps. Adds the five panel photos and the four assembly
    diagrams, and links the page with a thumbnail from the model list.
2026-08-23 Replace the PCB assembly diagram with the corrected render
2026-08-23 Add Flight Control Panel build notes
    Documents model 5: filament, printed parts, switches with their
    safety guards, screws, annunciators, the four PCBs, backlight and
    the four assembly steps. Adds the five panel photos and the four
    assembly diagrams, and links the page with a thumbnail from the
    model list.
2026-08-23 Relabel the bottom panel diagram from Spacer to Standoff
    Matches the wording used on the other panel diagrams and in the
    screw tables.
2026-08-24 Add build notes for the Hydraulic Control Panel
    Document panel 10: filament, printed parts, switches, screws,
    annunciators, PCBs and backlight, plus the five-step assembly
    diagram. Link the page from the model list.
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2026-08-24 Add build notes for the Navigation Panel
    Document panel 4: filament, printed parts, switches, screws, PCBs
    and backlight, plus the four-step assembly diagram. Replace the
    placeholder in the model list with a thumbnail and a link.
2026-08-24 Add the pin ranges and a placeholder page for the rotary knobs
    Replace the PCB diagram with the corrected render that labels the
    pins, and split the PCB table into one row per board. Add a
    placeholder build notes page for the rotary knobs and link it from
    the panel and the model list.
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2026-08-25 docs: correct the annunciator and LED quantities
    Counting the annunciators on the overhead photo gives 93 yellow, not 94,
    which makes the type table add up to the 121 printed sets and PCBs. The
    two large special annunciators carry one yellow and one white LED each,
    so the BOM needs 95 yellow, 9 green and 21 white LEDs.
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2026-08-25 docs: use the cut-out photo of the MEGA 2560 PRO MINI
    Replace the mega photo with the background-removed version, kept as a
    PNG so the transparency survives.
2026-08-25 docs: use the cut-out photo of the assembled shield
    Replace the assembled-shield photo with the background-removed version,
    kept as a PNG so both assembly photos read the same in either theme.
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2026-08-25 docs: the MobiFlight configuration is complete, not a running snapshot
    It covers the whole overhead, including panels whose models are not
    published yet, and does not grow as further models are released.
    Also corrects the note about the 22 configurations with no board: they
    are deliberate, not unfinished. Sixteen turn a variable into the two
    PMDG events a guarded switch needs, six feed a servo or the IRS display
    through a config reference. Those sixteen carry input actions of their
    own, so the action counts now include them.
2026-08-25 Revert "fix: restore the mfproj exactly as MobiFlight wrote it"
    The project opens fine with the relative path — the error came from
    starting MobiFlight without the simulator running, not from the file.
    This reverts commit 014ce11.
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2026-08-25 docs: headers 1 and 2 on the Combined PCB should not be fitted
    They are soldered on in the rear photo, which is a mistake in that
    build. Saying only "not populated" contradicted the picture; say
    plainly that the photo is wrong and leave them off.
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2026-08-25 docs: point the TAT TEST note at the wire in the photo
    The cross-panel connection is visible as the loose white wire leaving
    the panel, so say which wire it is.
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2026-08-25 docs: fix the PCB labels and the ground returns on the Navigation Panel wiring
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2026-08-26 docs: add the IRS Keyboard Gerber files and correct the LED assembly note
    The LED is soldered into the board through the holes in the switch body, and
    its polarity has to be checked before soldering.
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2026-08-26 docs: label the two keyboard RJ45 sockets on the IRS Display Unit wiring
    Adds the MakerWorld link and replaces the single PCB 2 marker with RJ45 2
    (socket A2) and RJ45 3 (socket A1), since both sockets are on the same board.
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2026-08-26 docs: correct the LED colour in the Landing Gear annunciator diagram
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2026-08-28 docs: publish the LE Devices Gerber and rework its photos
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2026-08-29 docs: refresh the LE Devices panel photos and correct the PCB screw head
2026-08-29 docs: replace the LE Devices PCB mounting photo
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2026-08-29 docs: correct the LE Devices PCB screws to M3x8
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2026-08-29 docs: swap assembly steps 2 and 3 on the LE Devices panel
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2026-08-30 docs: re-export the Center Lower Panel PCB diagram with pins 5-7
    Marek corrected the drawing, so the sentence explaining the mismatch
    is gone. New file name to break GitHub's image cache.
    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
2026-08-30 docs: say why the Combined PCB carries a four-way screw terminal
    The photo and the diagram both show it reaching pin 8; a three-way
    terminal is enough. Same first-person wording as the Anti-ice Panel
    note about the two headers soldered on by mistake.
    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
2026-09-02 docs: Marek's corrections to the Gauge page
    - servo plug: swap red and yellow, brown/yellow/red is the order the
    RJ45 Direct PCB needs
    - splice connectors: their placement is free, both on the gauge is fine
    - say why the photo shows two resistors instead of one 150 R
    - drop the rear-side photo and renumber the remaining two
    - cut two sentences he did not want
    Claude-Session: https://claude.ai/code/session_01V96hGiKD3ynMVrCM24adxY
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2026-09-02 docs: add the CNC Cut Files chapter
    Five acrylic cuts, nine pieces: four round gauge windows and the
    window of the AC and DC Meter Panel. DXF files, previews drawn to a
    common scale, material and cutting notes.
    Claude-Session: https://claude.ai/code/session_011CQxe3rDY2EngHGjJNttqV
    [cnc_gauge_29-8.dxf, cnc_gauge_43-8.dxf, cnc_gauge_48-8.dxf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]
2026-09-02 docs: drop the cutter offset sentence from CNC Cut Files
    It said every outline is the edge of the piece and the cutter runs
    outside it, which is wrong for the two holes in the 29.8 window.
    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
2026-09-02 docs: one download per CNC drawing instead of a shared ZIP
    Each row now links its own file. The drawings are still zipped, since
    GitHub serves a bare .dxf as text rather than saving it.
    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
    [cnc_gauge_29-8.dxf, cnc_gauge_43-8.dxf, cnc_gauge_48-8.dxf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]
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2026-09-04 docs: fix the broken step anchors in the model pages
    A heading like "3. Backlight panel - PCBs and DC jack" slugs to
    #3-backlight-panel---pcbs-and-dc-jack: GitHub drops the full stop and turns
    each of the three characters of " - " into a hyphen. All 14 step links wrote
    two hyphens instead of three, so none of them jumped anywhere.
    Claude-Session: https://claude.ai/code/session_0145JoJrxJUKET2pnSF93GLk
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2026-09-04 docs: re-exported step 1 diagram and three corrections
    Step 1 now shows the SR16 crossfeed switch; new file name so the old image
    does not come back out of the cache.
    The bezel is part of this model, the acrylic window is not - that one is cut,
    not printed. The crossfeed selector uses two opposite contacts of the SR16, so
    it stays closed through a further half turn. The rear photo caption says which
    half of the panel each of the two boards under the gauge serves, and that the
    view from behind reverses the sides.
    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
2026-09-04 docs: note the broken end stop on the CROSS FEED selector
    Turning the SR16 hard past its stop breaks the stop off inside and leaves a
    switch that turns continuously - the same trick as on the AC and DC Meter
    Panel. Also shortens the rear photo caption again.
    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
2026-09-10 docs: corrections to the Air Conditioning Control Panel page
    Screw table back to the MakerWorld BOM, re-exported step 1 diagram
    without the guard, AliExpress references for the potentiometer and the
    Dupont lead, and the wiring photo no longer crops off the pair of wires
    that runs to the Voice Recorder Switch.
    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
2026-09-10 docs: fix the PCB labels and two sentences on the panel 24 wiring section
    The label text sat outside its yellow box: with -gravity set, an
    ImageMagick draw text takes the bounding box origin, not the baseline.
    Also reworded the rear photo caption and the potentiometer connection.
    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
2026-09-10 docs: add the MakerWorld link for model 25 and soften the page 11 note
    Page 11 no longer claims to be the only unlit panel with text - it just
    says it is not backlit, as on the real overhead. The Pressurization
    Altitude Info plate had made the exclusive claim awkward.
    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
2026-09-15 Add the assembly diagrams to the Interphone and Dome Panel
    Five steps. The diagrams also correct the screw count: the top panel takes
    two DH M3x8 of its own, so the panel needs six, not the four the MakerWorld
    BOM lists.
    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
2026-09-15 Give the real reason the oxygen gauge hangs off this panel
    The PCBs on the Engine and Oxygen Panel are fully taken; the Recorder and
    Stall Panel had nothing to do with it.
    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
2026-09-15 Add the Recorder and Stall Panel (panel 28)
    Two bottom panels joined by the connection, which also carries both PCBs.
    RJ45 Direct on socket D0 of Overhead_3 (pins 1-5, the four test buttons and
    the FLIGHT RECORDER switch) and RJ45 LED Driver on socket D6 of Overhead_5
    (header 8, the OFF annunciator).
    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
2026-09-15 Add Engine and Oxygen Panel page (model 30)
    Front: two REVERSER and two ENGINE CONTROL annunciators, the two large
    special EEC annunciators, the CREW OXYGEN pressure gauge and the guarded
    PASS OXYGEN switch.
    Wiring - two patch cables on two different MEGAs. PCB 1 = RJ45 LED Driver
    on socket D3 of Overhead_2a, headers 1-8; headers 1, 7 and 8 drive the
    Landing Gear Indicator Panel, which closes the reciprocal note page 16 was
    owed. PCB 2 = RJ45 Combined on socket D3 of Overhead_2b, headers 1-4 for
    the EEC ON/ALTN lamps, pins 5, 7 and 8 for the PASS OXYGEN switch and the
    two EEC buttons. Its `-` Faston is replaced by a two-way screw terminal so
    that the switch wire and the special annunciators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
2026-09-15 Reword the PCB caption on page 30
    "the board with the eight ZH headers and nothing else on it" was wrong -
    that board also carries the RJ45, the ULN2803 and its resistors, and the
    Combined board has ZH headers too. The boards are told apart by the screw
    terminals instead.
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2026-09-17 Fix the L WIPER LOW/INT labels and pin rows
    The MobiFlight config items on D5_2 and D5_3 carried each other's names;
    their PMDG params were right (pin 2 = LOW, pin 3 = INT), so the sim was
    never affected. Relabelled them in Overhead.mfproj, rebuilt the zip, and
    corrected the Generator Bus Panel wiring table, which had followed the
    wrong labels. Both wipers now read 1 HIGH, 2 LOW, 3 INT, 4 PARK.
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2026-09-20 Cabin Alt / Diff Press Gauge: shorten the LED strip step
2026-09-21 Cabin Alt / Diff Press Gauge: photos of the finished gauge
    Replace the CAD render with Marek's two photos - front and rear - and
    give the model list its own thumbnail. The render is no longer used.
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2026-09-21 Outflow Valve Gauge: use the full studio photo as the list thumbnail
    The tight crop is dropped - the model list now shows the same photo the
    page opens with, framed the way the rest of the studio shots are.
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2026-09-24 Right Light Panel: corrected assembly renders and the standoff screws
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2026-09-30 Engine Start Switch: note on a servo arm that is too long
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2026-09-30 Engine Start Switch: fix the broken line after the warning title
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2026-10-14 Replace en dashes with plain hyphens in all docs
    Number ranges (pins 1-8, D0-D6, 12-24 V) and the README title now use the
    same hyphen as the newer pages (31 and up).
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2026-10-14 Revert "Wiring sections: cut sentences that restate the tables"
    This reverts commit 07ca6b83efa06e8b0b343c296ceb00c19ffb9efb.
2026-10-14 Navigation Panel: shorter Wiring intro, same wording as pages 32 and 34
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2026-10-14 Bill of Materials: product screenshots for the parts listed in the System Overview
    Its links start with ../ instead of ../../, which the generator missed:
    MEGA 2560 PRO MINI, USB hub, USB cable.
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2026-10-19 Annunciator PCB: replace standard wiring photo
2026-10-19 Annunciator PCB: replace dual brightness wiring photo
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2026-10-19 RJ45 Direct: corrected schematic, add Schematic column to BOM
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2026-10-21 Flight Control Panel: shorten the PCB 1 rotation note
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2026-10-24 RJ45 Combined PCB: shorter resistor description in the BOM
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2026-10-24 RJ45 Combined PCB: 17 Faston terminals for all 6 PCBs
    On the Engine and Oxygen Panel board the 2P black screw terminal replaces the - Faston. Bill of materials: Faston 159x.
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2026-10-24 Bill of materials: shorter hookup wire rows so the table does not wrap
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2026-10-24 ZH header and cable counted once, as one set
    Bill of materials: one item 'ZH 1.5 set' 134x replaces the separate header and cable items. LED Driver, Combined and IRS Keyboard pages say the header comes with the cable in the ZH set.
2026-10-24 PCB BOMs: shorter ZH header row so the tables stay on one line
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2026-10-24 Revert "Female Fastons: 6.3 mm with sheath, 333x"
    This reverts commit 5d6c5fb207f9a67ab707f856797eb562bd8d1c21.
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2026-10-24 Bill of materials: list finished - work-in-progress box replaced by a note
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2026-10-24 Fuel Control Panel: right SPAR VALVE CLOSED is bright on header 2, dim on header 7
    Overhead.mfproj: the '(right)-dim' config moves from D0_2 to D0_7 on Overhead_1b (Marek's corrected project; only that change taken over, not the runtime values). Zip rebuilt.
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
